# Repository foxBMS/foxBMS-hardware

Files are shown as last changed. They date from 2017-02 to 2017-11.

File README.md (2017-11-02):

# foxBMS

foxBMS is a free, open and flexible development environment to design battery
management systems. It is the first modular open source BMS development
platform.

## foxBMS Project Setup
The foxBMS project consists of several repositories.

The foxConda-installer repository contains the installer for the foxConda
environment. This environment provides all the tools necessary to generate the
documentation, compile the code for the MCUs and flash the generated binaries on
the MCUs (e.g., Python, git, GCC).

The starting point to get foxBMS is the foxBMS-setup
repository (https://github.com/foxBMS/foxBMS-setup), which contains
the general setup files for the foxBMS project. It includes a setup script
(bootstrap.py) which clones all the other needed repositories. The needed
documentation will be generated automatically after these repositories have been
cloned. The generated documentation is found in the directory ./build.
After the bootstrap step, the top project directory (foxBMS-setup) structure
looks like this:

 - foxBMS-setup <dir>
  - .git <dir> *
  - build <dir>
  - foxBMS-documentation <dir>
  - foxBMS-hardware <dir>
  - foxBMS-primary <dir>
  - foxBMS-secondary <dir>
  - foxBMS-tools <dir>
  - FreeRTOS <dir>
  - hal <dir>
  - .gitignore <file> *
  - bootstrap.py <file>
  - build.py <file>
  - CHANGELOG.md <file>
  - clean.py <file>
  - LICENSE.md <file>
  - README.md <file>
  - wscript <file>

* Directories and files with starting full stop are hidden in Windows in default
configuration.

There is a help available by running "python bootstrap.py -h".

## foxBMS Repositories

The foxConda-installer and foxBMS-setup repositories have already been described.

foxBMS is made out of two Microcontroller Units (MCU), named primary and
secondary. The C code for the primary MCU is found in the repository
foxBMS-primary (https://github.com/foxBMS/foxBMS-primary). The C code for the
secondary MCU is found in the repository foxBMS-secondary
(https://github.com/foxBMS/foxBMS-secondary). The Doxygen documentation is
generated from these sources into ./build/primary/doxygen/html and
./build/secondary/doxygen/html respectively. The main file is in both cases
index.html.

The layout and schematic files for the foxBMS hardware are found in the
foxBMS-hardware repository (https://github.com/foxBMS/foxBMS-hardware).

The Hardware Abstraction Layer (hal) for foxBMS is found in the hal-repository
(https://github.com/foxBMS/hal.) The real time operating system (FreeRTOS) for
foxBMS is found in the FreeRTOS-repository (https://github.com/foxBMS/FreeRTOS.)

The tools needed for foxBMS are in the foxBMS-tools-repository
(https://github.com/foxBMS/foxBMS-tools.)

The general documentation files for the foxBMS project are found in the
foxBMS-documentation repository
(https://github.com/foxBMS/foxBMS-documentation). The sphinx documentation is
found in foxBMS-documentation/doc/sphinx while the Doxygen documentation
configuration is found in foxBMS-documentation/doc/doxygen. The Doxygen
documentation itself is found in the software sources of the primary and
secondary microcontroller. The general documentation, rendered from the sphinx
sources is found in ./build/sphinx/foxBMS-documentation/doc/sphinx/html. The
main file is index.html

A generated version of the Sphinx documentation can be found at
http://foxbms.readthedocs.io/. It explains the structure of the
foxBMS hardware, how to install the foxConda environment and how to use foxConda
to compile and flash the sources.

## Building the Sources
For building the software, open a shell and type "python build.py -h". All
available build options will be displayed. The top build directory is ./build.

## Cleaning the ./build-Directory
For cleaning instructions open a shell and type "python clean.py -h". All
available cleaning options will be displayed.

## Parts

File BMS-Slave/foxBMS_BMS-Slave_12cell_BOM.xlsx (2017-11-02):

Pos. | Qty | Device | Package | Parts | Description | Farnell | Digi-Key
 | Resistors
1 | 12 | 0,00R_0603_R_VISHAY_REV_01 | R_SMD_0603_R_VISHAY_REV01 | R210, R212, R214, R216, R218, R220, R310, R312, R314, R316, R318, R320 | 0,00R SMD - CHIP - Dickschichtwiderstand | 1469739
2 | 2 | 1,21K_0603_R_VISHAY_1%_TK100_REV_01 | R_SMD_0603_R_VISHAY_REV01 | R208, R308 | 1,21K SMD - CHIP - Dickschichtwiderstand | 1652852
3 | 36 | 10,0K_0603_R_VISHAY_1%_TK100_REV_01 | R_SMD_0603_R_VISHAY_REV01 | R813, R901, R902, R903, R904, R905, R906, R907, R908, R1001, R1002, R1003, R1004, R1005, R1006, R1007, R1008, R1101, R1102, R1103, R1104, R1105, R1106, R1107, R1108, R1201, R1202, R1203, R1204, R1205, R1206, R1207, R1208, R1301, R1401, R1606 | 10,0K SMD - CHIP - Dickschichtwiderstand | 1469748
4 | 4 | 100R_0805_R_VISHAY_1%_TK100_REV_01 | R_SMD_0805_R_VISHAY_REV01 | R202, R203, R302, R303 | 100R SMD - CHIP - Dickschichtwiderstand | 1469862
5 | 30 | 100R_0603_R_VISHAY_1%_TK100_REV_01 | R_SMD_0603_R_VISHAY_REV01 | R501, R502, R503, R504, R505, R506, R507, R508, R509, R510, R511, R512, R513, R601, R602, R603, R604, R605, R606, R607, R608, R609, R610, R611, R612, R613, R909, R910, R1009, R1010 | 100R SMD - CHIP - Dickschichtwiderstand | 1469752
6 | 4 | 120R_0603_R_VISHAY_1%_TK100_REV_01 | R_SMD_0603_R_VISHAY_REV01 | R204, R207, R304, R307 | 120R SMD - CHIP - Dickschichtwiderstand | 1652832
7 | 12 | 150R_0603_R_VISHAY_1%_TK100_REV_01 | R_SMD_0603_R_VISHAY_REV01 | R801, R802, R803, R804, R805, R806, R807, R808, R809, R810, R811, R812 | 150R SMD - CHIP - Dickschichtwiderstand | 1469760
8 | 2 | 1,00M_0603_R_VISHAY_1%_TK100_REV_01 | R_SMD_0603_R_VISHAY_REV01 | R219, R319 | 1,00M SMD - CHIP - Dickschichtwiderstand | 1469746
9 | 2 | 330R_0603_R_VISHAY_1%_TK100_REV_01 | R_SMD_0603_R_VISHAY_REV01 | R205, R305 | 330R SMD - CHIP - Dickschichtwiderstand | 2141320
10 | 12 | 3,30K_0603_R_VISHAY_1%_TK100_REV_01 | R_SMD_0603_R_VISHAY_REV01 | R713, R714, R715, R716, R717, R718, R731, R732, R733, R734, R735, R736 | 3,30K SMD - CHIP - Dickschichtwiderstand | 1469793
11 | 4 | 1,20K_0603_R_VISHAY_1%_TK100_REV_01 | R_SMD_0603_R_VISHAY_REV01 | R222, R223, R322, R323 | 1,20K SMD - CHIP - Dickschichtwiderstand | 1469741
12 | 24 | 68,0R_2010_R_YAGEO_5%_TK100_REV_01 | R_SMD_2010_R_YAGEO_REV01 | R701, R702, R703, R704, R705, R706, R707, R708, R709, R710, R711, R712, R719, R720, R721, R722, R723, R724, R725, R726, R727, R728, R729, R730 | 68,0R SMD - CHIP - Dickschichtwiderstand | 2323988
13 | 2 | 820R_0603_R_VISHAY_1%_TK100_REV_01 | R_SMD_0603_R_VISHAY_REV01 | R206, R306 | 820R SMD - CHIP - Dickschichtwiderstand | 1469841
14 | 1 | 390K_0603_R_VISHAY_1%_TK100_REV_01 | R_SMD_0603_R_VISHAY_REV01 | R1601 | 390K SMD - CHIP - Dickschichtwiderstand | 2303278
15 | 1 | 86,6K_0603_R_VISHAY_1%_TK100_REV_01 | R_SMD_0603_R_VISHAY_REV01 | R1602 | 86,6K SMD - CHIP - Dickschichtwiderstand | 2059490
16 | 1 | 39,0R_0805_R_VISHAY_1%_TK100_REV_01 | R_SMD_0805_R_VISHAY_REV01 | R1603 | 39,0R SMD - CHIP - Dickschichtwiderstand | 1750736
17 | 1 | 127K_0603_R_VISHAY_1%_TK100_REV_01 | R_SMD_0603_R_VISHAY_REV01 | R1605 | 127K SMD - CHIP - Dickschichtwiderstand | 2059500
18 | 2 | 0,00R_0805_R_VISHAY_REV_01 | R_SMD_0805_R_VISHAY_REV01 | R201, R301 | 0,00R SMD - CHIP - Dickschichtwiderstand | 2057661
 | Capacitors
19 | 4 | 100NF_0805_100V_X7R_MULTICOMP | C_SMD_0805_(2012)_R_MULTICOMP_REV01 | C201 C202 C301 C302 | 100nF Keramik-Kondensator | 2320821
20 | 18 | 100NF_0603_16V_X7R_KEMET | C_SMD_0603_(1608)_R_KEMET_REV01 | C801, C901, C1001, C1101, C1201, C1301, C1302, C1401, C1402, C1501, C1502, C1503, C1504, C1505, C1506, C1507, C1508, C1604 | 100nF Keramik-Kondensator | 2581045
21 | 4 | 100PF_0603_50V_C0G_KEMET | C_SMD_0603_(1608)_R_KEMET_REV01 | C204, C207, C304, C307 | 100pF Keramik-Kondensator | 1414603
22 | 28 | 10,0NF_0603__100V_X7R_KEMET | C_SMD_0603_(1608)_R_KEMET_REV01 | C501, C502, C503, C504, C505, C506, C513, C514, C515, C516, C517, C518, C601, C602, C603, C604, C605, C606, C613, C614, C615, C616, C617, C618, C904, C905, C1004, C1005 | 10,0nF Keramik-Kondensator | 1865545
23 | 17 | 1,00µF_0603_16V_X7R_KEMET | C_SMD_0603_(1608)_R_KEMET_REV01 | C203, C205, C206, C303, C305, C306, C902, C903, C906, C907, C908, C1002, C1003, C1006, C1007, C1008, C1605 | 1,00µF Keramik-Kondensator | 1650837
24 | 1 | 1,00µF_0805_50V_X7R_KEMET | C_SMD_0805_(2012)_R_KEMET_REV01 | C1601 | 1,00µF Keramik-Kondensator | 2118131
25 | 2 | 10µF_1210_50V_X7R | 1210 | C1602, C1603 | 10µF Keramik-Kondensator | 2449143
26 | 1 | 470PF_0805_50V_X7R_KEMET | C_SMD_0805_(2012)_R_KEMET_REV01 | C1606 | 470pF Keramik-Kondensator | 1759283
27 | 1 | 4,7NF_1812_1kV | 1812 | C1607 | 4,7nF Keramik-Kondensator | 1702159
28 | 3 | 4,70µF_1206_100V_X7R_KEMET | C_SMD_1206_(3216)_R_KEMET_REV01 | C1608, C1609, C1610 | 4,70µF Keramik-Kondensator |  | 478-8719-1-ND
 | ICs
29 | 2 | M24M02-DR | SOIC127P600X175-8N | IC1301, IC1401 | EEPROM |  | 497-16238-1-ND
30 | 3 | ACPL-247-500E | OC_SMD_SOIC-16_R_AVAGO_REV01 | IC801, IC802, IC803 | ACPL-247 - AVAGO | 1634758
31 | 2 | PCA8574TS/3 | SOP65P640X150-20N | IC1101, IC1201 | IC, I/O EXPANDER, 8BIT, I2C, 20SSOP | 1506642
32 | 6 | ADG728BRUZ | IC_SMD_TSSOP-16 | IC901, IC902, IC905, IC1001, IC1002, IC1005 | ADG728BRUZ | 9604383
33 | 4 | LTC6255CS6 | IC_SMD_TSOT-23-6_(S6)_R_LINEAR_REV01 | IC903, IC904, IC1003, IC1004 | LTC6255 Serie - Linear |  | LTC6255CS6#TRMPBFCT-ND
34 | 2 | MCP9800A0T-M/OT | SOT95P280X145-5N | IC1302 IC1402 | Temperature Sensor | 1439485
35 | 2 | 0_LES_BATTERIE-MANAGEMENT.SMD_LTC6811HG-1 | 0_LES_BATTERIE-MANAGEMENT.SMD_IC_SMD_SSOP-48_(G48)_R_LINEAR_REV01 | IC201 IC301 | LTC6811-1 - Linear Technology |  | LTC6811HG-1#PBF-ND
36 | 1 | LT8302 | S8E | IC1601 | LT8302 | 2366012
 | Diodes
37 | 24 | MMSZ4692_T1G | D_SMD_SOD-123_R_ON_REV01 | Z501, Z502, Z503, Z504, Z505, Z506, Z507, Z508, Z509, Z510, Z511, Z512, Z601, Z602, Z603, Z604, Z605, Z606, Z607, Z608, Z609, Z610, Z611, Z612 | MMSZ4xxxT1G Serie - ON Semiconductor | 2463562
38 | 1 | BAT54C | D_SMD_SOT23_(TO-236AB)_R_NXP_REV01 | D801 |  | 1081192
39 | 2 | LEDCHIP-LED0603 | CHIP-LED0603 | LD201 LD301 | LED | 2099223
40 | 2 | SMAJ60CA_VISHAY | D_SMD_SMA_(DO-214AC)_(BIDIR)_R_VISHAY_REV01 | D202, D302 | SMAJ bi-directional Transient Voltage Suppressors | 1837055
41 | 1 | DI_PDS3200 | POWER_DI_5 | D1604 | Schottky Diode | 1713904
42 | 1 | MMSZ5263B | SOD123 | D1605 | Zener Diode |  | MMSZ5263BT1GOSCT-ND
43 | 3 | DI_DFLS1100 | POWER_DI_123 | D201, D301, D1601 | Schottky Diode | 1713889
 | Transistors
44 | 12 | NX2301P,215 | D_SMD_SOT23_(TO-236AB)_R_NXP_REV01 | T701, T702, T703, T704, T705, T706, T707, T708, T709, T710, T711, T712 | NX2301P - NXP | 1894738
45 | 2 | PBHV8115Z | D_SMD_SOT223_(SC-73)_R_NXP_REV01 | T201 T301 | PBHV8115Z - NXP | 1829309
 | Misc
46 | 2 | Pulse HM2102NL | HM2102NL | TR201, TR301 | HM2102NL
47 | 1 | WE_750313457 | WUERTH_CUSTOM | TR1601 | WE_750313457 Flyback Transformer |  | 1297-1136-1-ND
48 | 6 | CUSTOM_PAD_PAD_2.0X1.5MM | CUSTOM_PAD_PAD2.0X1.5MM | TP206, TP209, TP210, TP306, TP309, TP310 | Harwin SMD Test Points |  | 952-2664-1-ND
49 | 13 | 0,250A_LITTELFUSE_466_1206 | R_SMD_CHIP_1206_R_LITTLEFUSE_REV_01 | F402, F403, F404, F405, F406, F407, F408, F409, F410, F411, F412, F413, F414 | LITTELFUSE 0466.250NR SICHERUNG, 0.25A | 9921826
50 | 2 | 0,500A_LITTELFUSE_448 | 448_SERIES_LITTELFUSE | F401 F415 | LITTELFUSE 0448.500MR SICHERUNG, 500MA | 1596919
51 | 1 | 1,25A_LITTELFUSE_466_1206 | 1,25A_LITTELFUSE_466_1206 | R_SMD_CHIP_1206_R_LITTLEFUSE_REV_01 | F1601 | 1596526
52 | 1 | WE-74404042100 | WE-LQS | L1601 | Inductor | 2431496
 | Connectors
53 | 6 | 43045-0200_MOLEX_2PIN | X_TH_MOLEX_43045-0200_R_REV01 | X1509, X1510, X1511, X1512, X1513, X1514 | 43045-Serie - MOLEX | 1012251
54 | 2 | 43045-1600_MOLEX_16PIN | X_TH_MOLEX_43045-1600_R_REV01 | X1506 X1507 | 43045-Serie - MOLEX | 9961380
55 | 1 | 43045-2400_MOLEX_24PIN | X_TH_MOLEX_43045-2400_R_REV01 | X1503 | 43045-Serie - MOLEX | 1012245
56 | 2 | MA05-2 | MA05-2 | X1504, X1505 | PIN HEADER | 2578720
57 | 2 | MA09-2 | MA09-2 | X1501, X1502 | PIN HEADER | 2025256
58 | 1 | MA10-2 | MA10-2 | X1508 | PIN HEADER | 2025257
59 | 1 | MA02-2 | MA02-2 | X1515 | PIN HEADER | 2025248

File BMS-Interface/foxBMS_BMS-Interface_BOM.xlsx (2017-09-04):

Populate | Qty | Value | Device | Package | Parts | Description | Farnell | Digikey | Mouser
no | 2 |  | HEADER_POS4_43045-0406 | 43045-0406 | X1, X2 | Molex - Micro-Fit 3.0 Series connector, 3.00mm (0.118) pitch header, 4 positions." | 2063766
yes | 2 |  | SSW-104-01-G-D | 2x 04 | X5, X6 | PIN HEADER | 1668340
yes | 2 |  | SSW-102-01-G-D | 2x 02 | X3, X4 | PIN HEADER | 1668329
yes | 4 | 100n | C_0603 | 603 | C301, C302, C401, C402 | Capacitor | 1828890
yes | 8 | 0R | R_0603 | 603 | R302, R304, R305, R310, R402, R404, R405, R410 | Resistor | 2059527
yes | 2 | 1.21k | R_0603 | 603 | R312, R412 | Resistor | 2059331
yes | 2 | 120 | R_0603 | 603 | R501, R502 | Resistor | 2303067
yes | 2 | 27pF | C_0603 | 603 | C502, C504 | Capacitor | 1414627
yes | 4 | 2k | R_0603 | 603 | R307, R308, R407, R408 | Resistor | 2059343
yes | 2 | 806 | R_0603 | 603 | R311, R411 | Resistor | 2059324
yes | 2 | HM2102NL | HM2102NL | HM2102NL | T501, T502
yes | 2 | LTC6820 | LTC6820 | MSOP16 | IC301, IC401 |  |  | LTC6820HMS#PBF-ND
no | 8 | OPT: 0R | R_0603 | 603 | R301, R303, R306, R309, R401, R403, R406, R409 | Resistor | 2059527

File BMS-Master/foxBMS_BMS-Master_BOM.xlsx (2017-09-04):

 | Pos | Populate | Qty | Value | Device | Package | Parts | Description | Farnell | Digikey | Mouser
Resistor
 | 1 | yes | 9 | 0 | R-EU_R0603 | R0603 | R403 R406 R501 R506 R705 R1403 R1404 R1407 R1408 | RESISTOR, European symbol | 2059527
 | 2 | yes | 2 | 1.5k | R-EU_R0603 | R0603 | R701 R702 | RESISTOR, European symbol | 2303156
 | 3 | yes | 12 | 10 | R-EU_R0603 | R0603 | R706 R901 R905 R909 R912 R1001 R1002 R1007 R1008 R1013 R1014 R806 | RESISTOR, European symbol | 2302958
 | 4 | yes | 32 | 10k | R-EU_R0603 | R0603 | R401 R402 R405 R407 R502 R504 R505 R507 R707 R708 R709 R710 R903 R904 R908 R911 R1003 R1004 R1009 R1010 R1015 R1016 R1107 R1108 R1109 R1110 R1111 R1112 R1501 R1502 R803 R805 | RESISTOR, European symbol | 2303192
 | 5 | yes | 1 | 120 | R-EU_R0603 | R0603 | R902 | RESISTOR, European symbol | 2303067
 | 6 | yes | 6 | 130 | R-EU_R0603 | R0603 | R201 R301 R408 R409 R508 R509 | RESISTOR, European symbol | 2059288
 | 7 | yes | 8 | 430 | R-EU_R0603 | R0603 | R907 R910 R1005 R1006 R1011 R1012 R1017 R1018 R804 | RESISTOR, European symbol | 2145386
 | 8 | yes | 1 | 330 | R-EU_R0603 | R0603 | R906 | RESISTOR, European symbol | 2145370
 | 9 | yes | 4 | 27 | R-EU_R0603 | R0603 | R1401 R1402 R1405 R1406 | RESISTOR, European symbol | 2145363
 | 10 | yes | 6 | 47 | R-EU_R0603 | R0603 | R1101 R1102 R1103 R1104 R1105 R1106 | RESISTOR, European symbol | 2145397
 | 11 | yes | 2 | 62 | R-EU_R0603 | R0603 | R801 R802 | RESISTOR, European symbol | 2303039
 | 12 | yes | 4 | 680 | R-EU_R0603 | R0603 | R404 R503 R703 R704 | RESISTOR, European symbol | 2303131
Capacitor
 | 13 | yes | 74 | 100n | C-EUC0603 | C0603 | C202 C206 C208 C301 C306 C308 C401 C404 C405 C406 C407 C408 C409 C410 C411 C412 C413 C415 C416 C417 C418 C419 C420 C421 C422 C424 C425 C430 C502 C503 C504 C506 C507 C508 C509 C510 C513 C601 C602 C703 C706 C707 C1103 C1104 C1105 C1106 C1107 C1402 C1403 C1404 C1405 C1407 C1408 C1409 C1410 C1601 C1602 C1603 C1604 C1801 C1802 C1803 C1804 C1805 C1806 C1807 C2101 C2102 C803 C804 C805 C806 C807 C1501 | CAPACITOR, European symbol | 1828890
 | 14 | yes | 4 | 100n 50V | C-EUC0604 | C0603 | C702 C802 C902 C1102 | CAPACITOR, European symbol | 2346967
 | 15 | yes | 8 | 18p | C-EUC0605 | C0603 | C402 C414 C428 C429 C501 C505 C704 C705 | CAPACITOR, European symbol | 2070403
 | 16 | yes | 6 | 1µ | C-EUC0606 | C0603 | C205 C207 C305 C307 C403 C423 | CAPACITOR, European symbol | 1907343
 | 17 | yes | 3 | 1µ 35V | C-EUC0607 | C0603 | C701 C801 C1101 | CAPACITOR, European symbol | 2346909
 | 18 | yes | 4 | 2.2µ | C-EUC0608 | C0603 | C426 C427 C511 C512 | CAPACITOR, European symbol | 2346961
 | 19 | yes | 7 | 2.2µ 50V | C-EUC0609 | C0805 | C201 C203 C204 C302 C303 C304 C901 | CAPACITOR, European symbol | 2346945
 | 20 | yes | 2 | 4.7µ | C-EUC0610 | C0603 | C1401 C1406 | CAPACITOR, European symbol | 2362098
L
 | 21 | yes | 1 |  | L0805 | 0805 | L401 |  | 2443249
 | 22 | yes | 1 |  | B82789N | B82789N | L801 |  |  |  | 871-B82789C513N2
LED
 | 23 | yes | 2 | Green | LEDCHIP-LED0603 | CHIP-LED0603 | LED402 LED502 | LED | 2099223
 | 24 | yes | 2 | Red | LEDCHIP-LED0603 | CHIP-LED0603 | LED401 LED501 | LED | 2099221
 | 25 | yes | 2 | Orange | LEDCHIP-LED0603 | CHIP-LED0603 | LED201 LED301 | LED | 2099222
XTAL
 | 26 | yes | 2 | 7B-8.000MAAJ-T | 7B-8.000MAAJ-T | MJ | Q401 Q501 | MJ Quarz, 5 x 3.2 x 1.0mm SMD | 2308726
 | 27 | yes | 1 |  | MS3V | MS3V-T1R | Q402 |  | 1539368
Transistor
 | 28 | yes | 2 | BSS84P | BSS84P | SOT23 | T401 T501 | #2245 | 1056526
 | 29 | yes | 1 | BUK964R8-60E | BUK964R8-60E | TO-263AB | T901 | #2797 N-Channel PowerTrench MOSFET 60V, 75A 10.5mOhm | 2254205
 | 30 | yes | 10 | IRLML0100TRPBF | IRLML0100TRPBF | SOT-23 | T701 T801 T902 T903 T1001 T1002 T1003 T1004 T1005 T1006 |  | 1783928
IC
 | 31 | yes | 1 | ADR3425 | ADR3425 | SOT23-6 | IC401 | Micropower, high accuracy, voltage references | 2377039
 | 32 | yes | 2 | ADUM3300 | ADUM3300 | SO-16W | IC1102 IC1103 | Triple-Channel Digital Isolators | 2409432
 | 33 | yes | 1 | ADUM3301 | ADUM3301 | SO-16W | IC702 | Triple-Channel Digital Isolators | 2462515
 | 34 | yes | 3 | ADUM3401 | ADUM3401 | SO16W | IC601 IC1403 IC1406 | Analog Devices Magnetkoppler 4-Kanal | 1274129
 | 35 | yes | 2 | FT231XS-R | FT231XS-R | IC_SMD_SSOP-20 | IC1402 IC1405 | FT231X?-* - FTDI | 2081328
 | 36 | yes | 1 | AT25128B-SSHL-T | AT25128B-SSHL-T | SO8 | IC1501 | SPI bus serial EEPROM | 2345601
 | 37 | yes | 1 | TJA1052IT/5Y | TJA1052IT/5Y | SO16W | IC802 |  | 2400552
Diode
 | 38 | yes | 1 | PESD1CAN | PESD1CAN | SOT-23_NEU | D801 | NXP PESD1CAN CAN bus ESD protection diode | 1510703
 | 39 | yes | 1 | STPS3L60U | STPS3L60U | SMB | D201 | Schottky Diode | 9907769
 | 40 | yes | 2 | MM3Z12VT1G | MM3Z12VT1G | SOD323 | D901 D902 | MM3Z_xVx_T1 Series Zener Diode | 1431191
 | 41 | yes | 6 | CDSOD323-T05 | CDSOD323-T05 | SOD323 | D1101 D1102 D1103 D1104 D1105 D1106 | TVS CDSOD323-T05 | 2341914
 | 42 | yes | 2 | MM3Z4V7ST1G | MM3Z4V7ST1G | SOD323 | D701 D702 | MM3Z_xVx_T1 Series Zener Diode | 2463512
 | 43 | no | 6 | GF1B | GF1B | SMA-DO214AC | D1001 D1002 D1003 D1004 D1005 D1006 | DIODE | 1467477
MCU
 | 44 | yes | 1 | STM32F429IIT6 | STM32F429IIT6 | LQFP176 | IC402 | ARM 32-bit Cortex™-M3 CPU |  | 497-14054-ND
 | 45 | yes | 1 | STM32F429VIT6 | STM32F429VGT6 | LQFP100 | IC501 | ARM 32-bit Cortex™-M3 CPU | 2393659
Regulator
 | 46 | yes | 1 | KA7805ERTF | KA7805ERTF | TO252 | IC801 | Positive VOLTAGE REGULATOR | 2102585
 | 47 | yes | 2 | UA78L05CPK | UA78L05CPK | SOT89 | IC701 IC1101 | POSITOIV-VOLTAGE REGULATORS | 2112604
 | 48 | yes | 2 | LM1085-3.3 | LM1085-3.3 | TO-263-3L | IC201 IC301 | National Semiconductor LM1085IS-5 3A Low Dropout Positive Regulators | 1469039
 | 49 | yes | 1 | LM317MSTT3 | LM317MSTT3 | SOT223 | IC901 | 500 mA Adjustable Output Positive Voltage Regulator | 1703412
Opto
 | 50 | yes | 6 | AQV252G2SX | AQV252G2SX | SOP06 | IC1001 IC1002 IC1003 IC1004 IC1005 IC1006 |  |  | 255-3594-1-ND
 | 51 | yes | 5 | CPC1008N | CPC1008N | SOP4 | IC803 IC902 IC903 IC904 IC905 | CLARE - Single-Pol, Normally Open 4-Pin SOP OptoMOS Relay, 150mA load current | 1653755
Misc
 | 52 | yes | 1 | SMTU 1225-1-LF | SMTU 1225-1-LF | CR1225_SMD | BATT | #2833 | 1216353
 | 53 | yes | 2 | MC32598 | MC32598 | Mini-USB AB | X1401 X1402 | MINI USB-B Conector | 1696539
 | 54 | yes | 2 | IP4220CZ6 | IP4220CZ6 | TSOP-6 | IC1401 IC1404 |  | 1506629
 | 55 | yes | 1 | IS42S16400J-7TLI | IS42S16400J-7TLI | TSOP-54 | IC1801 |  | 2253831
 | 56 | yes | 2 | KMR211G | KMR211G | KMR211G | S401 S501 | #228 |  | 401-1426-1-ND
 | 57 | yes | 6 | 630MA_UMT | 630MA_UMT | F_SMD_11,00MMX3,00MMX3,00MM_(UMT)_R_SCHURTER_REV01 | F1001 F1002 F1003 F1004 F1005 F1006 | UMT-Serie - Schurter Electronic Components |  | 486-2077-ND | 693-3403.0164.11
 | 58 | yes | 1 | 2A | Littelfuse 452 | NANO2 | F201 | 452 Serie Littelfuse | 2383284
 | 59 | yes | 1 | TISP4040H1BJR-S | TISP4040H1BJR-S | SMBJ | T201 | TVS Thyristor |  | TISP4040H1BJR-SCT-ND
Connector SMD
 | 60 | yes | 2 | FTS-110-01-L-DV | FTS-110-01-L-DV | FTS-110-01-L-DV | X403 X502 | SAMTEC connector, #537 | 1667733
Connector THD
 | 61 | yes | 1 | HEADER_POS16_43045-1599 | HEADER_POS16_43045-1600 | 43045-1600 | X1601 | Molex - Micro-Fit 3.0 Series connector, 3.00mm (0.118) pitch header, 16 positions." | 9961380
 | 62 | yes | 1 | HEADER_POS2_43045-0199 | HEADER_POS2_43045-0200 | 43045-0200 | X901 | Molex - Micro-Fit 3.0 Series connector, 3.00mm (0.118) pitch header, 2 positions." | 1012251
 | 63 | yes | 8 | HEADER_POS4_43045-0400 | HEADER_POS4_43045-0401 | 43045-0400 | X701 X801 X1201 X1202 X1203 X1204 X1205 X1206 | Molex - Micro-Fit 3.0 Series connector, 3.00mm (0.118) pitch header, 4 positions." | 9733019
 | 64 | yes | 1 | HEADER_POS6_43045-0599 | HEADER_POS6_43045-0600 | 43045-0600 | X201 | Molex - Micro-Fit 3.0 Series connector, 3.00mm (0.118) pitch header, 6 positions." | 1012252
 | 65 | yes | 1 | MA03-0 | MA03-1 | MA03-1 | X401 | 3Pins | 2505045
 | 66 | yes | 1 |  |  |  | SV901 | 8 Header | 1668094
 | 67 | yes | 3 | MA04-1 | MA04-2 | MA04-2 | SV1601 SV1603 SV2101 | 8 Pins | 2025250
 | 68 | yes | 1 | MA06-1 | MA06-2 | MA06-2 | SV501 | 12 Pins | 2025252
 | 69 | yes | 2 | MA08-1 | MA08-2 | MA08-2 | SV1602 SV1604 | 16 Pins | 2025254
 | 70 | no | 1 | MA02-0 | MA02-0 | MA02-0 | X902 | 1 Pins | 2505044
 | 71 | yes | 2 | MA02-1 | MA02-1 | MA02-1 | X402 X501 | 2 Pins | 2505044
 | 72 | yes | 2 | PINHD-2X11 | PINHD-2X12 | 2X12 | JP2201 JP2202 | 24 Header | 1804783 | SAM1088-12-ND
DC/DC THD
 | 73 | yes | 1 | MURATA_NCS6_SINGLE | MURATA_NCS6_SINGLE | NCS6S1205C | IC202 |  |  | 580-NCS6S1205C
 | 74 | yes | 1 | RECOM-RS2405SZ | RECOM-RS2405SZ | RS-2405SZ/H3 | IC302 |  |  | 919-RS-2405SZ/H3

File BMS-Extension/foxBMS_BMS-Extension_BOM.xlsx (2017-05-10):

Populate | Qty | Value | Device | Package | Parts | Description | Farnell | Digikey | Mouser
 | Resistor
yes | 5 | 0 | R_MET_0603 | 0603 | R1701 R1703 R1705 R1707 R1709 | Resistor | 2059527
yes | 11 | 10 | R_MET_0603 | 0603 | R902 R1001 R1004 R1007 R2001 R2002 R2007 R2008 R2013 R2014 R806 | Resistor | 2302958
yes | 25 | 10k | R_MET_0603 | 0603 | R901 R1002 R1005 R1008 R1104 R1105 R1106 R1502 R1503 R1504 R1505 R1506 R1507 R1903 R1904 R1907 R1908 R2003 R2004 R2009 R2010 R2015 R2016 R803 R805 | Resistor | 2303192
yes | 5 | 4.75k | R_MET_0603 | 0603 | R1702 R1704 R1706 R1708 R1710 | Resistor | 2094611
yes | 10 | 430 | R_MET_0603 | 0603 | R1003 R1006 R1009 R2005 R2006 R2011 R2012 R2017 R2018 R804 | Resistor | 2145386
yes | 1 | 47k | R_MET_0603 | 0603 | R1501 | Resistor | 2303213
yes | 7 | 47 | R_MET_0603 | 0603 | R1101 R1102 R1103 R1901 R1902 R1905 R1906 | Resistor | 2145397
yes | 2 | 62 | R_MET_0603 | 0603 | R801 R802 | Resistor | 2303039
 | Capacitor
yes | 4 | 100n 50V | C_NP0_0603 | 0603 | C1901 C802 C1101 C1302 | Capacitor | 2346967
yes | 26 | 100n | C_X7R_0603 | 0603 | C803 C804 C805 C806 C807 C1103 C1104 C1105 C1106 C1303 C1304 C1305 C1306 C1701 C1702 C1704 C1705 C1706 C1707 C1708 C1903 C1904 C1905 C1906 C1907 C1501 | Capacitor | 1828890
yes | 3 | 1µ | C_X7R_0603 | 0603 | C1703 C1902 C1502 | Capacitor | 1907343
yes | 3 | 1µ 35V | C_X7R_0603 | 0603 | C801 C1102 C1301 | Capacitor | 2346909
 | Testpad
no | 44 | PAD_2.0X1.5MM | PAD_2.0X1.5MM | PAD2.0X1.5MM | LSP801 LSP802 LSP803 LSP804 LSP805 LSP806 LSP807 LSP901 LSP1001 LSP1002 LSP1003 LSP1101 LSP1102 LSP1103 LSP1301 LSP1302 LSP1303 LSP1304 LSP1501 LSP1502 LSP1503 LSP1504 LSP1505 LSP1701 LSP1702 LSP1703 LSP1704 LSP1705 LSP1901 LSP1902 LSP1903 LSP1904 LSP1905 LSP1906 LSP1907 LSP1908 LSP2001 LSP2002 LSP2003 LSP2004 LSP2005 LSP2006 LSP2101 LSP2102 | Testpoint |  | 952-2664-1-ND
 | L
yes | 1 |  | B82789N | B82789*N | L801 |  |  |  | 871-B82789C513N2
yes | 1 | 22u | L1210 | L1210 | L1501 |  | 2443249
 | Diode
yes | 5 | MM3Z3V3ST1G | MM3Z_XVX_T1 | SOD323 | D1701 D1702 D1703 D1704 D1705 | MM3Z_xVx_T1 Series Zener Diode |  | MM3Z3V3ST1GOSCT-ND
yes | 7 | CDSOD323-T05 | CDSOD323-T05 | SOD323 | D1101 D1102 D1103 D1901 D1902 D1903 D1904 | TVS CDSOD323-T05 | 2341914
yes | 1 | PESD1CAN | PESD1CAN | SOT-23_NEU | D801 | NXP PESD1CAN CAN bus ESD protection diode | 1510703
no | 9 |  | DIODE-DO214BA | DO214BA | D1001 D1002 D1003 D2001 D2002 D2003 D2004 D2005 D2006 | DIODE | 1467477
 | Transistor
yes | 1 | BSS84P | BSS84P | SOT23 | T1501 | #2245 | 1056526
yes | 1 | BUK964R8-60E | BUK964R8-60E | TO-263AB | T901 | #2797 N-Channel PowerTrench MOSFET 60V, 75A 10.5mOhm | 2254205
yes | 10 | IRLML0100TRPBF | IRLML0100TRPBF | SOT-23 | T801 T1001 T1002 T1003 T2001 T2002 T2003 T2004 T2005 T2006 |  | 1783928
 | IC
yes | 1 | ADR3425ARJZ | ADR3425ARJZ | SOT23-6 | IC1701 | Micropower, high accuracy, voltage references | 2377039
yes | 1 | ADUM3300 | ADUM3300 | SO-16W | IC1102 | Triple-Channel Digital Isolators | 2409432
yes | 1 | ADUM3401 | ADUM3401 | SO16W | IC1303 | Analog Devices Magnetkoppler 4-Kanal | 1274129
yes | 2 | ADUM3402 | ADUM3402 | SO16W | IC1902 IC1903 | Analog Devices Magnetkoppler 4-Kanal | 1274127
yes | 1 | LT1785CS8#PBF | LT1785CS8#PBF | SOIC8 | IC1302 | Low Power RS485 Interface Transceiver | 1663498
yes | 1 | TJA1052IT/5Y | TJA1052IT/5Y | SO16W | IC803 |  | 2400552
 | Opto
yes | 9 | AQV252G2SX | AQV252G2SX | SOP06 | IC1001 IC1002 IC1003 IC2001 IC2002 IC2003 IC2004 IC2005 IC2006 |  |  | 255-3594-1-ND
yes | 1 | CPC1008N | CPC1008N | SOP4 | IC802 | CLARE - Single-Pol, Normally Open 4-Pin SOP OptoMOS Relay, 150mA load current | 1653755
 | Regulator
yes | 1 | KA7805ERT | KA7805ERT | TO252 | IC801 | Positive VOLTAGE REGULATOR | 2102585
yes | 3 | UA78L05CPK | UA78L05CPK | SOT89 | IC1101 IC1301 IC1901 | POSITOIV-VOLTAGE REGULATORS | 2112604
 | Misc
yes | 1 |  | 47352-1001 | 47352-1001 | SD-Micro SLOT |  | 2424133
yes | 3 | 630MA_UMT | 630MA_UMT | F_SMD_11,00MMX3,00MMX3,00MM_(UMT)_R_SCHURTER_REV01 | F1001 F1002 F1003 | UMT-Serie - Schurter Electronic Components |  | 486-2077-ND | 693-3403.0164.11
 | Connector THD
yes | 1 |  | HEADER_POS10_43045-1000 | 43045-1000 | X1901 | Molex - Micro-Fit 3.0 Series connector, 3.00mm (0.118) pitch header, 10 positions." | 1012255
yes | 2 |  | HEADER_POS12_43045-1200 | 43045-1200 | X1701 X2001 | Molex - Micro-Fit 3.0 Series connector, 3.00mm (0.118) pitch header, 12 positions." | 9732977
yes | 4 |  | HEADER_POS4_43045-0400 | 43045-0400 | X801 X1201 X1202 X1203 | Molex - Micro-Fit 3.0 Series connector, 3.00mm (0.118) pitch header, 4 positions." | 9733019
yes | 1 |  | HEADER_POS6_43045-0600 | 43045-0600 | X1301 | Molex - Micro-Fit 3.0 Series connector, 3.00mm (0.118) pitch header, 6 positions." | 1012252
yes | 1 |  | MA04-2 | MA04-2 | SV901 | PIN HEADER |  | SAM1096-04-ND
no | 1 |  |  |  | SV2101 |  | 2025250
yes | 2 |  | PINHD-2X12 | 2X12 | JP2201 JP2202 | PIN HEADER |  | SAM1096-12-ND

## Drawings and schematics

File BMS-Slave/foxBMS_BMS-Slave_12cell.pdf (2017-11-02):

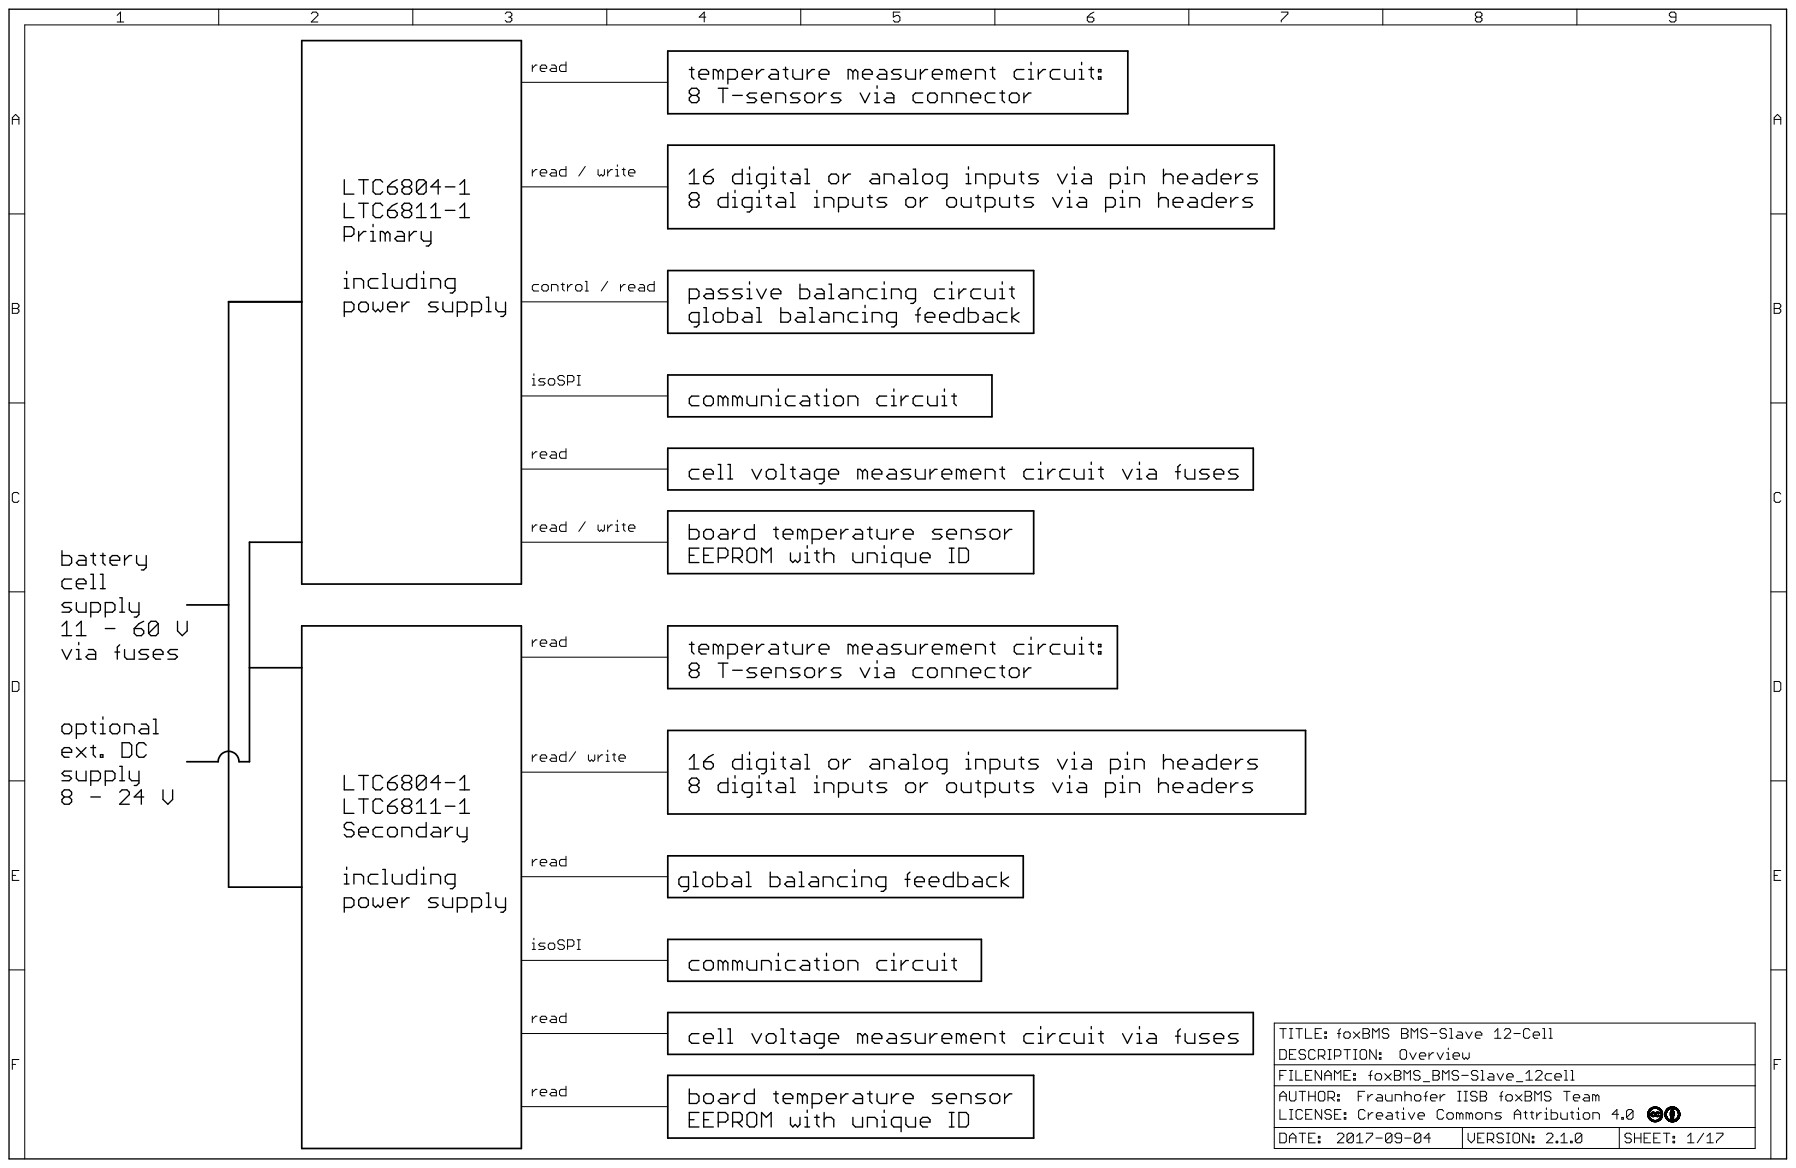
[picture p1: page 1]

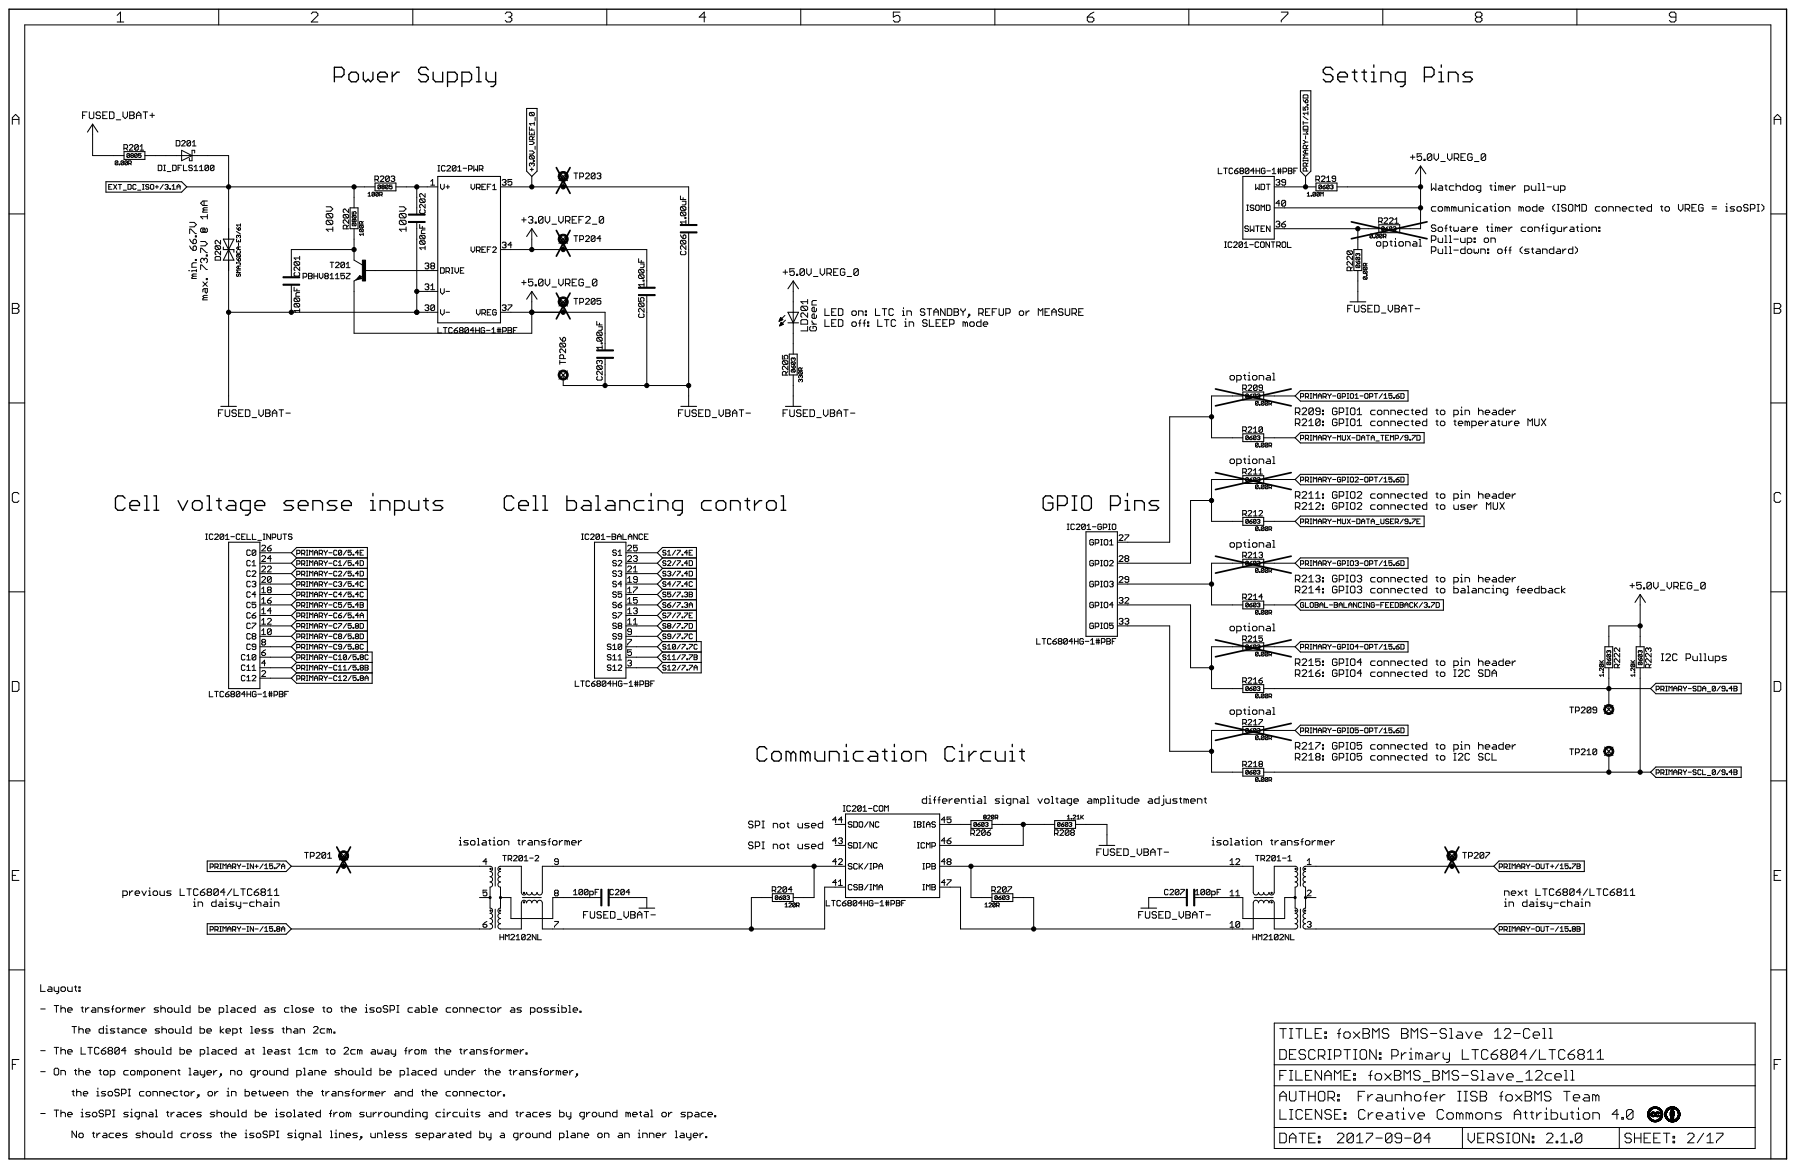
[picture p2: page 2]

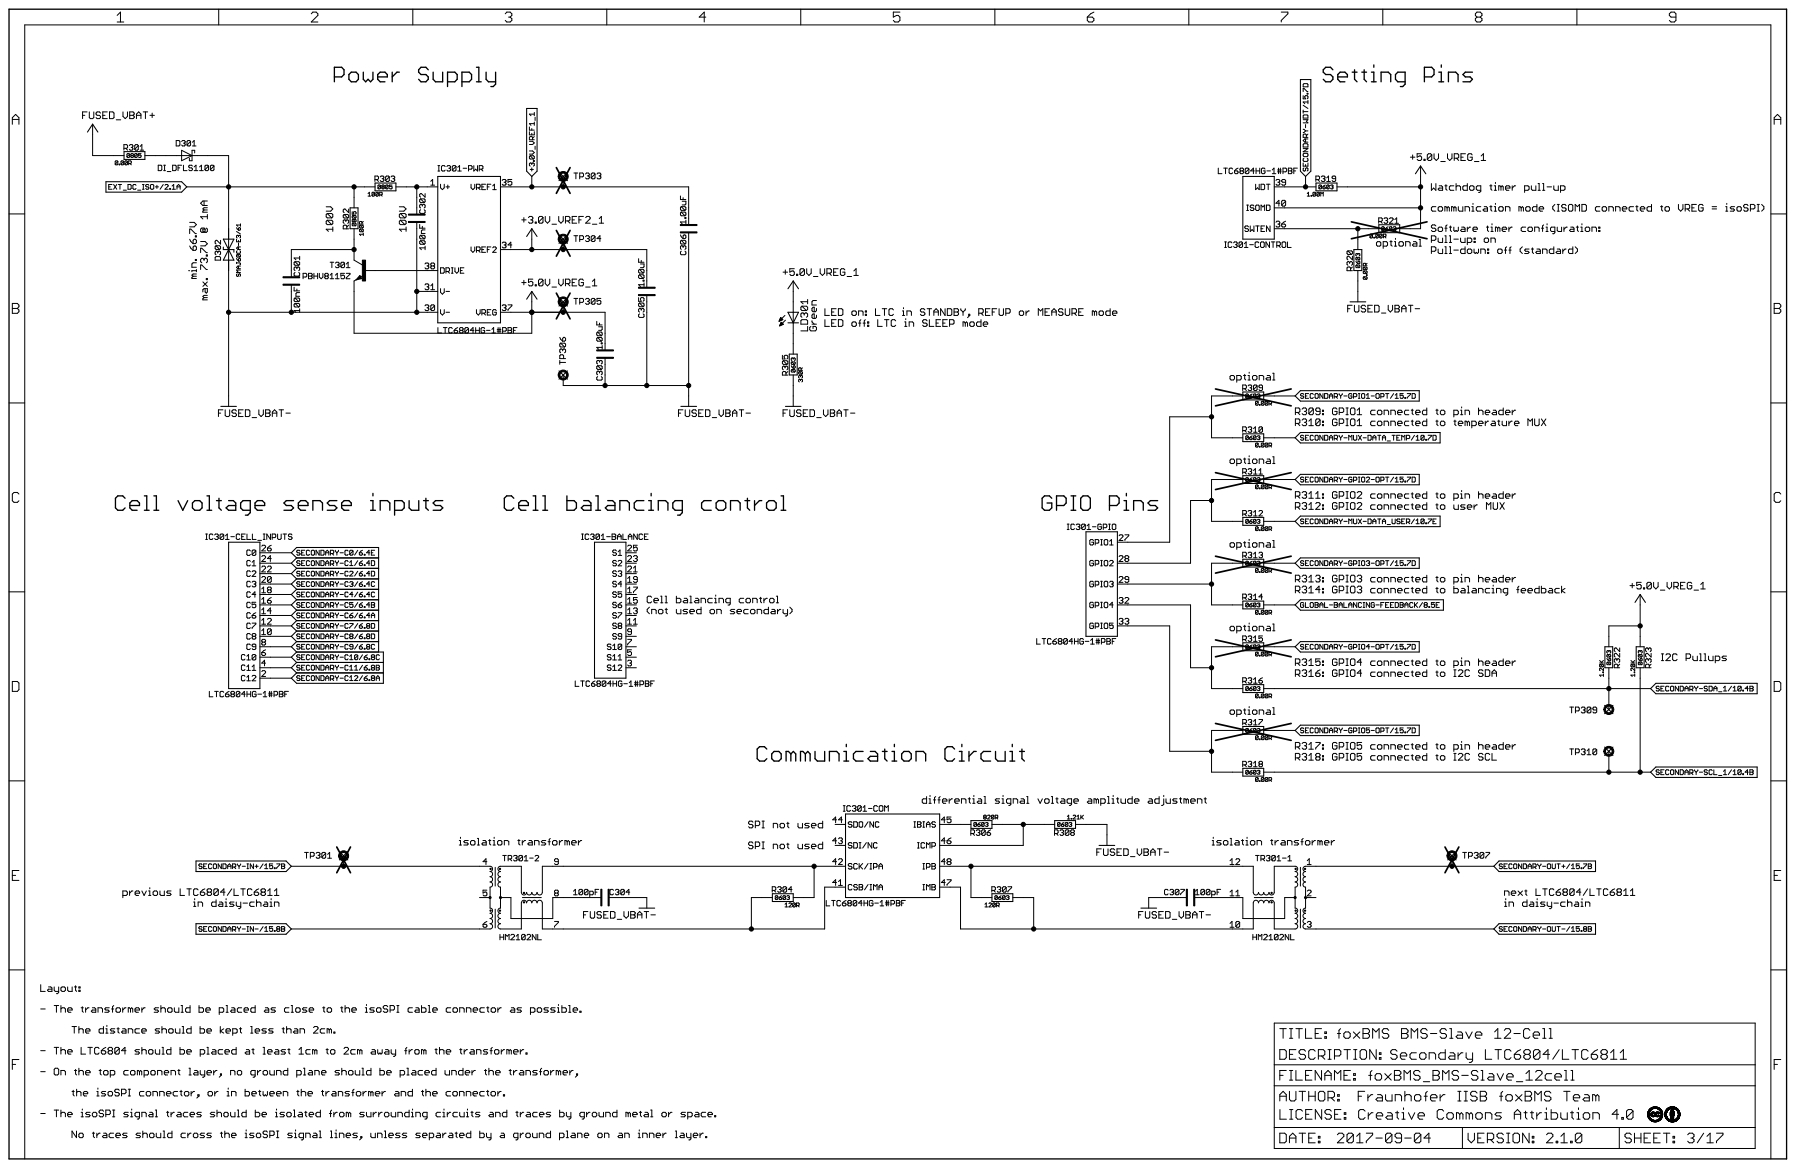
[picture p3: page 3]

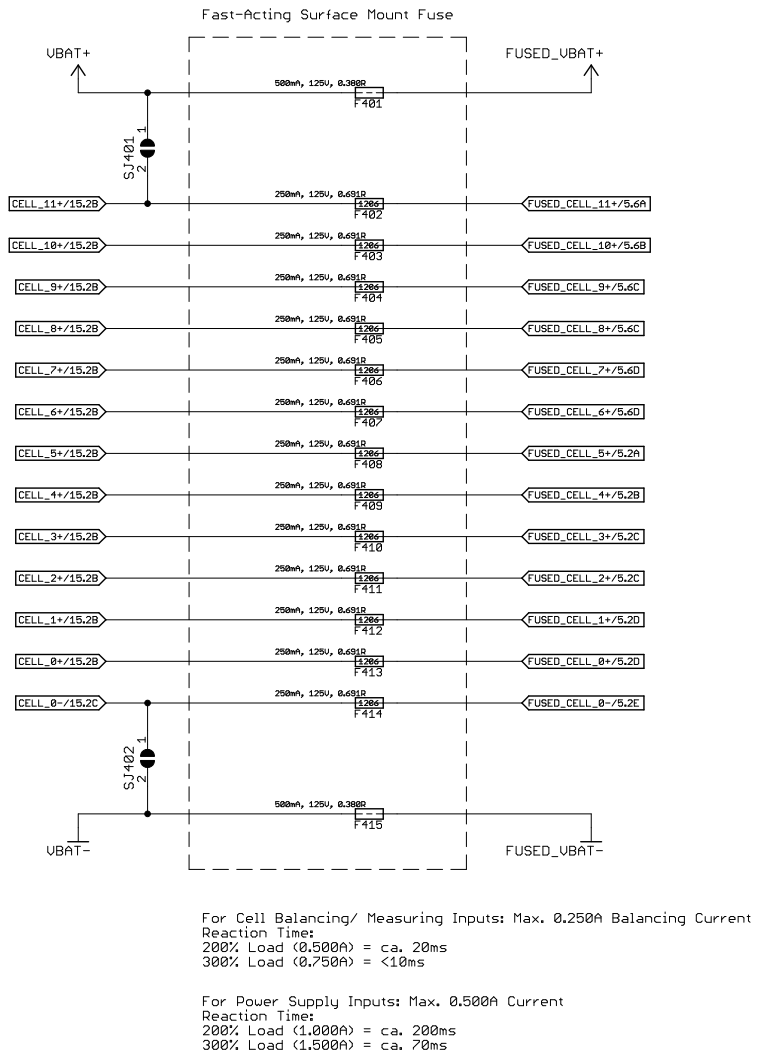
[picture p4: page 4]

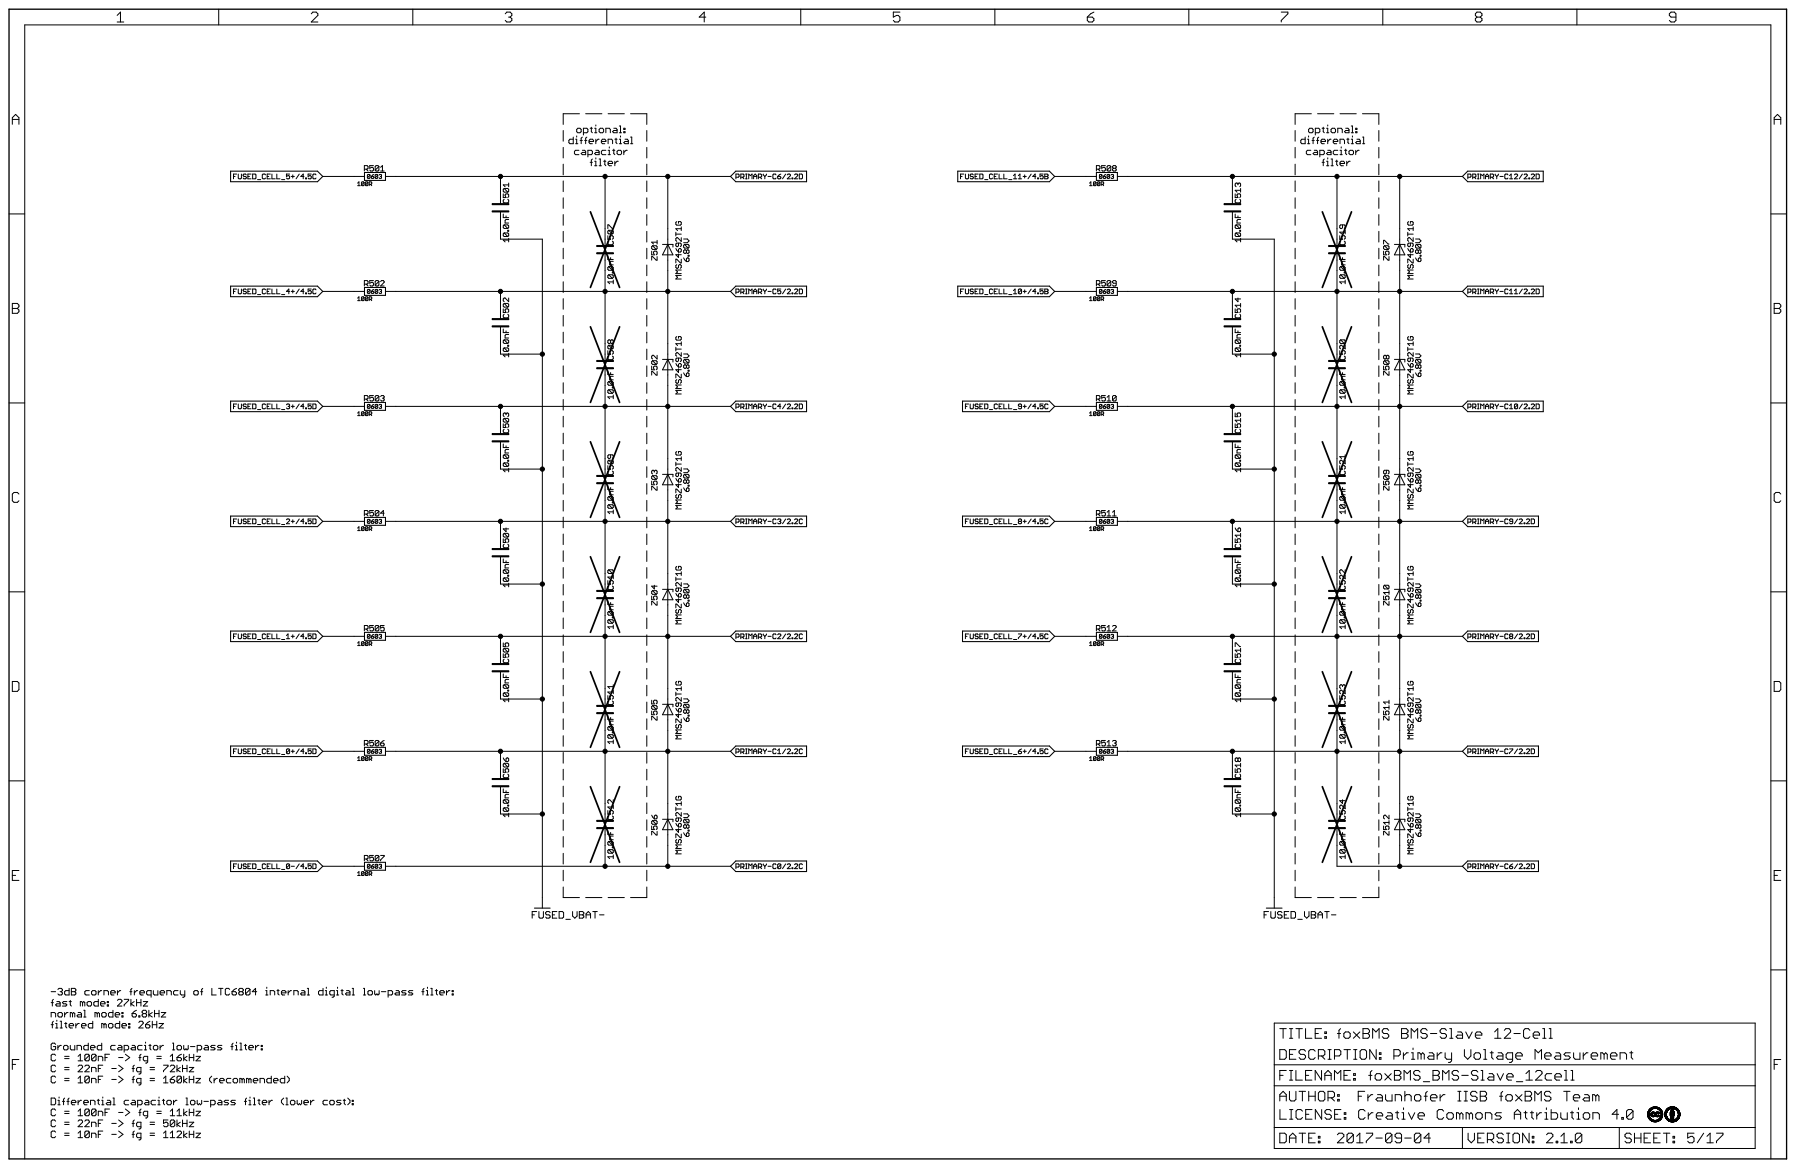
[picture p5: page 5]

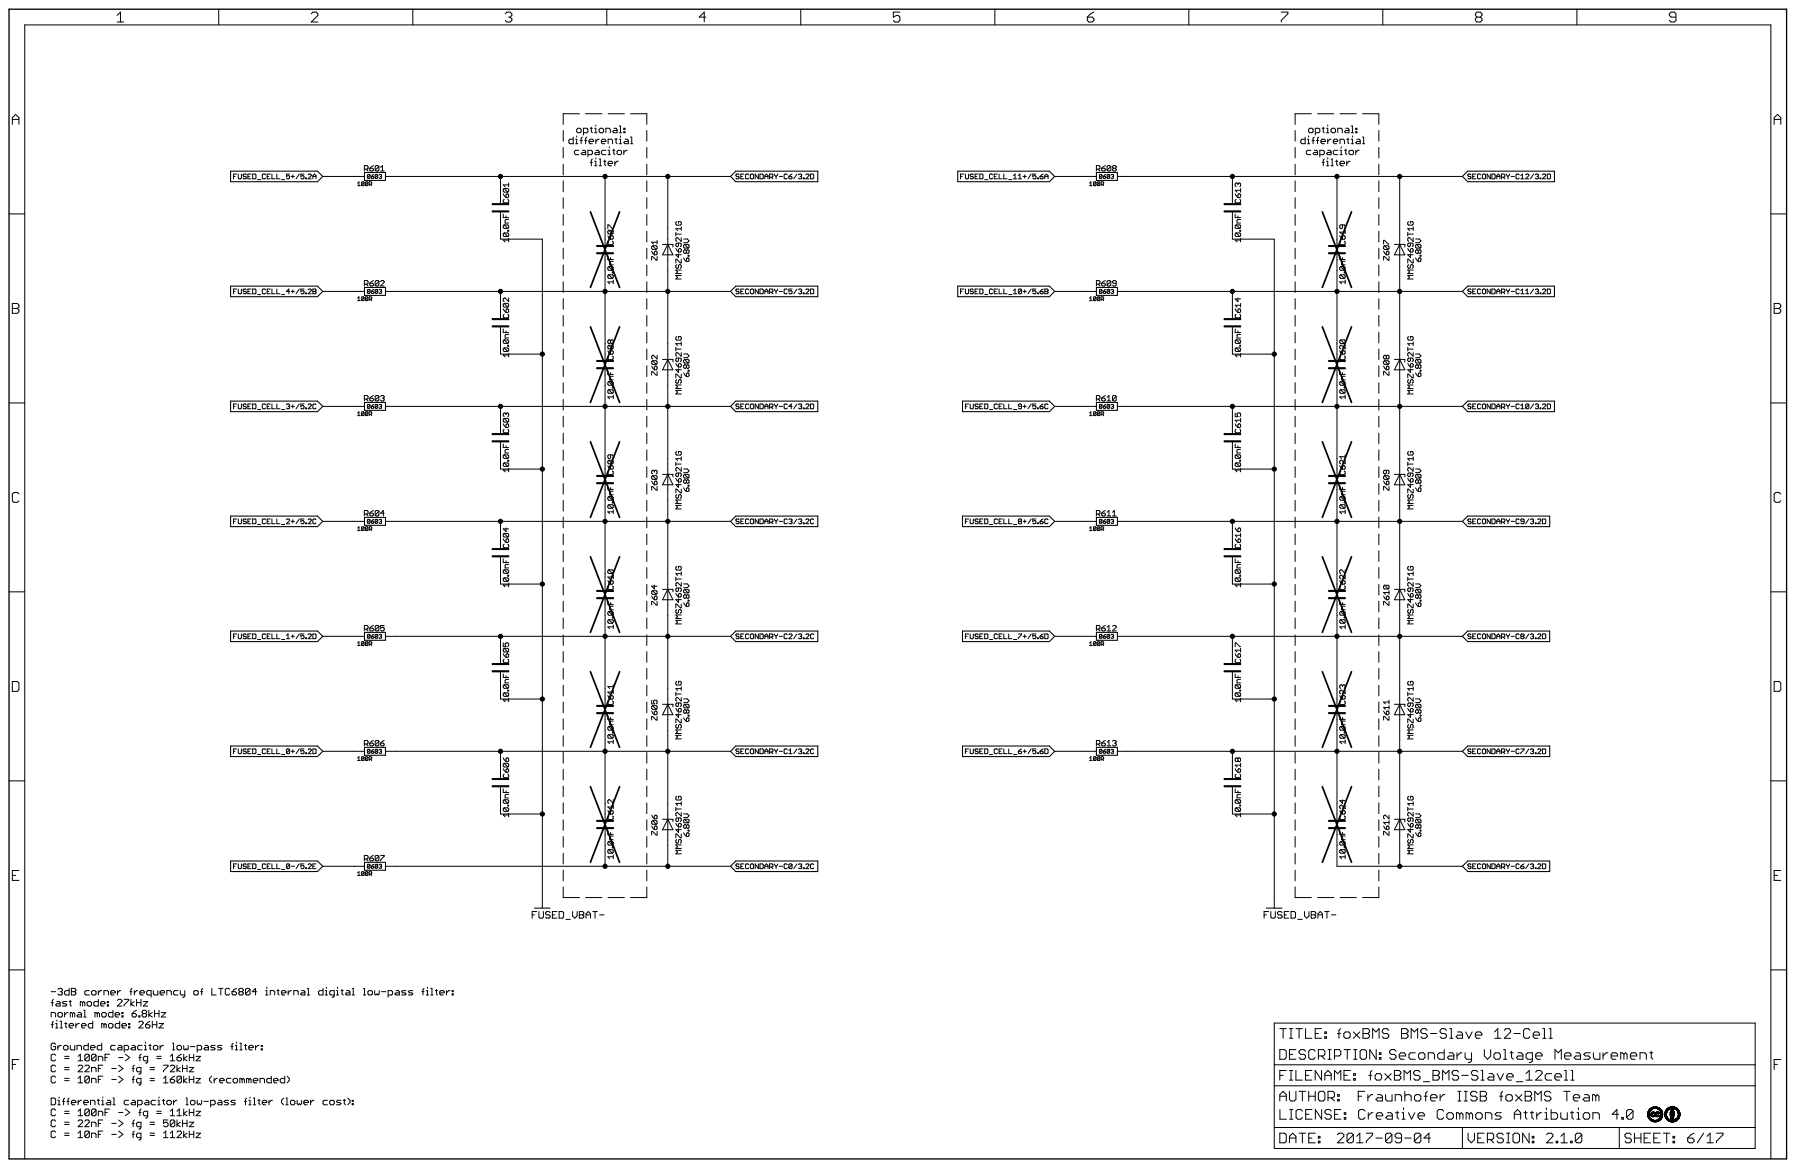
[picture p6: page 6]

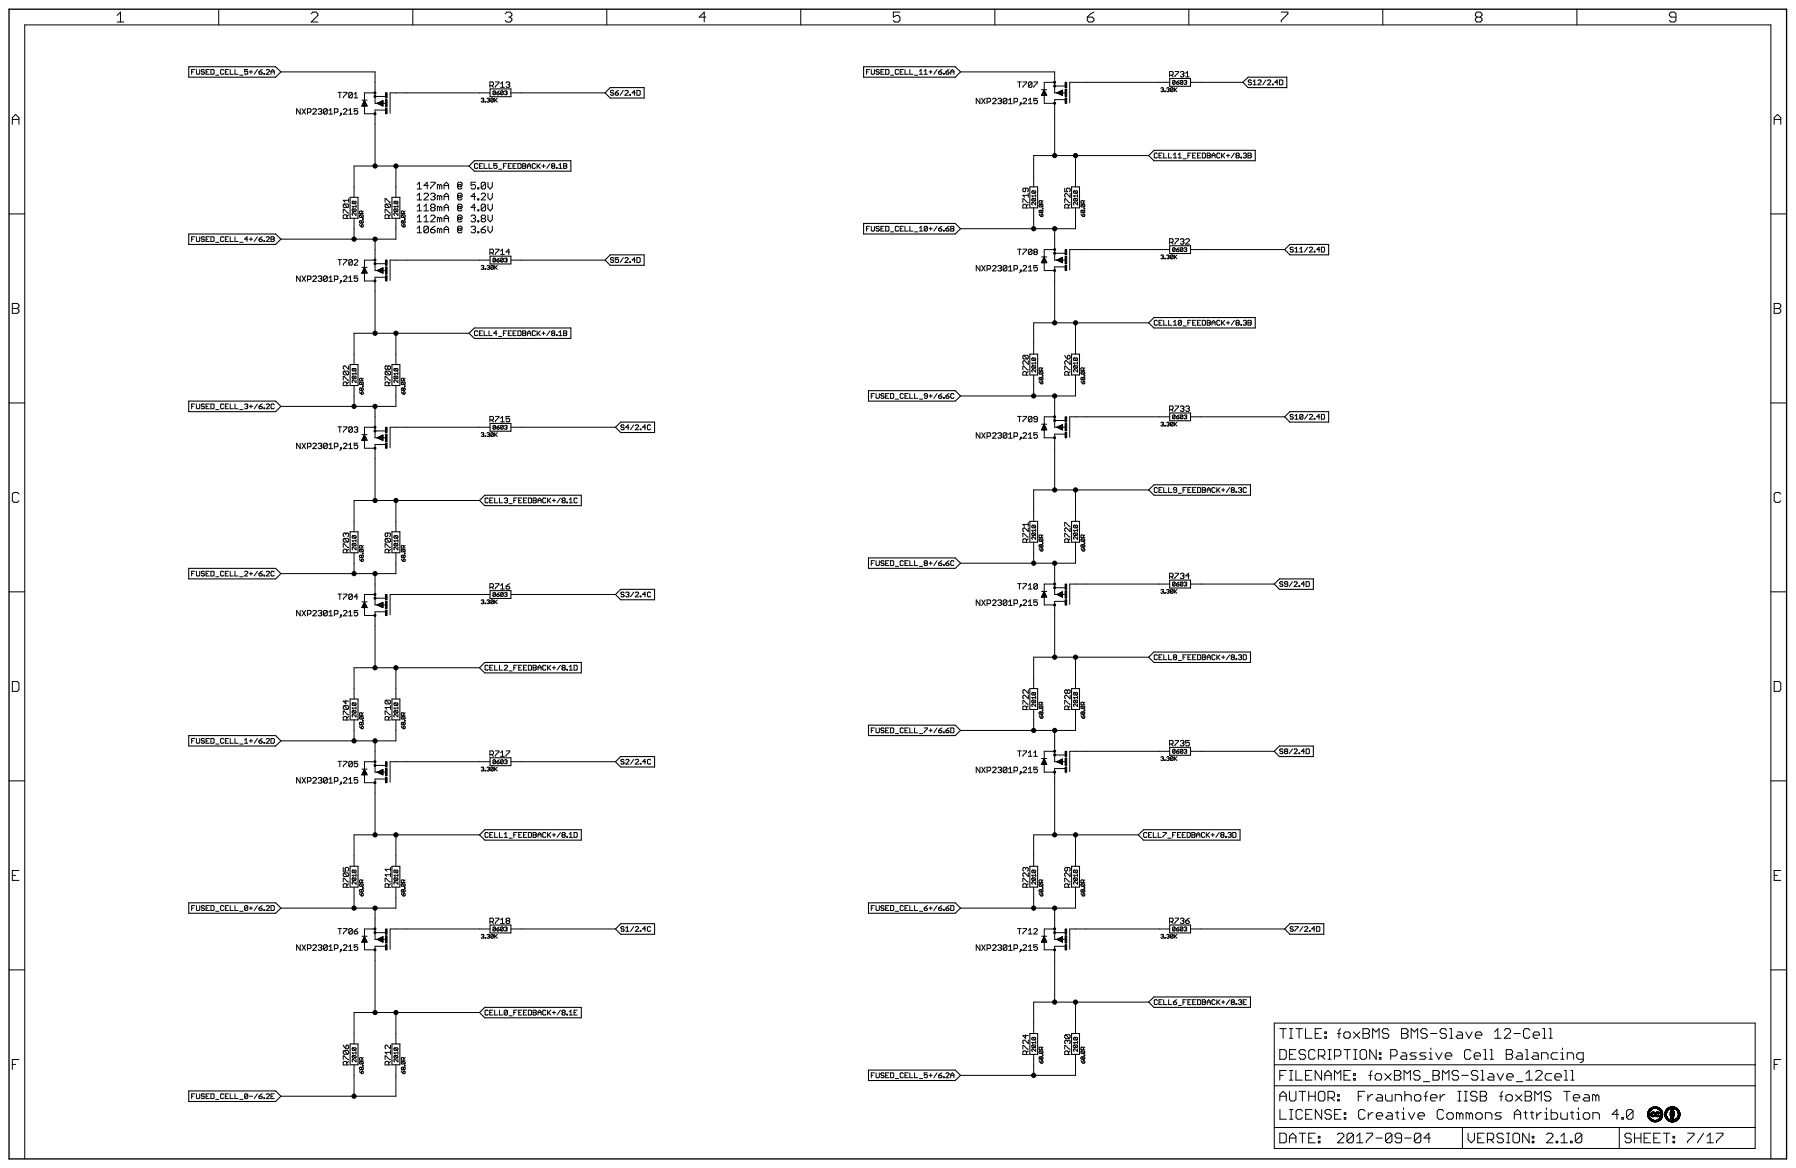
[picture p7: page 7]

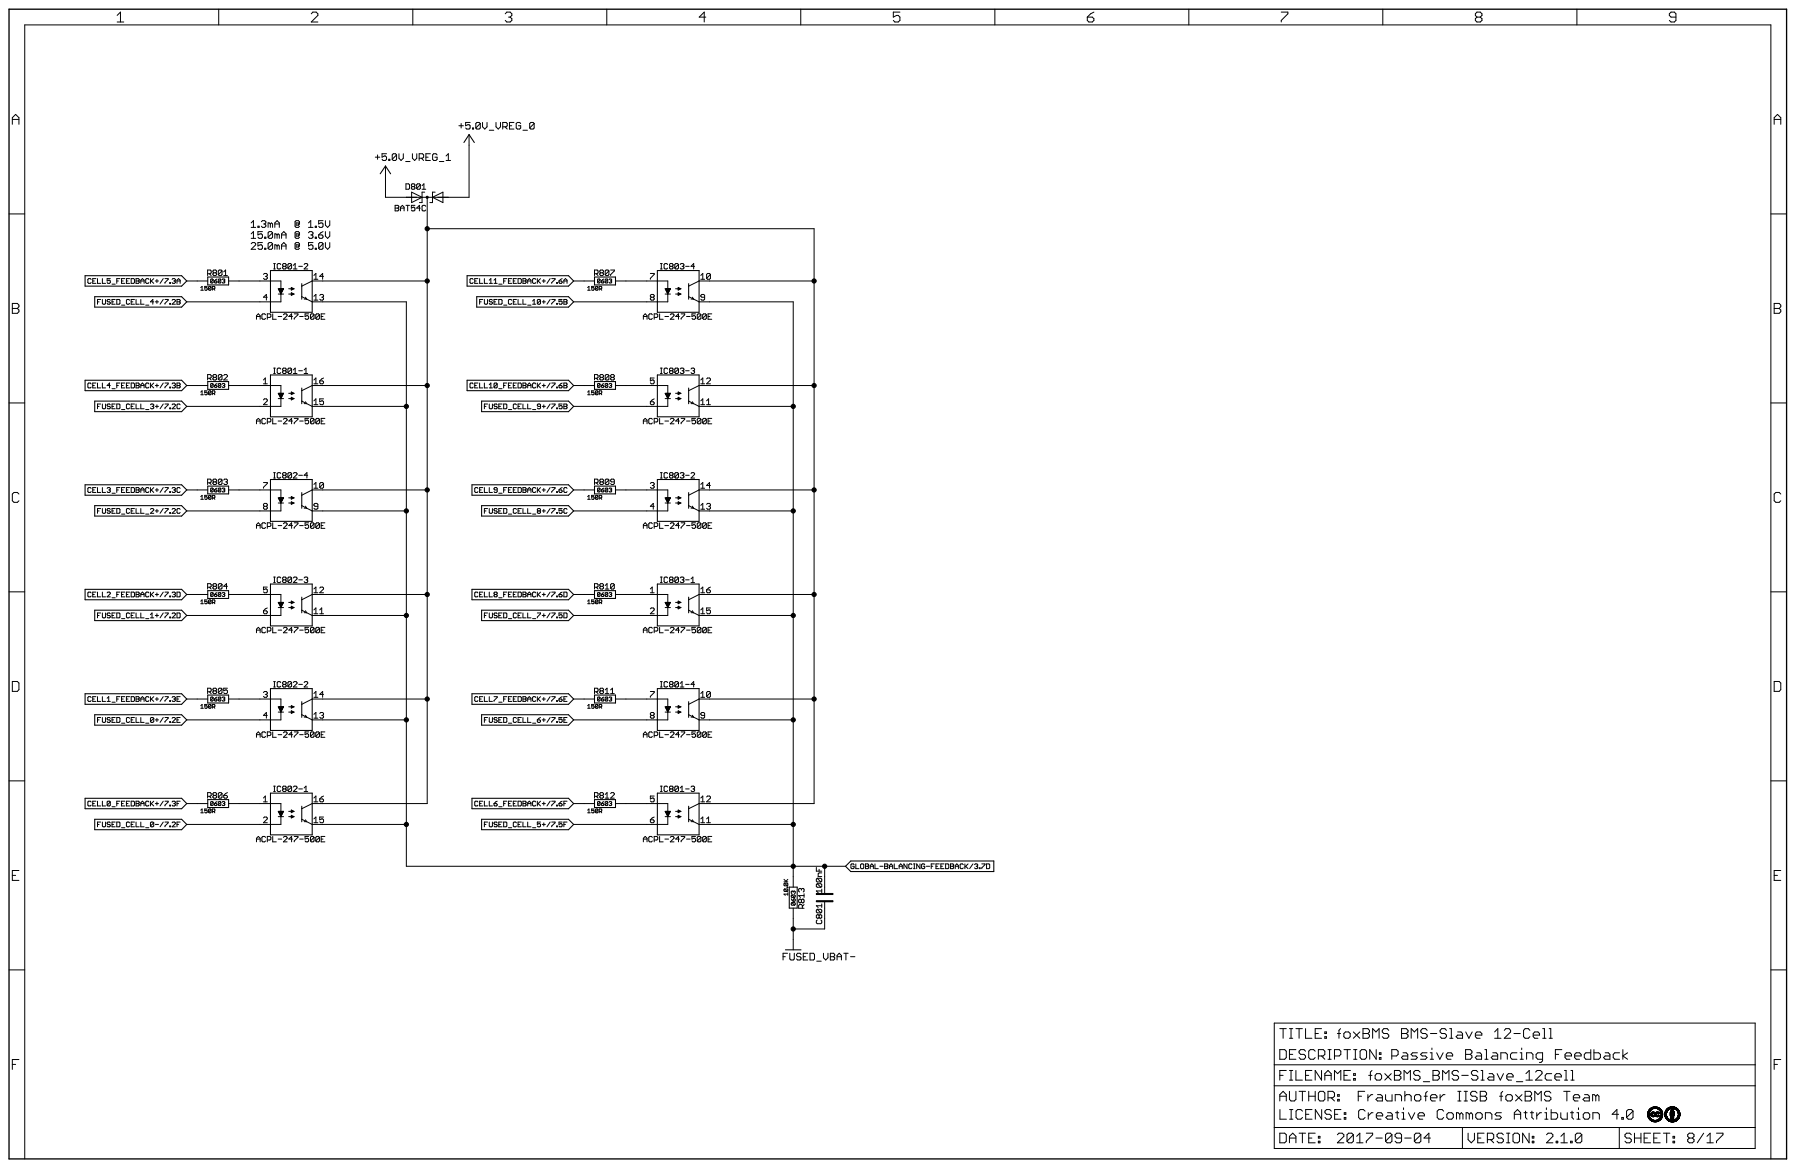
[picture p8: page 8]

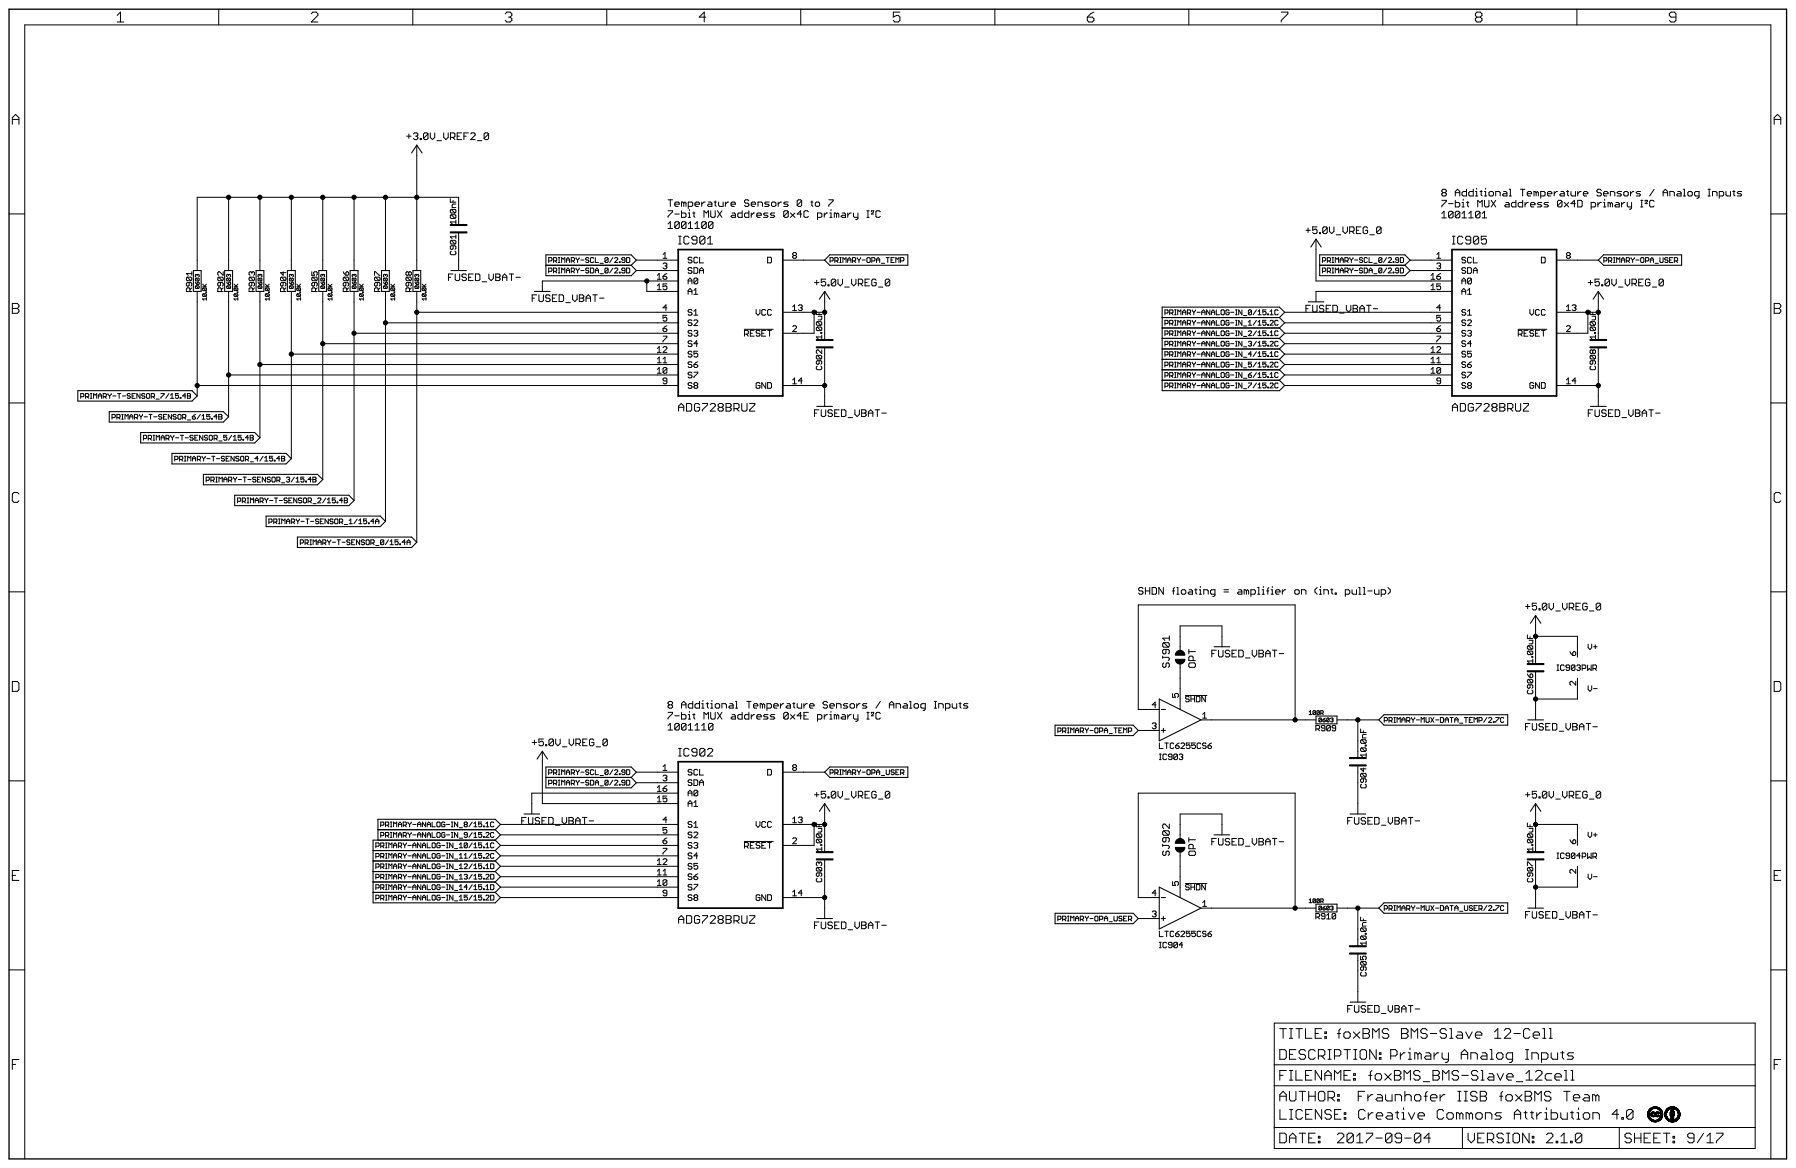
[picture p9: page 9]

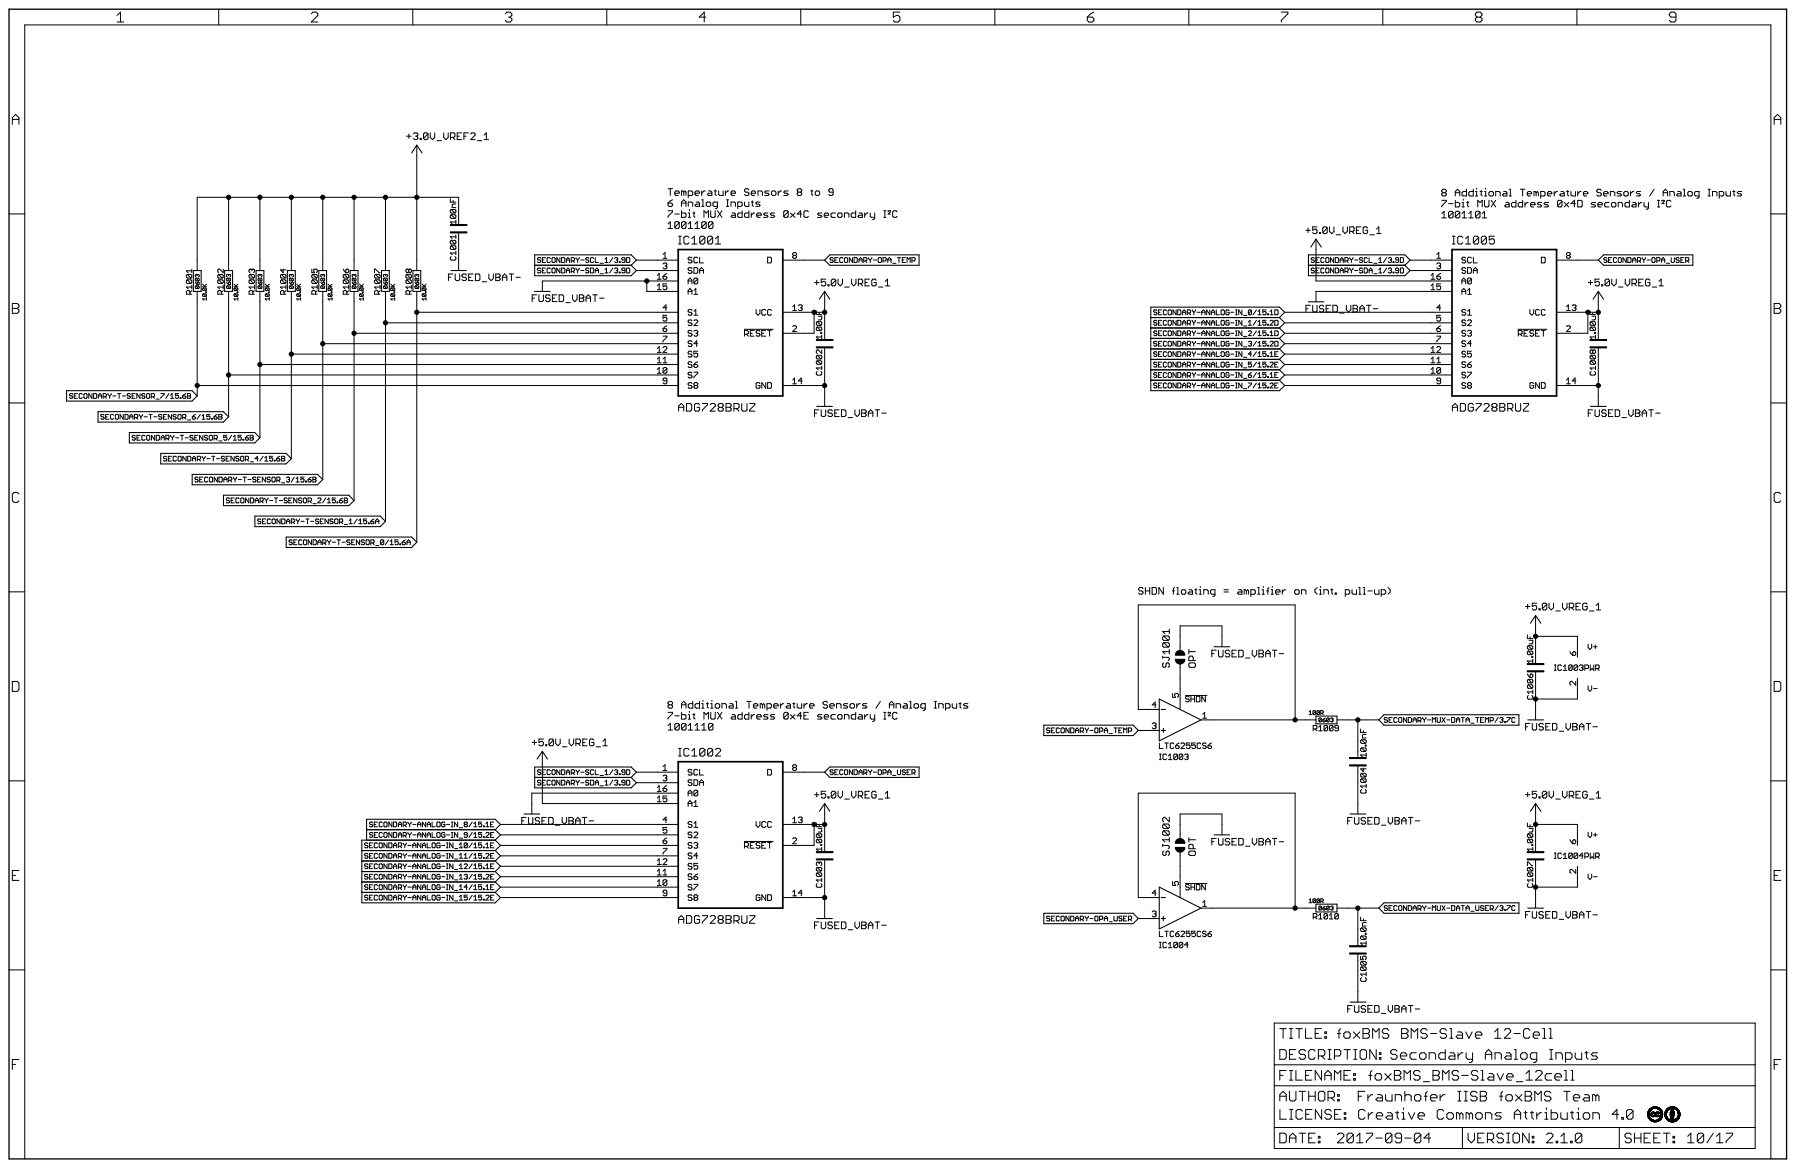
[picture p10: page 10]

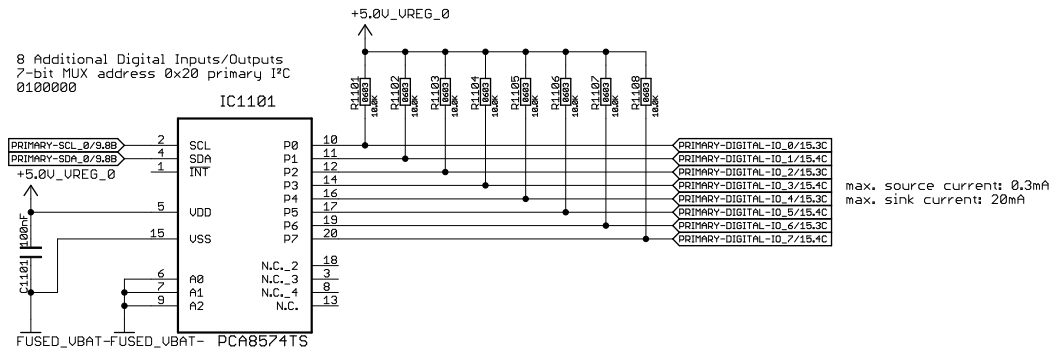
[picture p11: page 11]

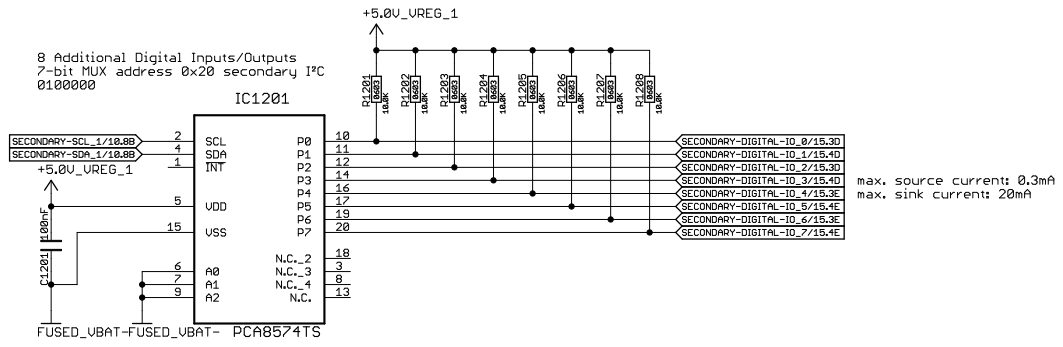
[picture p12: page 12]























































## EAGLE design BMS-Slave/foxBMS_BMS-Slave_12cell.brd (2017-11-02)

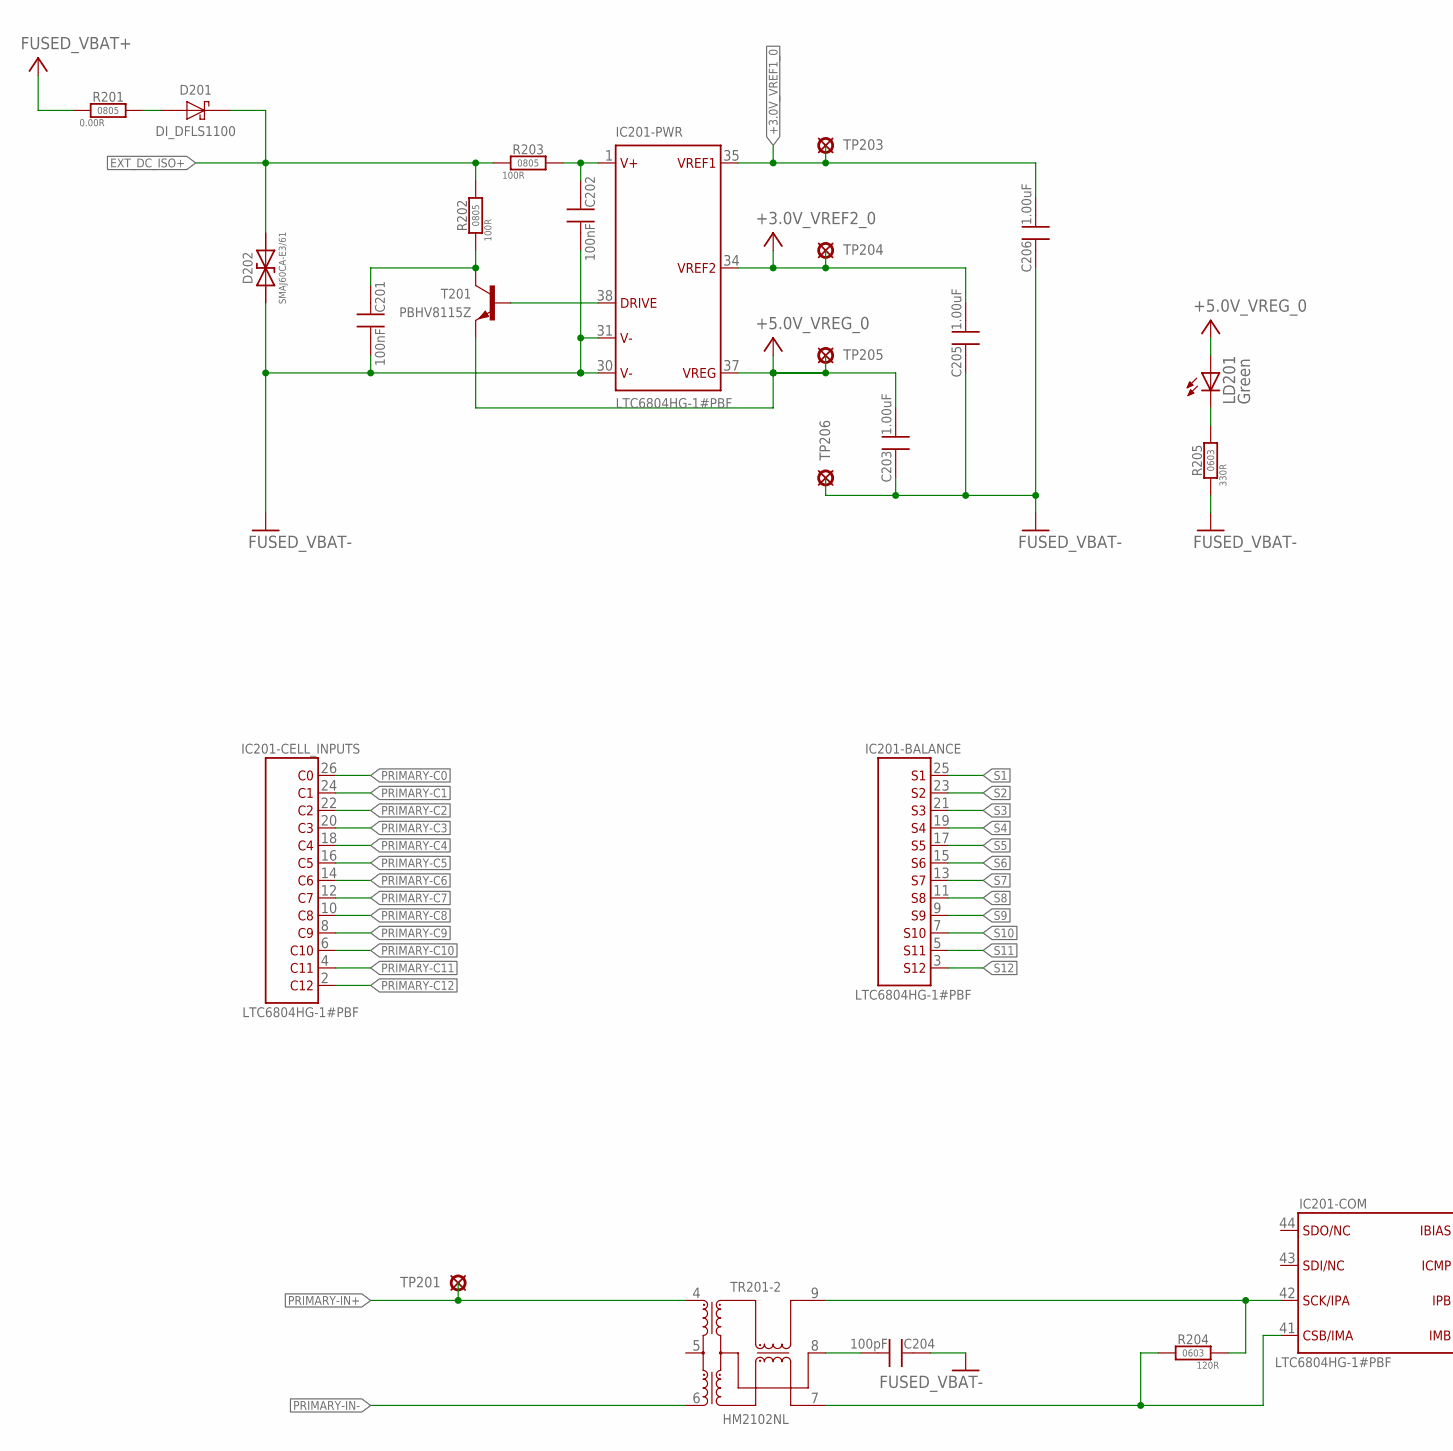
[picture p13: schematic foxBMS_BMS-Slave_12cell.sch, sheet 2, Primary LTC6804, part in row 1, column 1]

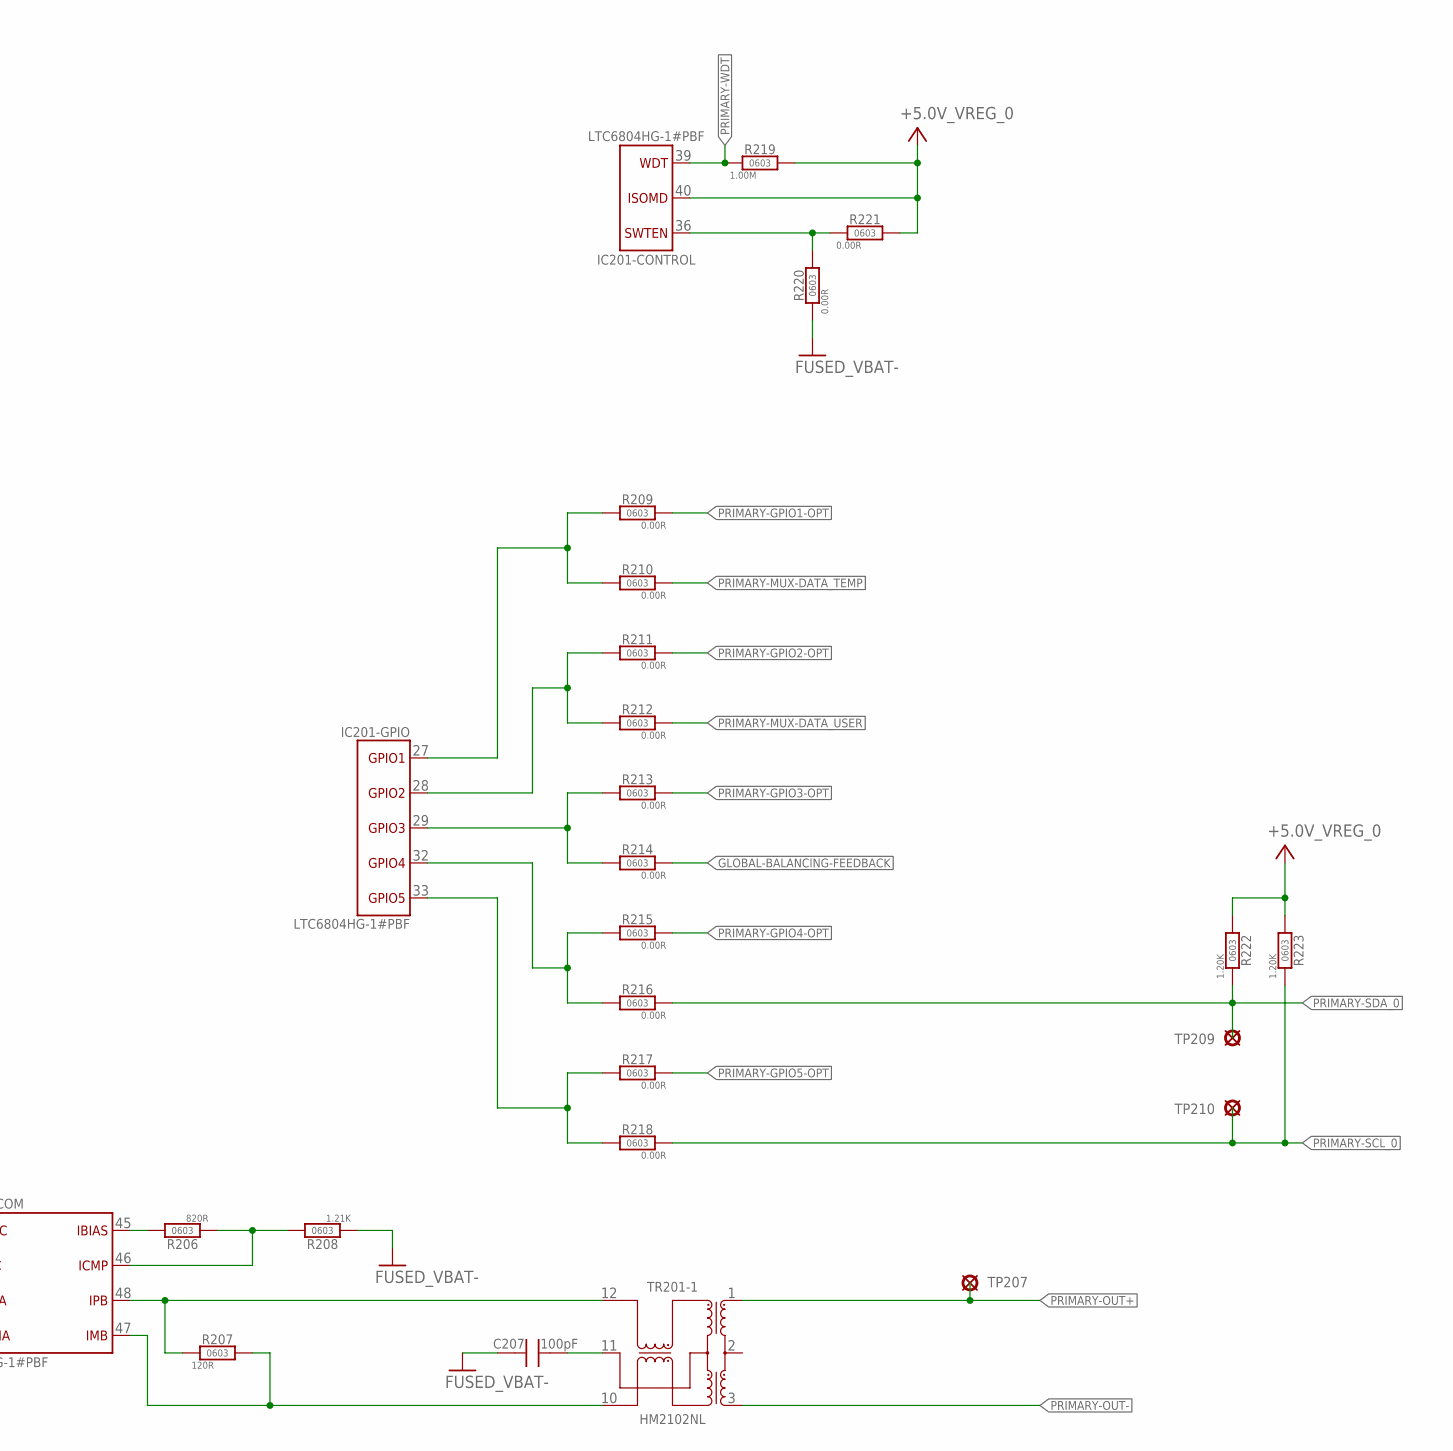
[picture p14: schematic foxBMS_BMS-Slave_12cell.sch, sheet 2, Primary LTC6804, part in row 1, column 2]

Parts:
C201, C202: 100nF, 10%, 100V; C_SMD_0805_(2012)_R_MULTICOMP_REV01
C203, C205, C206: 1uF, 20%, 16V; C_SMD_0603_(1608)_R_KEMET_REV01
C204, C207: 100pF, 15%, 25V; C_SMD_0603_(1608)_R_KEMET_REV01
D201: DI_DFLS1100; POWER_DI_123
D202: SMAJ60CA_VISHAY; D_SMD_SMA_(DO-214AC)_(BIDIR)_R_VISHAY_REV01
IC201: 0_LES_BATTERIE-MANAGEMENT.SMD_LTC6804HG-1; 0_LES_BATTERIE-MANAGEMENT.SMD_IC_SMD_SSOP-48_(G48)_R_LINEAR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
LD201: Green; CHIP-LED0603
R201: 0,00R_0805_R_VISHAY_REV_01; R_SMD_0805_R_VISHAY_REV01
R202, R203: 100R, 1%, 1/10W; R_SMD_0805_R_VISHAY_REV01
R204, R207: 120R, 1%, 1/10W; R_SMD_0603_R_VISHAY_REV01
R205: 330R, 1%, 1/10W; R_SMD_0603_R_VISHAY_REV01
R206: 820R, 1%, 1/10W; R_SMD_0603_R_VISHAY_REV01
R208: 1.21k, 1%, 1/10W; R_SMD_0603_R_VISHAY_REV01
R209, R211, R213, R215, R217, R221: OPT; R_SMD_0603_R_VISHAY_REV01
R210, R212, R214, R216, R218, R220: 0R; R_SMD_0603_R_VISHAY_REV01
R219: 1M, 10%, 1/10W; R_SMD_0603_R_VISHAY_REV01
R222, R223: 1.2k, 10%, 1/10W; R_SMD_0603_R_VISHAY_REV01
T201: PBHV8115Z; D_SMD_SOT223_(SC-73)_R_NXP_REV01
TP201, TP203, TP204, TP205, TP206, TP207, TP209, TP210: CUSTOM_PAD_PAD_2.0X1.5MM; CUSTOM_PAD_PAD2.0X1.5MM
TR201: HM2102NL

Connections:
+3.0V_VREF1_0: C206.2, IC201.35 (VREF1), TP203.P$1
+3.0V_VREF2_0: C205.2, IC201.34 (VREF2), TP204.P$1; also elsewhere on the board
+5.0V_VREG_0: C203.2, IC201.37 (VREG), IC201.40 (ISOMD), LD201.A, R219.2, R221.2, R222.2, R223.2, T201.3 (E), TP205.P$1; also elsewhere on the board
EXT_DC_ISO+: D201.K (C), D202.C (K2), R202.2, R203.1; also elsewhere on the board
FUSED_VBAT+: R201.1; also elsewhere on the board
FUSED_VBAT-: C201.P$2, C202.P$2, C203.1, C204.1, C205.1, C206.1, C207.1, D202.A (K1), IC201.30 (V-1), IC201.31 (V-2), R205.1, R208.1, R220.1, TP206.P$1; also elsewhere on the board
GLOBAL-BALANCING-FEEDBACK: R214.1; also elsewhere on the board
unnamed: C207.2, TR201.11 (CMT)
unnamed: C201.P$1, R202.1, T201.2 (C), T201.4 (C)
unnamed: C204.2, TR201.8 (CMT)
unnamed: IC201.38 (DRIVE), T201.1 (B)
unnamed: IC201.45 (IBIAS), R206.2
unnamed: C202.P$1, IC201.1 (V+), R203.2
unnamed: LD201.C, R205.2
unnamed: D201.A, R201.2
PRIMARY-C0: IC201.26 (C0); also elsewhere on the board
PRIMARY-C1: IC201.24 (C1); also elsewhere on the board
PRIMARY-C2: IC201.22 (C2); also elsewhere on the board
PRIMARY-C3: IC201.20 (C3); also elsewhere on the board
PRIMARY-C4: IC201.18 (C4); also elsewhere on the board
PRIMARY-C5: IC201.16 (C5); also elsewhere on the board
PRIMARY-C6: IC201.14 (C6); also elsewhere on the board
PRIMARY-C7: IC201.12 (C7); also elsewhere on the board
PRIMARY-C8: IC201.10 (C8); also elsewhere on the board
PRIMARY-C9: IC201.8 (C9); also elsewhere on the board
PRIMARY-C10: IC201.6 (C10); also elsewhere on the board
PRIMARY-C11: IC201.4 (C11); also elsewhere on the board
PRIMARY-C12: IC201.2 (C12); also elsewhere on the board
PRIMARY-GPIO0: IC201.27 (GPIO1), R209.2, R210.2
PRIMARY-GPIO1: IC201.28 (GPIO2), R211.2, R212.2
PRIMARY-GPIO1-OPT: R209.1; also elsewhere on the board
PRIMARY-GPIO2-OPT: R211.1; also elsewhere on the board
PRIMARY-GPIO3: IC201.32 (GPIO4), R215.2, R216.2
PRIMARY-GPIO3-OPT: R213.1; also elsewhere on the board
PRIMARY-GPIO4: IC201.33 (GPIO5), R217.2, R218.2
PRIMARY-GPIO4-OPT: R215.1; also elsewhere on the board
PRIMARY-GPIO5: IC201.29 (GPIO3), R213.2, R214.2
PRIMARY-GPIO5-OPT: R217.1; also elsewhere on the board
PRIMARY-ICMP: IC201.46 (ICMP), R206.1, R208.2
PRIMARY-IN+: TP201.P$1, TR201.4 (D+); also elsewhere on the board
PRIMARY-IN-: TR201.6 (D-); also elsewhere on the board
PRIMARY-IN_N1: IC201.41 (CSB/IMA), R204.2, TR201.7 (X-)
PRIMARY-IN_P1: IC201.42 (SCK/IPA), R204.1, TR201.9 (X+)
PRIMARY-MUX-DATA_TEMP: R210.1; also elsewhere on the board
PRIMARY-MUX-DATA_USER: R212.1; also elsewhere on the board
PRIMARY-OUT+: TP207.P$1, TR201.1 (D+); also elsewhere on the board
PRIMARY-OUT-: TR201.3 (D-); also elsewhere on the board
PRIMARY-OUT_N1: IC201.47 (IMB), R207.2, TR201.10 (X-)
PRIMARY-OUT_P1: IC201.48 (IPB), R207.1, TR201.12 (X+)
PRIMARY-SCL_0: R218.1, R223.1, TP210.P$1; also elsewhere on the board
PRIMARY-SDA_0: R216.1, R222.1, TP209.P$1; also elsewhere on the board
PRIMARY-SWTEN: IC201.36 (SWTEN), R220.2, R221.1
PRIMARY-WDT: IC201.39 (WDT), R219.1; also elsewhere on the board
S1: IC201.25 (S1); also elsewhere on the board
S2: IC201.23 (S2); also elsewhere on the board
S3: IC201.21 (S3); also elsewhere on the board
S4: IC201.19 (S4); also elsewhere on the board
S5: IC201.17 (S5); also elsewhere on the board
S6: IC201.15 (S6); also elsewhere on the board
S7: IC201.13 (S7); also elsewhere on the board
S8: IC201.11 (S8); also elsewhere on the board
S9: IC201.9 (S9); also elsewhere on the board
S10: IC201.7 (S10); also elsewhere on the board
S11: IC201.5 (S11); also elsewhere on the board
S12: IC201.3 (S12); also elsewhere on the board

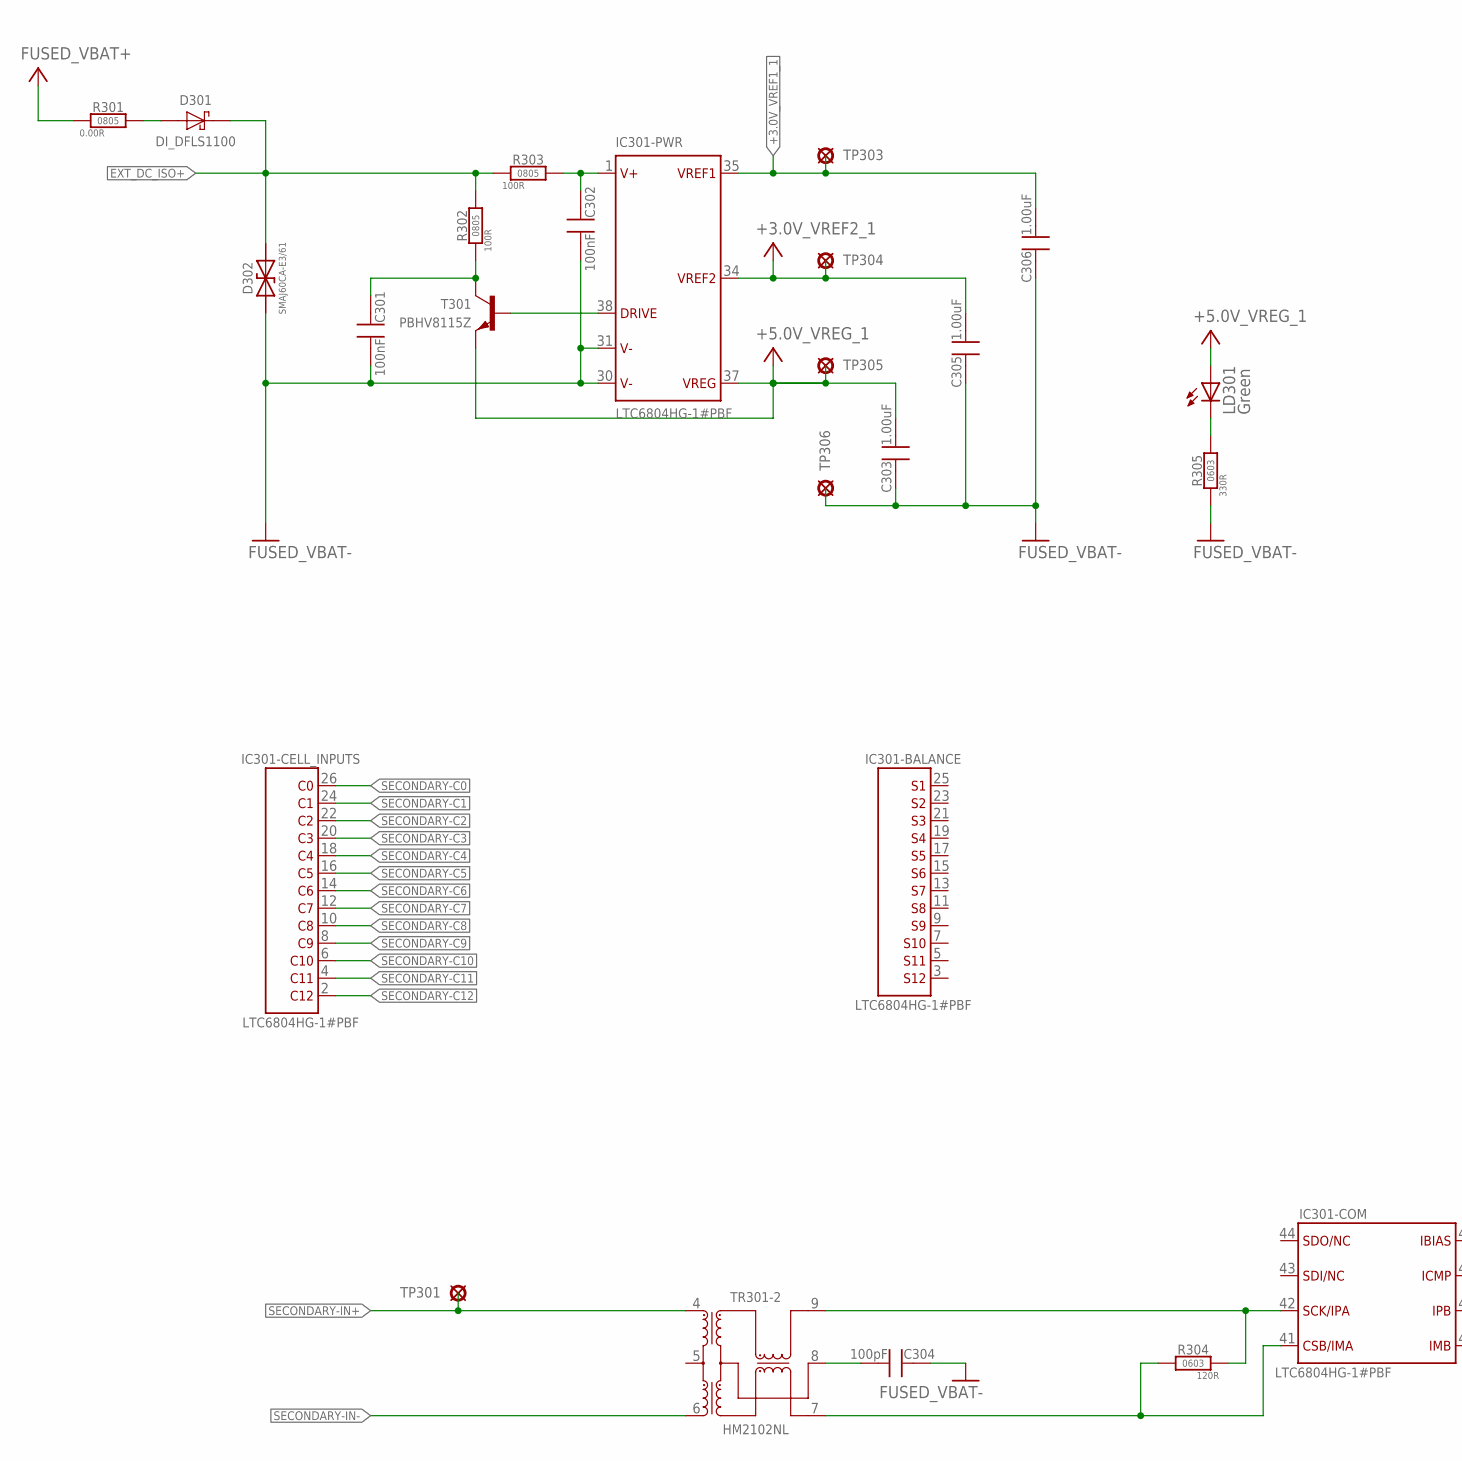
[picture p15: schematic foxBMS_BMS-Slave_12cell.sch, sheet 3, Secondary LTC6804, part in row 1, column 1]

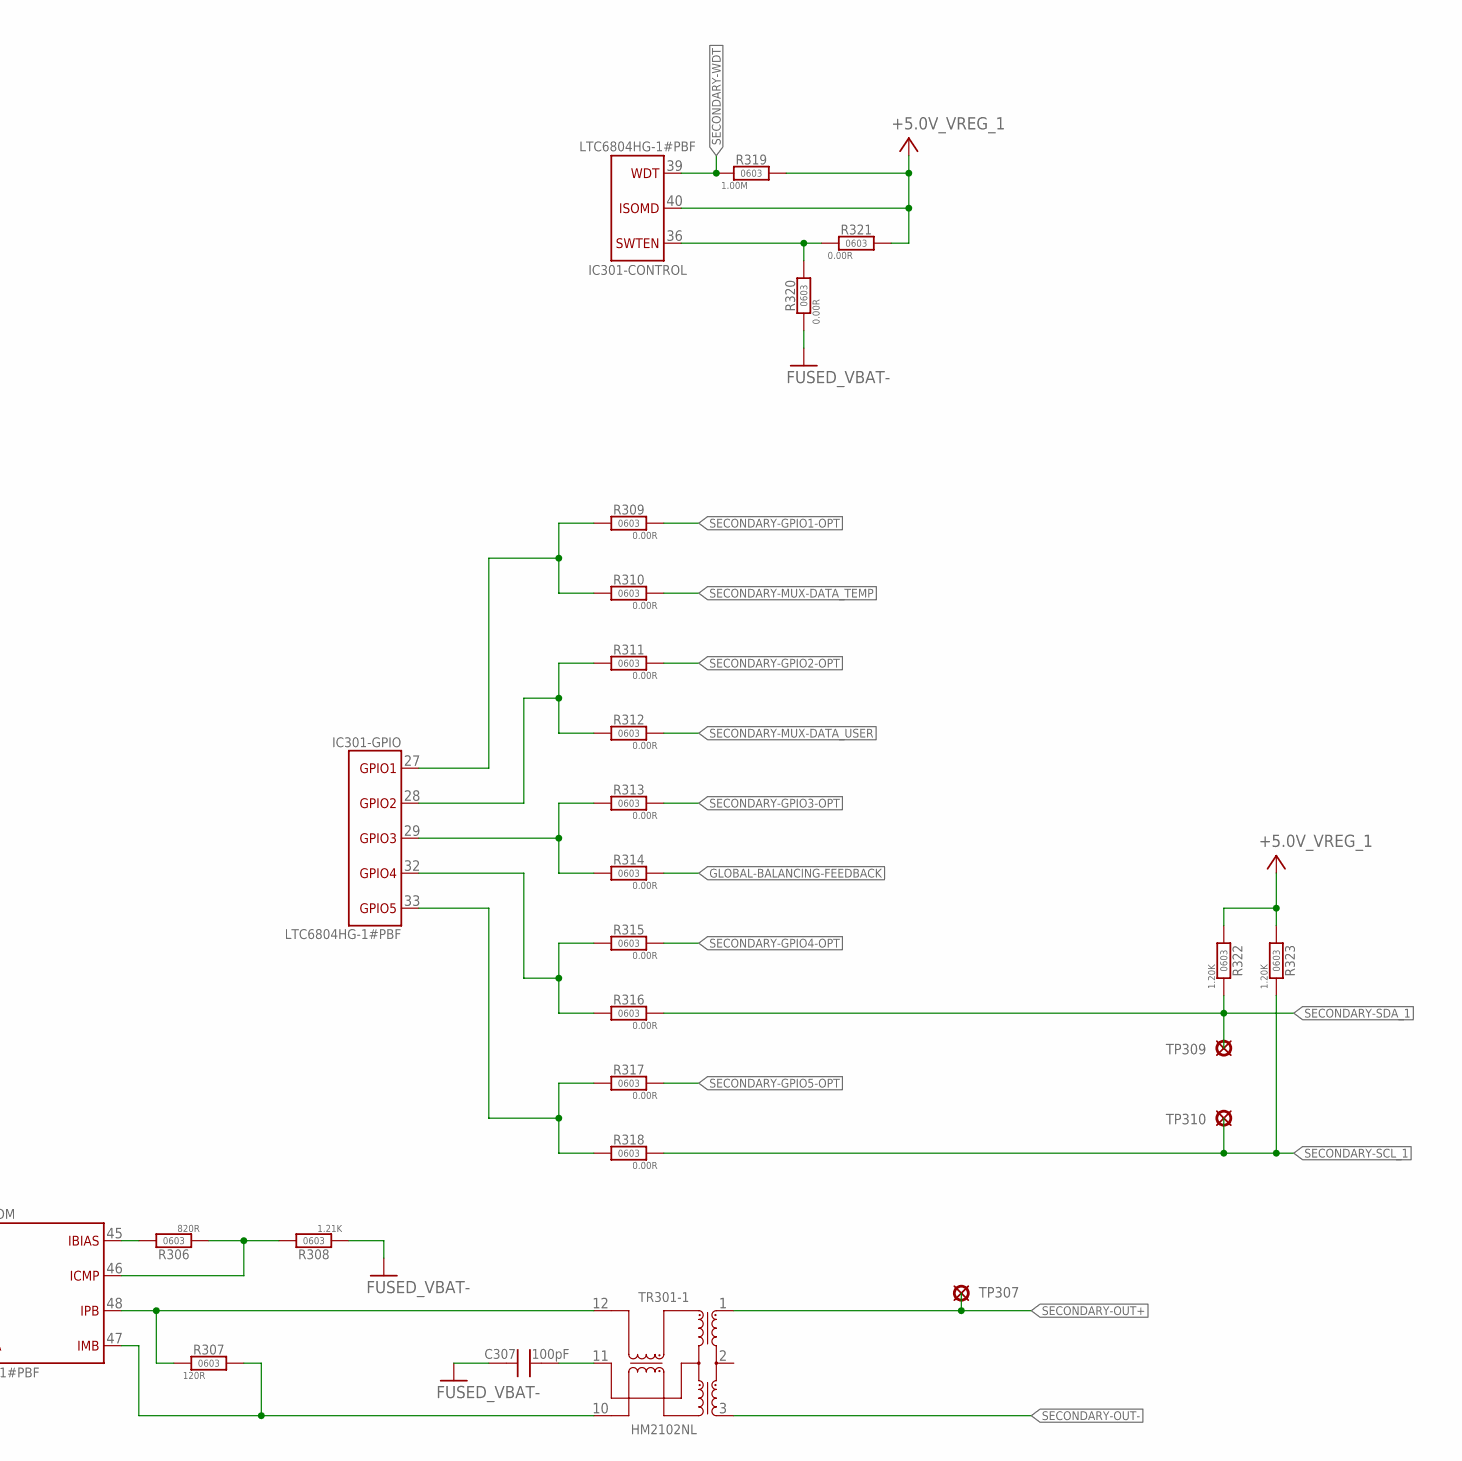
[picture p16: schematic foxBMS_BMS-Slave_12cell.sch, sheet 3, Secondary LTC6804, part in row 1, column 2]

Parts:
C301, C302: 100nF, 10%, 100V; C_SMD_0805_(2012)_R_MULTICOMP_REV01
C303, C305, C306: 1uF, 20%, 16V; C_SMD_0603_(1608)_R_KEMET_REV01
C304, C307: 100pF, 15%, 25V; C_SMD_0603_(1608)_R_KEMET_REV01
D301: DI_DFLS1100; POWER_DI_123
D302: SMAJ60CA_VISHAY; D_SMD_SMA_(DO-214AC)_(BIDIR)_R_VISHAY_REV01
IC301: 0_LES_BATTERIE-MANAGEMENT.SMD_LTC6804HG-1; 0_LES_BATTERIE-MANAGEMENT.SMD_IC_SMD_SSOP-48_(G48)_R_LINEAR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
LD301: Green; CHIP-LED0603
R301: 0,00R_0805_R_VISHAY_REV_01; R_SMD_0805_R_VISHAY_REV01
R302, R303: 100R, 1%, 1/10W; R_SMD_0805_R_VISHAY_REV01
R304, R307: 120R, 1%, 1/10W; R_SMD_0603_R_VISHAY_REV01
R305: 330R, 1%, 1/10W; R_SMD_0603_R_VISHAY_REV01
R306: 820R, 1%, 1/10W; R_SMD_0603_R_VISHAY_REV01
R308: 1.21k, 1%, 1/10W; R_SMD_0603_R_VISHAY_REV01
R309, R311, R313, R315, R317, R321: OPT; R_SMD_0603_R_VISHAY_REV01
R310, R312, R314, R316, R318, R320: 0R; R_SMD_0603_R_VISHAY_REV01
R319: 1M, 10%, 1/10W; R_SMD_0603_R_VISHAY_REV01
R322, R323: 1.2k, 10%, 1/10W; R_SMD_0603_R_VISHAY_REV01
T301: PBHV8115Z; D_SMD_SOT223_(SC-73)_R_NXP_REV01
TP301, TP303, TP304, TP305, TP306, TP307, TP309, TP310: CUSTOM_PAD_PAD_2.0X1.5MM; CUSTOM_PAD_PAD2.0X1.5MM
TR301: HM2102NL

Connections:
+3.0V_VREF1_1: C306.2, IC301.35 (VREF1), TP303.P$1
+3.0V_VREF2_1: C305.2, IC301.34 (VREF2), TP304.P$1; also elsewhere on the board
+5.0V_VREG_1: C303.2, IC301.37 (VREG), IC301.40 (ISOMD), LD301.A, R319.2, R321.2, R322.2, R323.2, T301.3 (E), TP305.P$1; also elsewhere on the board
EXT_DC_ISO+: D301.K (C), D302.C (K2), R302.2, R303.1; also elsewhere on the board
FUSED_VBAT+: R301.1; also elsewhere on the board
FUSED_VBAT-: C301.P$2, C302.P$2, C303.1, C304.1, C305.1, C306.1, C307.1, D302.A (K1), IC301.30 (V-1), IC301.31 (V-2), R305.1, R308.1, R320.1, TP306.P$1; also elsewhere on the board
GLOBAL-BALANCING-FEEDBACK: R314.1; also elsewhere on the board
unnamed: C307.2, TR301.11 (CMT)
unnamed: C304.2, TR301.8 (CMT)
unnamed: C302.P$1, IC301.1 (V+), R303.2
unnamed: C301.P$1, R302.1, T301.2 (C), T301.4 (C)
unnamed: IC301.38 (DRIVE), T301.1 (B)
unnamed: IC301.45 (IBIAS), R306.2
unnamed: LD301.C, R305.2
unnamed: IC301.32 (GPIO4), R315.2, R316.2
unnamed: D301.A, R301.2
PRIMARY-ICMP1: IC301.46 (ICMP), R306.1, R308.2
PRIMARY-SWTEN1: IC301.36 (SWTEN), R320.2, R321.1
SECONDARY-C0: IC301.26 (C0); also elsewhere on the board
SECONDARY-C1: IC301.24 (C1); also elsewhere on the board
SECONDARY-C2: IC301.22 (C2); also elsewhere on the board
SECONDARY-C3: IC301.20 (C3); also elsewhere on the board
SECONDARY-C4: IC301.18 (C4); also elsewhere on the board
SECONDARY-C5: IC301.16 (C5); also elsewhere on the board
SECONDARY-C6: IC301.14 (C6); also elsewhere on the board
SECONDARY-C7: IC301.12 (C7); also elsewhere on the board
SECONDARY-C8: IC301.10 (C8); also elsewhere on the board
SECONDARY-C9: IC301.8 (C9); also elsewhere on the board
SECONDARY-C10: IC301.6 (C10); also elsewhere on the board
SECONDARY-C11: IC301.4 (C11); also elsewhere on the board
SECONDARY-C12: IC301.2 (C12); also elsewhere on the board
SECONDARY-GPIO0: IC301.27 (GPIO1), R309.2, R310.2
SECONDARY-GPIO1: IC301.28 (GPIO2), R311.2, R312.2
SECONDARY-GPIO1-OPT: R309.1; also elsewhere on the board
SECONDARY-GPIO2-OPT: R311.1; also elsewhere on the board
SECONDARY-GPIO3-OPT: R313.1; also elsewhere on the board
SECONDARY-GPIO4: IC301.33 (GPIO5), R317.2, R318.2
SECONDARY-GPIO4-OPT: R315.1; also elsewhere on the board
SECONDARY-GPIO5: IC301.29 (GPIO3), R313.2, R314.2
SECONDARY-GPIO5-OPT: R317.1; also elsewhere on the board
SECONDARY-IN+: TP301.P$1, TR301.4 (D+); also elsewhere on the board
SECONDARY-IN-: TR301.6 (D-); also elsewhere on the board
SECONDARY-IN_N1: IC301.41 (CSB/IMA), R304.2, TR301.7 (X-)
SECONDARY-IN_P1: IC301.42 (SCK/IPA), R304.1, TR301.9 (X+)
SECONDARY-MUX-DATA_TEMP: R310.1; also elsewhere on the board
SECONDARY-MUX-DATA_USER: R312.1; also elsewhere on the board
SECONDARY-OUT+: TP307.P$1, TR301.1 (D+); also elsewhere on the board
SECONDARY-OUT-: TR301.3 (D-); also elsewhere on the board
SECONDARY-OUT_N1: IC301.47 (IMB), R307.2, TR301.10 (X-)
SECONDARY-OUT_P1: IC301.48 (IPB), R307.1, TR301.12 (X+)
SECONDARY-SCL_1: R318.1, R323.1, TP310.P$1; also elsewhere on the board
SECONDARY-SDA_1: R316.1, R322.1, TP309.P$1; also elsewhere on the board
SECONDARY-WDT: IC301.39 (WDT), R319.1; also elsewhere on the board

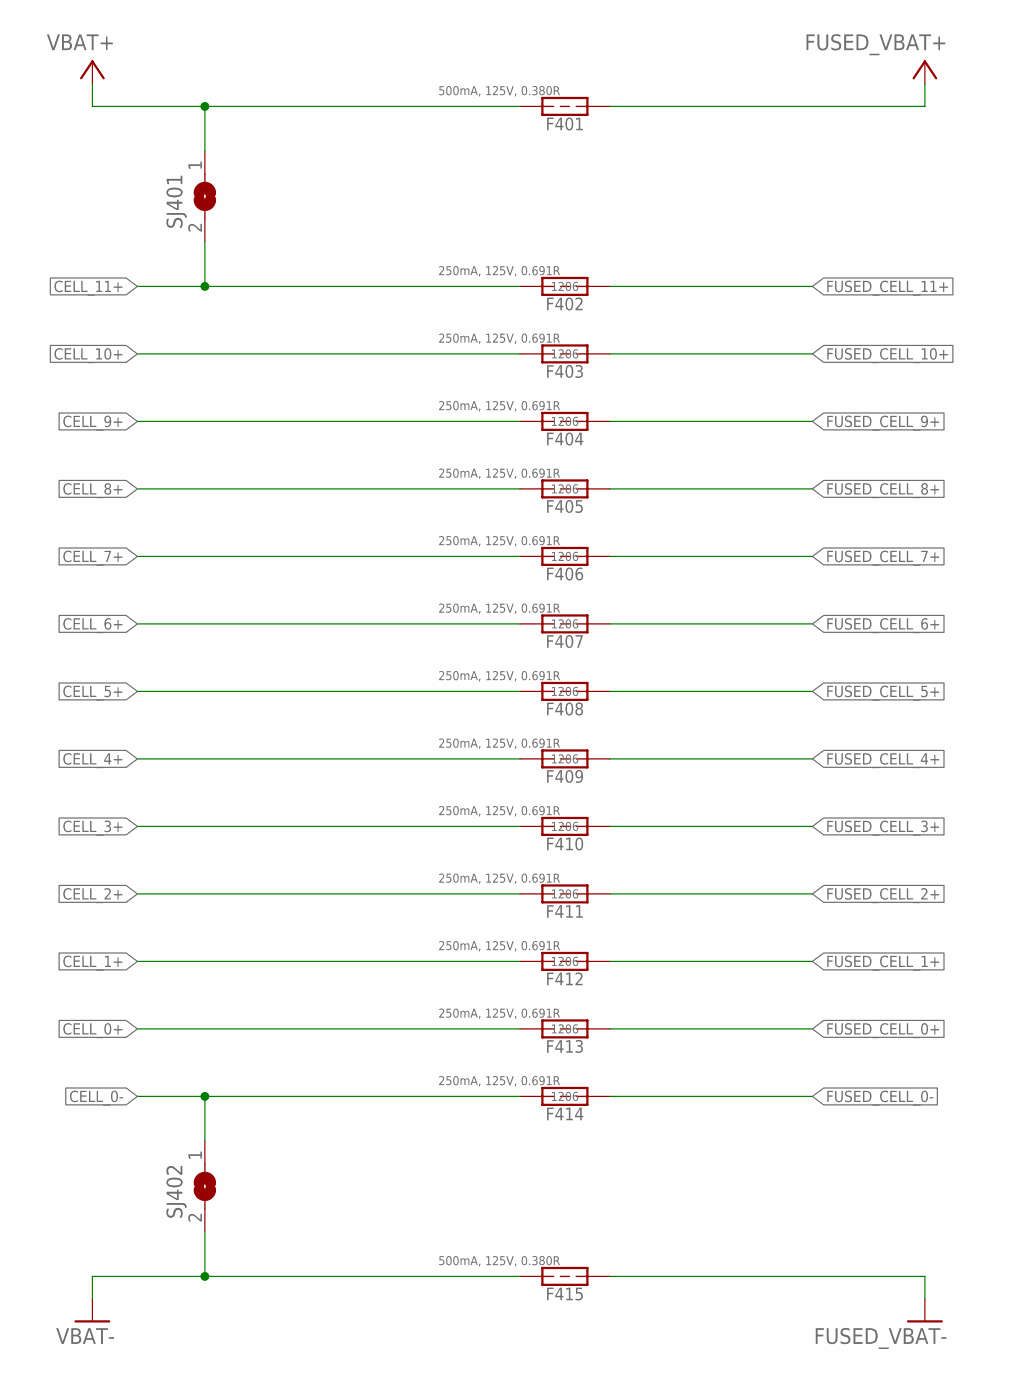
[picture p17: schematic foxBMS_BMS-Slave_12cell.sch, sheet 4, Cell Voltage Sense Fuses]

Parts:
F401, F415: 0.5A, 63V, 0.25R; 448_SERIES_LITTELFUSE
F402, F403, F404, F405, F406, F407, F408, F409, F410, F411, F412, F413, F414: FUSE: 0.250A, 32V, 0.57R; R_SMD_CHIP_1206_R_LITTLEFUSE_REV_01
SJ401, SJ402: SJ

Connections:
CELL_0+: F413.P$1; also elsewhere on the board
CELL_0-: F414.P$1, SJ402.1; also elsewhere on the board
CELL_1+: F412.P$1; also elsewhere on the board
CELL_2+: F411.P$1; also elsewhere on the board
CELL_3+: F410.P$1; also elsewhere on the board
CELL_4+: F409.P$1; also elsewhere on the board
CELL_5+: F408.P$1; also elsewhere on the board
CELL_6+: F407.P$1; also elsewhere on the board
CELL_7+: F406.P$1; also elsewhere on the board
CELL_8+: F405.P$1; also elsewhere on the board
CELL_9+: F404.P$1; also elsewhere on the board
CELL_10+: F403.P$1; also elsewhere on the board
CELL_11+: F402.P$1, SJ401.2; also elsewhere on the board
FUSED_CELL_0+: F413.P$2; also elsewhere on the board
FUSED_CELL_0-: F414.P$2; also elsewhere on the board
FUSED_CELL_1+: F412.P$2; also elsewhere on the board
FUSED_CELL_2+: F411.P$2; also elsewhere on the board
FUSED_CELL_3+: F410.P$2; also elsewhere on the board
FUSED_CELL_4+: F409.P$2; also elsewhere on the board
FUSED_CELL_5+: F408.P$2; also elsewhere on the board
FUSED_CELL_6+: F407.P$2; also elsewhere on the board
FUSED_CELL_7+: F406.P$2; also elsewhere on the board
FUSED_CELL_8+: F405.P$2; also elsewhere on the board
FUSED_CELL_9+: F404.P$2; also elsewhere on the board
FUSED_CELL_10+: F403.P$2; also elsewhere on the board
FUSED_CELL_11+: F402.P$2; also elsewhere on the board
FUSED_VBAT+: F401.P$2; also elsewhere on the board
FUSED_VBAT-: F415.P$2; also elsewhere on the board
VBAT+: F401.P$1, SJ401.1; also elsewhere on the board
VBAT-: F415.P$1, SJ402.2; also elsewhere on the board

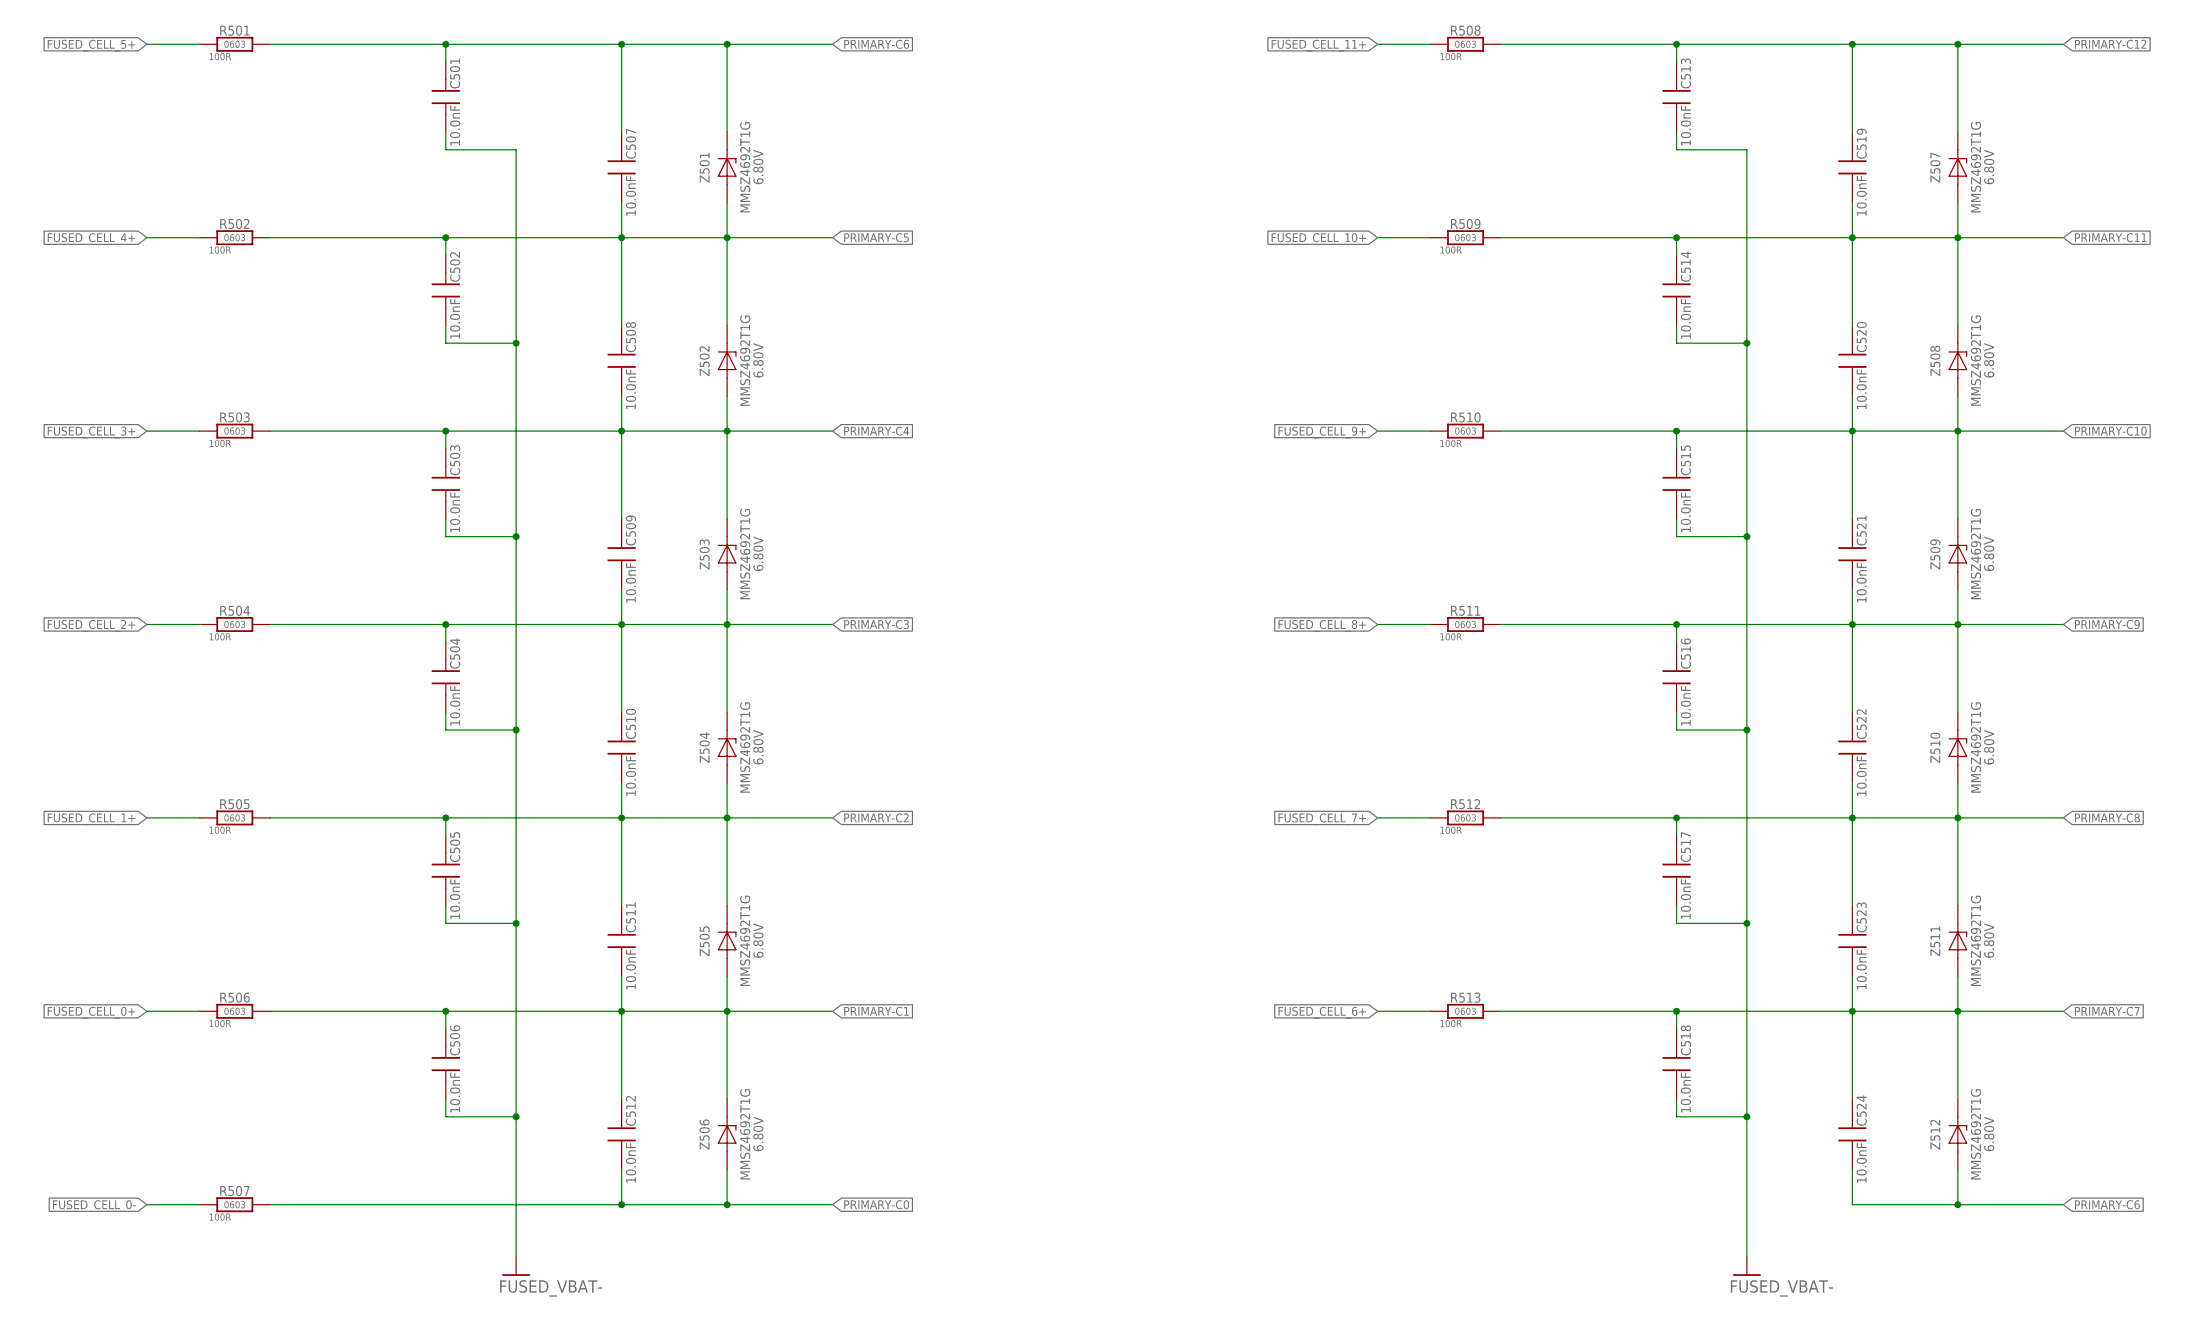
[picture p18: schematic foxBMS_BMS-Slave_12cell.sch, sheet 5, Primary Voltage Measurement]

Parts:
C501, C502, C503, C504, C505, C506, C507, C508, C509, C510, C511, C512, C513, C514, C515, C516, C517, C518, C519, C520, C521, C522, C523, C524: 10nF, 100V, 10%; C_SMD_0603_(1608)_R_KEMET_REV01
R501, R502, R503, R504, R505, R506, R507, R508, R509, R510, R511, R512, R513: 100R_0603_R_VISHAY_1%_TK100_REV_01; R_SMD_0603_R_VISHAY_REV01
Z501, Z502, Z503, Z504, Z505, Z506, Z507, Z508, Z509, Z510, Z511, Z512: 6.8V, 500mW; D_SMD_SOD-123_R_ON_REV01

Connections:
FUSED_CELL_0+: R506.1; also elsewhere on the board
FUSED_CELL_0-: R507.1; also elsewhere on the board
FUSED_CELL_1+: R505.1; also elsewhere on the board
FUSED_CELL_2+: R504.1; also elsewhere on the board
FUSED_CELL_3+: R503.1; also elsewhere on the board
FUSED_CELL_4+: R502.1; also elsewhere on the board
FUSED_CELL_5+: R501.1; also elsewhere on the board
FUSED_CELL_6+: R513.1; also elsewhere on the board
FUSED_CELL_7+: R512.1; also elsewhere on the board
FUSED_CELL_8+: R511.1; also elsewhere on the board
FUSED_CELL_9+: R510.1; also elsewhere on the board
FUSED_CELL_10+: R509.1; also elsewhere on the board
FUSED_CELL_11+: R508.1; also elsewhere on the board
FUSED_VBAT-: C501.2, C502.2, C503.2, C504.2, C505.2, C506.2, C513.2, C514.2, C515.2, C516.2, C517.2, C518.2; also elsewhere on the board
PRIMARY-C0: C512.2, R507.2, Z506.A; also elsewhere on the board
PRIMARY-C1: C506.1, C511.2, C512.1, R506.2, Z505.A, Z506.K (C); also elsewhere on the board
PRIMARY-C2: C505.1, C510.2, C511.1, R505.2, Z504.A, Z505.K (C); also elsewhere on the board
PRIMARY-C3: C504.1, C509.2, C510.1, R504.2, Z503.A, Z504.K (C); also elsewhere on the board
PRIMARY-C4: C503.1, C508.2, C509.1, R503.2, Z502.A, Z503.K (C); also elsewhere on the board
PRIMARY-C5: C502.1, C507.2, C508.1, R502.2, Z501.A, Z502.K (C); also elsewhere on the board
PRIMARY-C6: C501.1, C507.1, C524.2, R501.2, Z501.K (C), Z512.A; also elsewhere on the board
PRIMARY-C7: C518.1, C523.2, C524.1, R513.2, Z511.A, Z512.K (C); also elsewhere on the board
PRIMARY-C8: C517.1, C522.2, C523.1, R512.2, Z510.A, Z511.K (C); also elsewhere on the board
PRIMARY-C9: C516.1, C521.2, C522.1, R511.2, Z509.A, Z510.K (C); also elsewhere on the board
PRIMARY-C10: C515.1, C520.2, C521.1, R510.2, Z508.A, Z509.K (C); also elsewhere on the board
PRIMARY-C11: C514.1, C519.2, C520.1, R509.2, Z507.A, Z508.K (C); also elsewhere on the board
PRIMARY-C12: C513.1, C519.1, R508.2, Z507.K (C); also elsewhere on the board

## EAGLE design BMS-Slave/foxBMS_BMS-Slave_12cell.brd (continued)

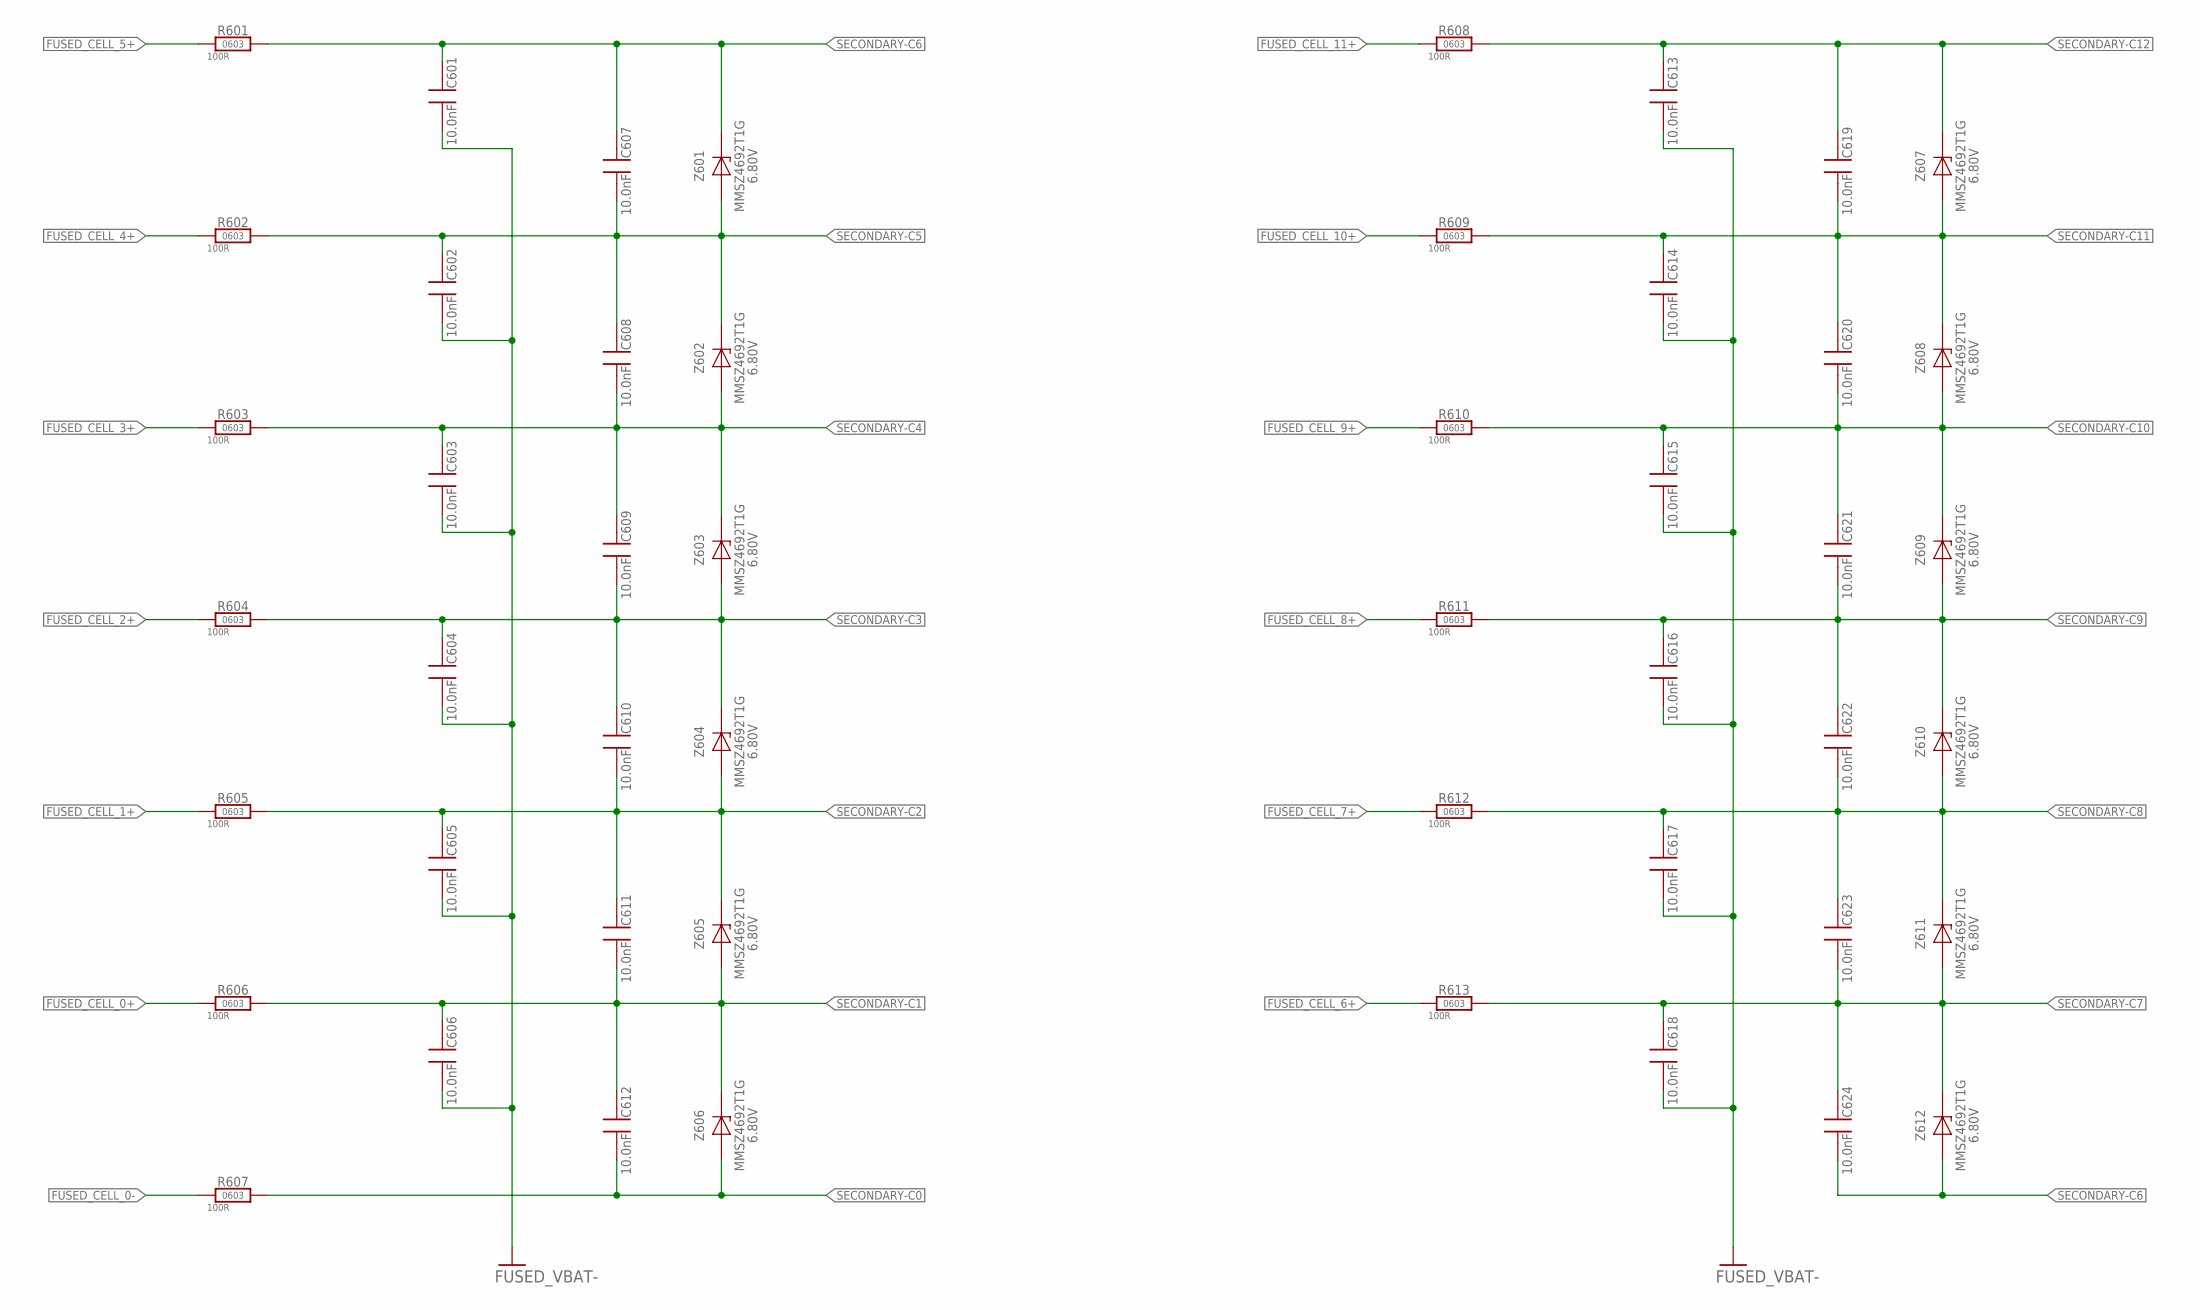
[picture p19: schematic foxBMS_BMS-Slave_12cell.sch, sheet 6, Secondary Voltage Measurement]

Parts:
C601, C602, C603, C604, C605, C606, C607, C608, C609, C610, C611, C612, C613, C614, C615, C616, C617, C618, C619, C620, C621, C622, C623, C624: 10nF, 100V, 10%; C_SMD_0603_(1608)_R_KEMET_REV01
R601, R602, R603, R604, R605, R606, R607, R608, R609, R610, R611, R612, R613: 100R_0603_R_VISHAY_1%_TK100_REV_01; R_SMD_0603_R_VISHAY_REV01
Z601, Z602, Z603, Z604, Z605, Z606, Z607, Z608, Z609, Z610, Z611, Z612: 6.8V, 500mW; D_SMD_SOD-123_R_ON_REV01

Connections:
FUSED_CELL_0+: R606.1; also elsewhere on the board
FUSED_CELL_0-: R607.1; also elsewhere on the board
FUSED_CELL_1+: R605.1; also elsewhere on the board
FUSED_CELL_2+: R604.1; also elsewhere on the board
FUSED_CELL_3+: R603.1; also elsewhere on the board
FUSED_CELL_4+: R602.1; also elsewhere on the board
FUSED_CELL_5+: R601.1; also elsewhere on the board
FUSED_CELL_6+: R613.1; also elsewhere on the board
FUSED_CELL_7+: R612.1; also elsewhere on the board
FUSED_CELL_8+: R611.1; also elsewhere on the board
FUSED_CELL_9+: R610.1; also elsewhere on the board
FUSED_CELL_10+: R609.1; also elsewhere on the board
FUSED_CELL_11+: R608.1; also elsewhere on the board
FUSED_VBAT-: C601.2, C602.2, C603.2, C604.2, C605.2, C606.2, C613.2, C614.2, C615.2, C616.2, C617.2, C618.2; also elsewhere on the board
SECONDARY-C0: C612.2, R607.2, Z606.A; also elsewhere on the board
SECONDARY-C1: C606.1, C611.2, C612.1, R606.2, Z605.A, Z606.K (C); also elsewhere on the board
SECONDARY-C2: C605.1, C610.2, C611.1, R605.2, Z604.A, Z605.K (C); also elsewhere on the board
SECONDARY-C3: C604.1, C609.2, C610.1, R604.2, Z603.A, Z604.K (C); also elsewhere on the board
SECONDARY-C4: C603.1, C608.2, C609.1, R603.2, Z602.A, Z603.K (C); also elsewhere on the board
SECONDARY-C5: C602.1, C607.2, C608.1, R602.2, Z601.A, Z602.K (C); also elsewhere on the board
SECONDARY-C6: C601.1, C607.1, C624.2, R601.2, Z601.K (C), Z612.A; also elsewhere on the board
SECONDARY-C7: C618.1, C623.2, C624.1, R613.2, Z611.A, Z612.K (C); also elsewhere on the board
SECONDARY-C8: C617.1, C622.2, C623.1, R612.2, Z610.A, Z611.K (C); also elsewhere on the board
SECONDARY-C9: C616.1, C621.2, C622.1, R611.2, Z609.A, Z610.K (C); also elsewhere on the board
SECONDARY-C10: C615.1, C620.2, C621.1, R610.2, Z608.A, Z609.K (C); also elsewhere on the board
SECONDARY-C11: C614.1, C619.2, C620.1, R609.2, Z607.A, Z608.K (C); also elsewhere on the board
SECONDARY-C12: C613.1, C619.1, R608.2, Z607.K (C); also elsewhere on the board

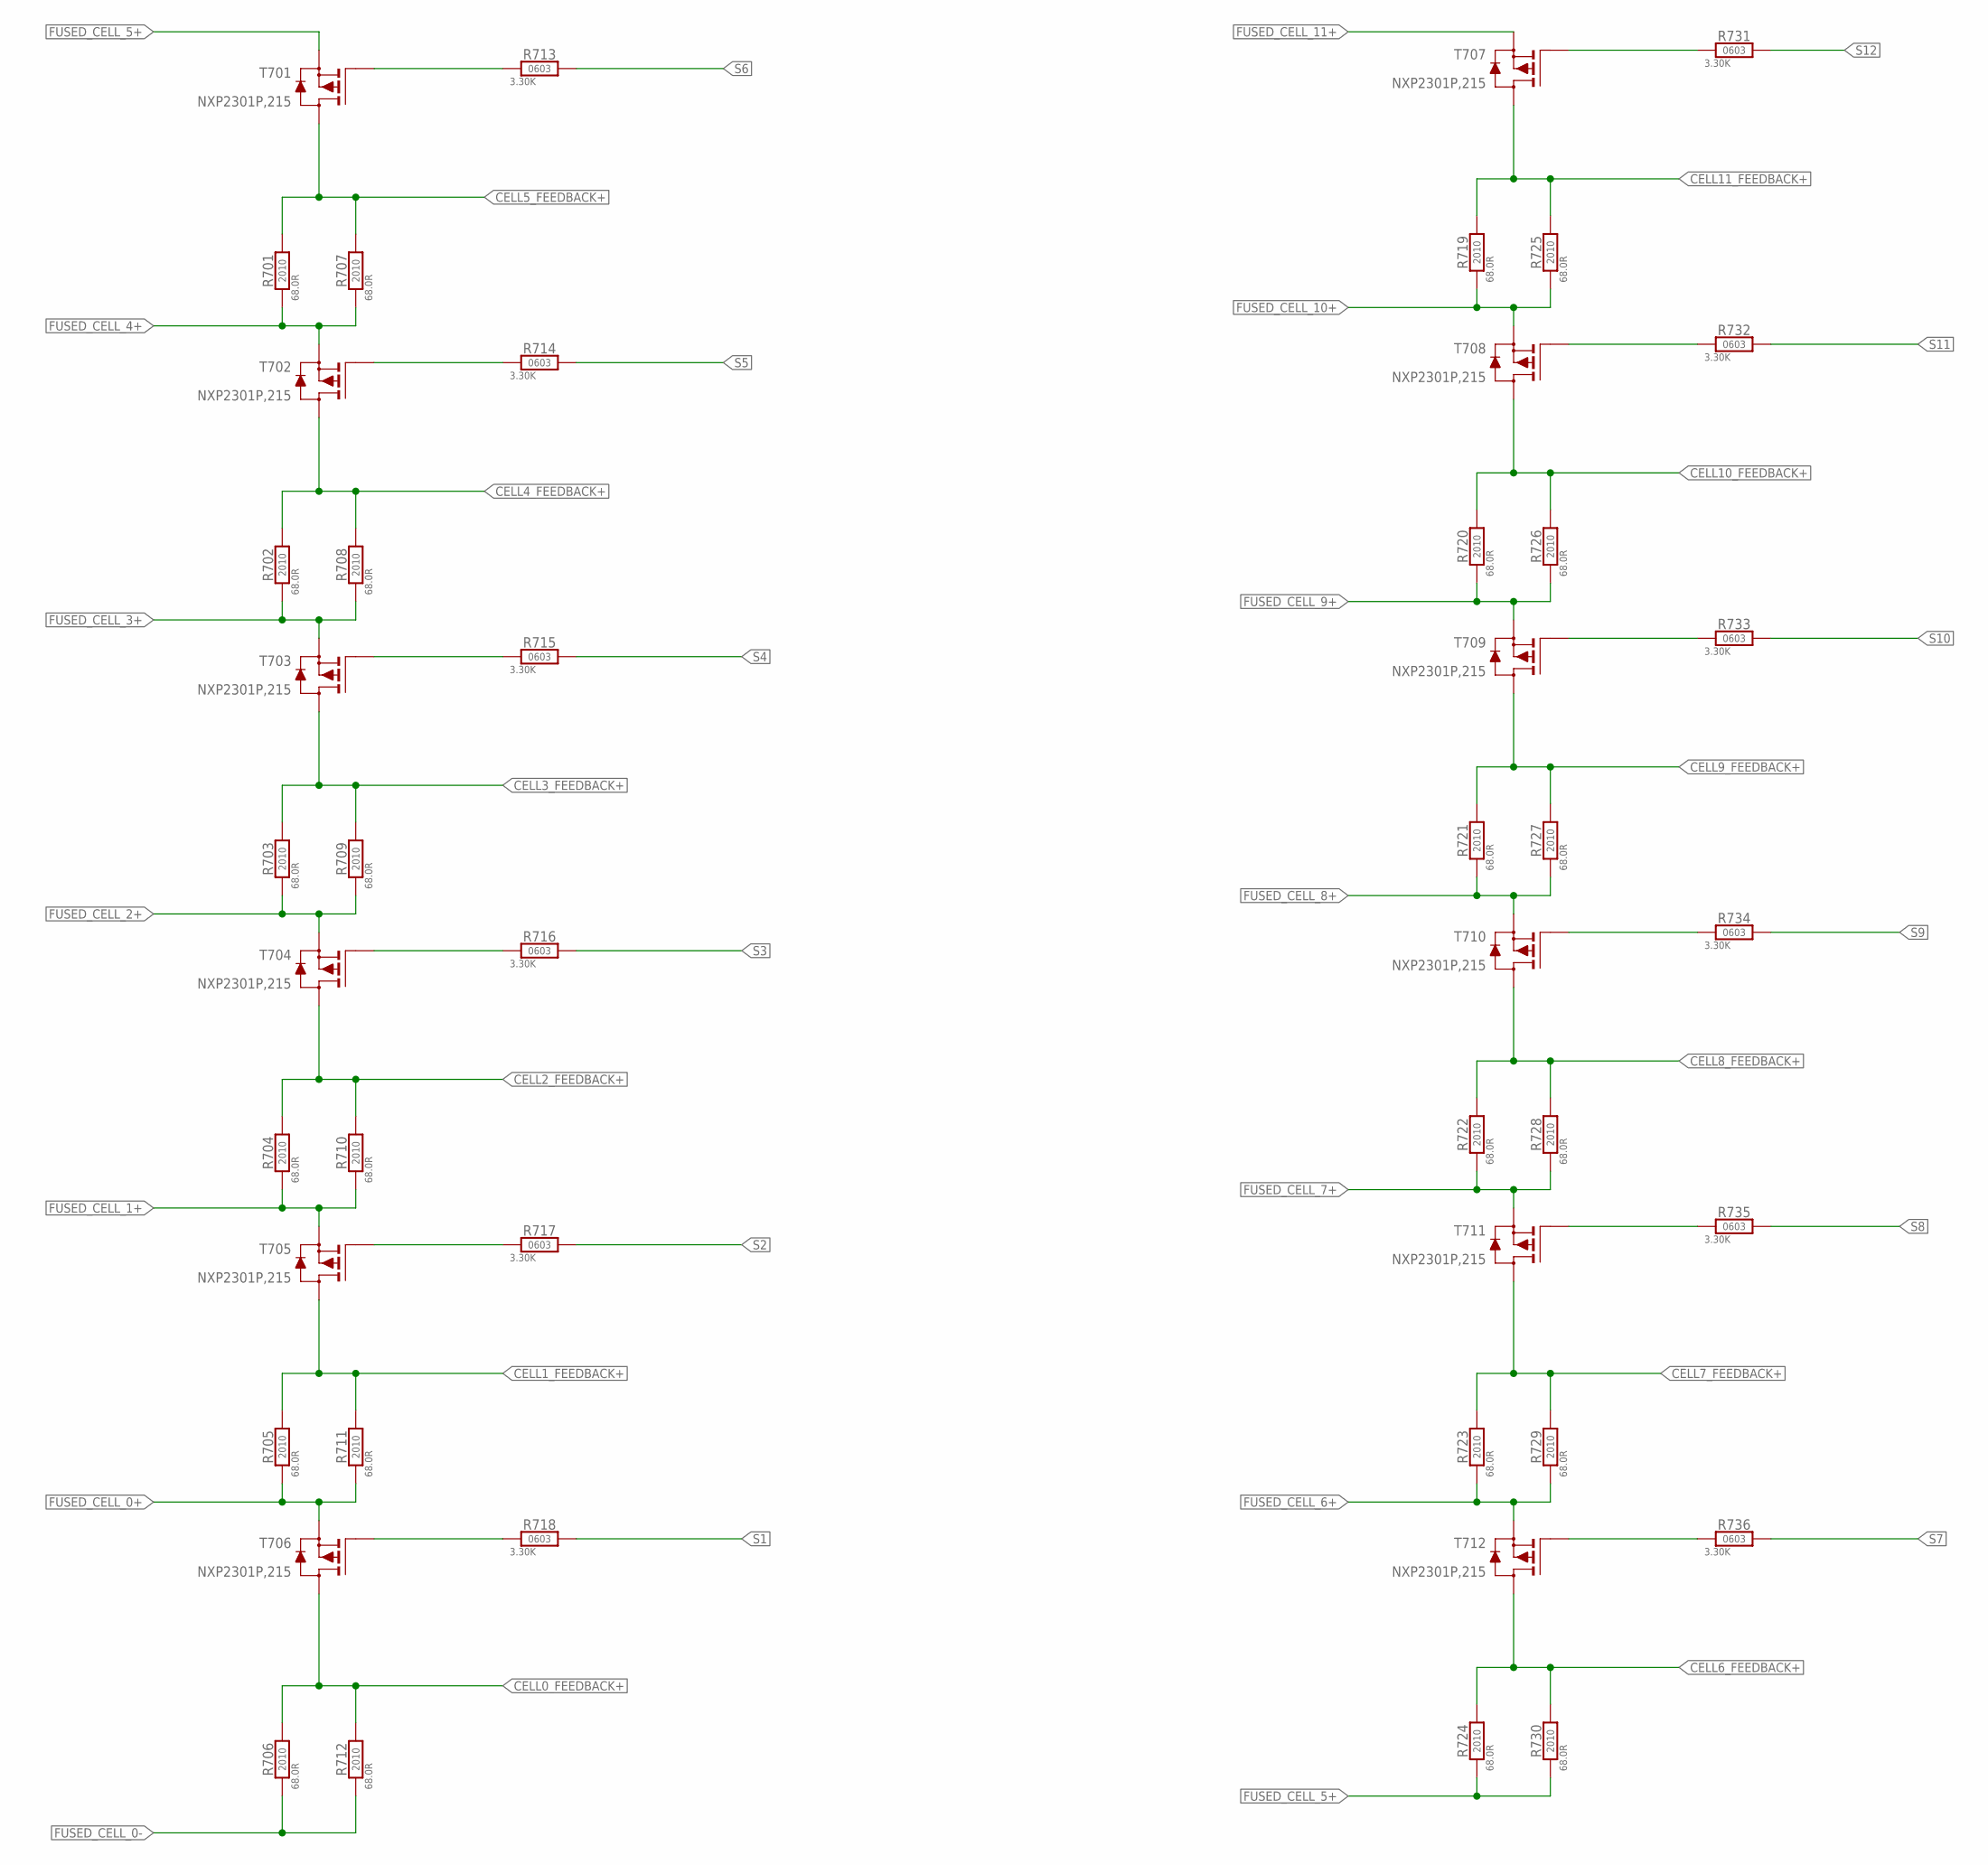
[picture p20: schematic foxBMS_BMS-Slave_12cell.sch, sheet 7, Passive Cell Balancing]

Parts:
R701, R702, R703, R704, R705, R706, R707, R708, R709, R710, R711, R712, R719, R720, R721, R722, R723, R724, R725, R726, R727, R728, R729, R730: 72R, 1%; R_SMD_2010_R_YAGEO_REV01
R713, R714, R715, R716, R717, R718, R731, R732, R733, R734, R735, R736: 3.3k, 10%, 1/10W; R_SMD_0603_R_VISHAY_REV01
T701, T702, T703, T704, T705, T706, T707, T708, T709, T710, T711, T712: NX2301P; D_SMD_SOT23_(TO-236AB)_R_NXP_REV01

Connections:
CELL0_FEEDBACK+: R706.P$2 (2), R712.P$2 (2), T706.3 (D); also elsewhere on the board
CELL1_FEEDBACK+: R705.P$2 (2), R711.P$2 (2), T705.3 (D); also elsewhere on the board
CELL2_FEEDBACK+: R704.P$2 (2), R710.P$2 (2), T704.3 (D); also elsewhere on the board
CELL3_FEEDBACK+: R703.P$2 (2), R709.P$2 (2), T703.3 (D); also elsewhere on the board
CELL4_FEEDBACK+: R702.P$2 (2), R708.P$2 (2), T702.3 (D); also elsewhere on the board
CELL5_FEEDBACK+: R701.P$2 (2), R707.P$2 (2), T701.3 (D); also elsewhere on the board
CELL6_FEEDBACK+: R724.P$2 (2), R730.P$2 (2), T712.3 (D); also elsewhere on the board
CELL7_FEEDBACK+: R723.P$2 (2), R729.P$2 (2), T711.3 (D); also elsewhere on the board
CELL8_FEEDBACK+: R722.P$2 (2), R728.P$2 (2), T710.3 (D); also elsewhere on the board
CELL9_FEEDBACK+: R721.P$2 (2), R727.P$2 (2), T709.3 (D); also elsewhere on the board
CELL10_FEEDBACK+: R720.P$2 (2), R726.P$2 (2), T708.3 (D); also elsewhere on the board
CELL11_FEEDBACK+: R719.P$2 (2), R725.P$2 (2), T707.3 (D); also elsewhere on the board
FUSED_CELL_0+: R705.P$1 (1), R711.P$1 (1), T706.2 (S); also elsewhere on the board
FUSED_CELL_0-: R706.P$1 (1), R712.P$1 (1); also elsewhere on the board
FUSED_CELL_1+: R704.P$1 (1), R710.P$1 (1), T705.2 (S); also elsewhere on the board
FUSED_CELL_2+: R703.P$1 (1), R709.P$1 (1), T704.2 (S); also elsewhere on the board
FUSED_CELL_3+: R702.P$1 (1), R708.P$1 (1), T703.2 (S); also elsewhere on the board
FUSED_CELL_4+: R701.P$1 (1), R707.P$1 (1), T702.2 (S); also elsewhere on the board
FUSED_CELL_5+: R724.P$1 (1), R730.P$1 (1), T701.2 (S); also elsewhere on the board
FUSED_CELL_6+: R723.P$1 (1), R729.P$1 (1), T712.2 (S); also elsewhere on the board
FUSED_CELL_7+: R722.P$1 (1), R728.P$1 (1), T711.2 (S); also elsewhere on the board
FUSED_CELL_8+: R721.P$1 (1), R727.P$1 (1), T710.2 (S); also elsewhere on the board
FUSED_CELL_9+: R720.P$1 (1), R726.P$1 (1), T709.2 (S); also elsewhere on the board
FUSED_CELL_10+: R719.P$1 (1), R725.P$1 (1), T708.2 (S); also elsewhere on the board
FUSED_CELL_11+: T707.2 (S); also elsewhere on the board
unnamed: R718.1, T706.1 (G)
unnamed: R717.1, T705.1 (G)
unnamed: R716.1, T704.1 (G)
unnamed: R715.1, T703.1 (G)
unnamed: R714.1, T702.1 (G)
unnamed: R713.1, T701.1 (G)
unnamed: R736.1, T712.1 (G)
unnamed: R735.1, T711.1 (G)
unnamed: R734.1, T710.1 (G)
unnamed: R733.1, T709.1 (G)
unnamed: R732.1, T708.1 (G)
unnamed: R731.1, T707.1 (G)
S1: R718.2; also elsewhere on the board
S2: R717.2; also elsewhere on the board
S3: R716.2; also elsewhere on the board
S4: R715.2; also elsewhere on the board
S5: R714.2; also elsewhere on the board
S6: R713.2; also elsewhere on the board
S7: R736.2; also elsewhere on the board
S8: R735.2; also elsewhere on the board
S9: R734.2; also elsewhere on the board
S10: R733.2; also elsewhere on the board
S11: R732.2; also elsewhere on the board
S12: R731.2; also elsewhere on the board

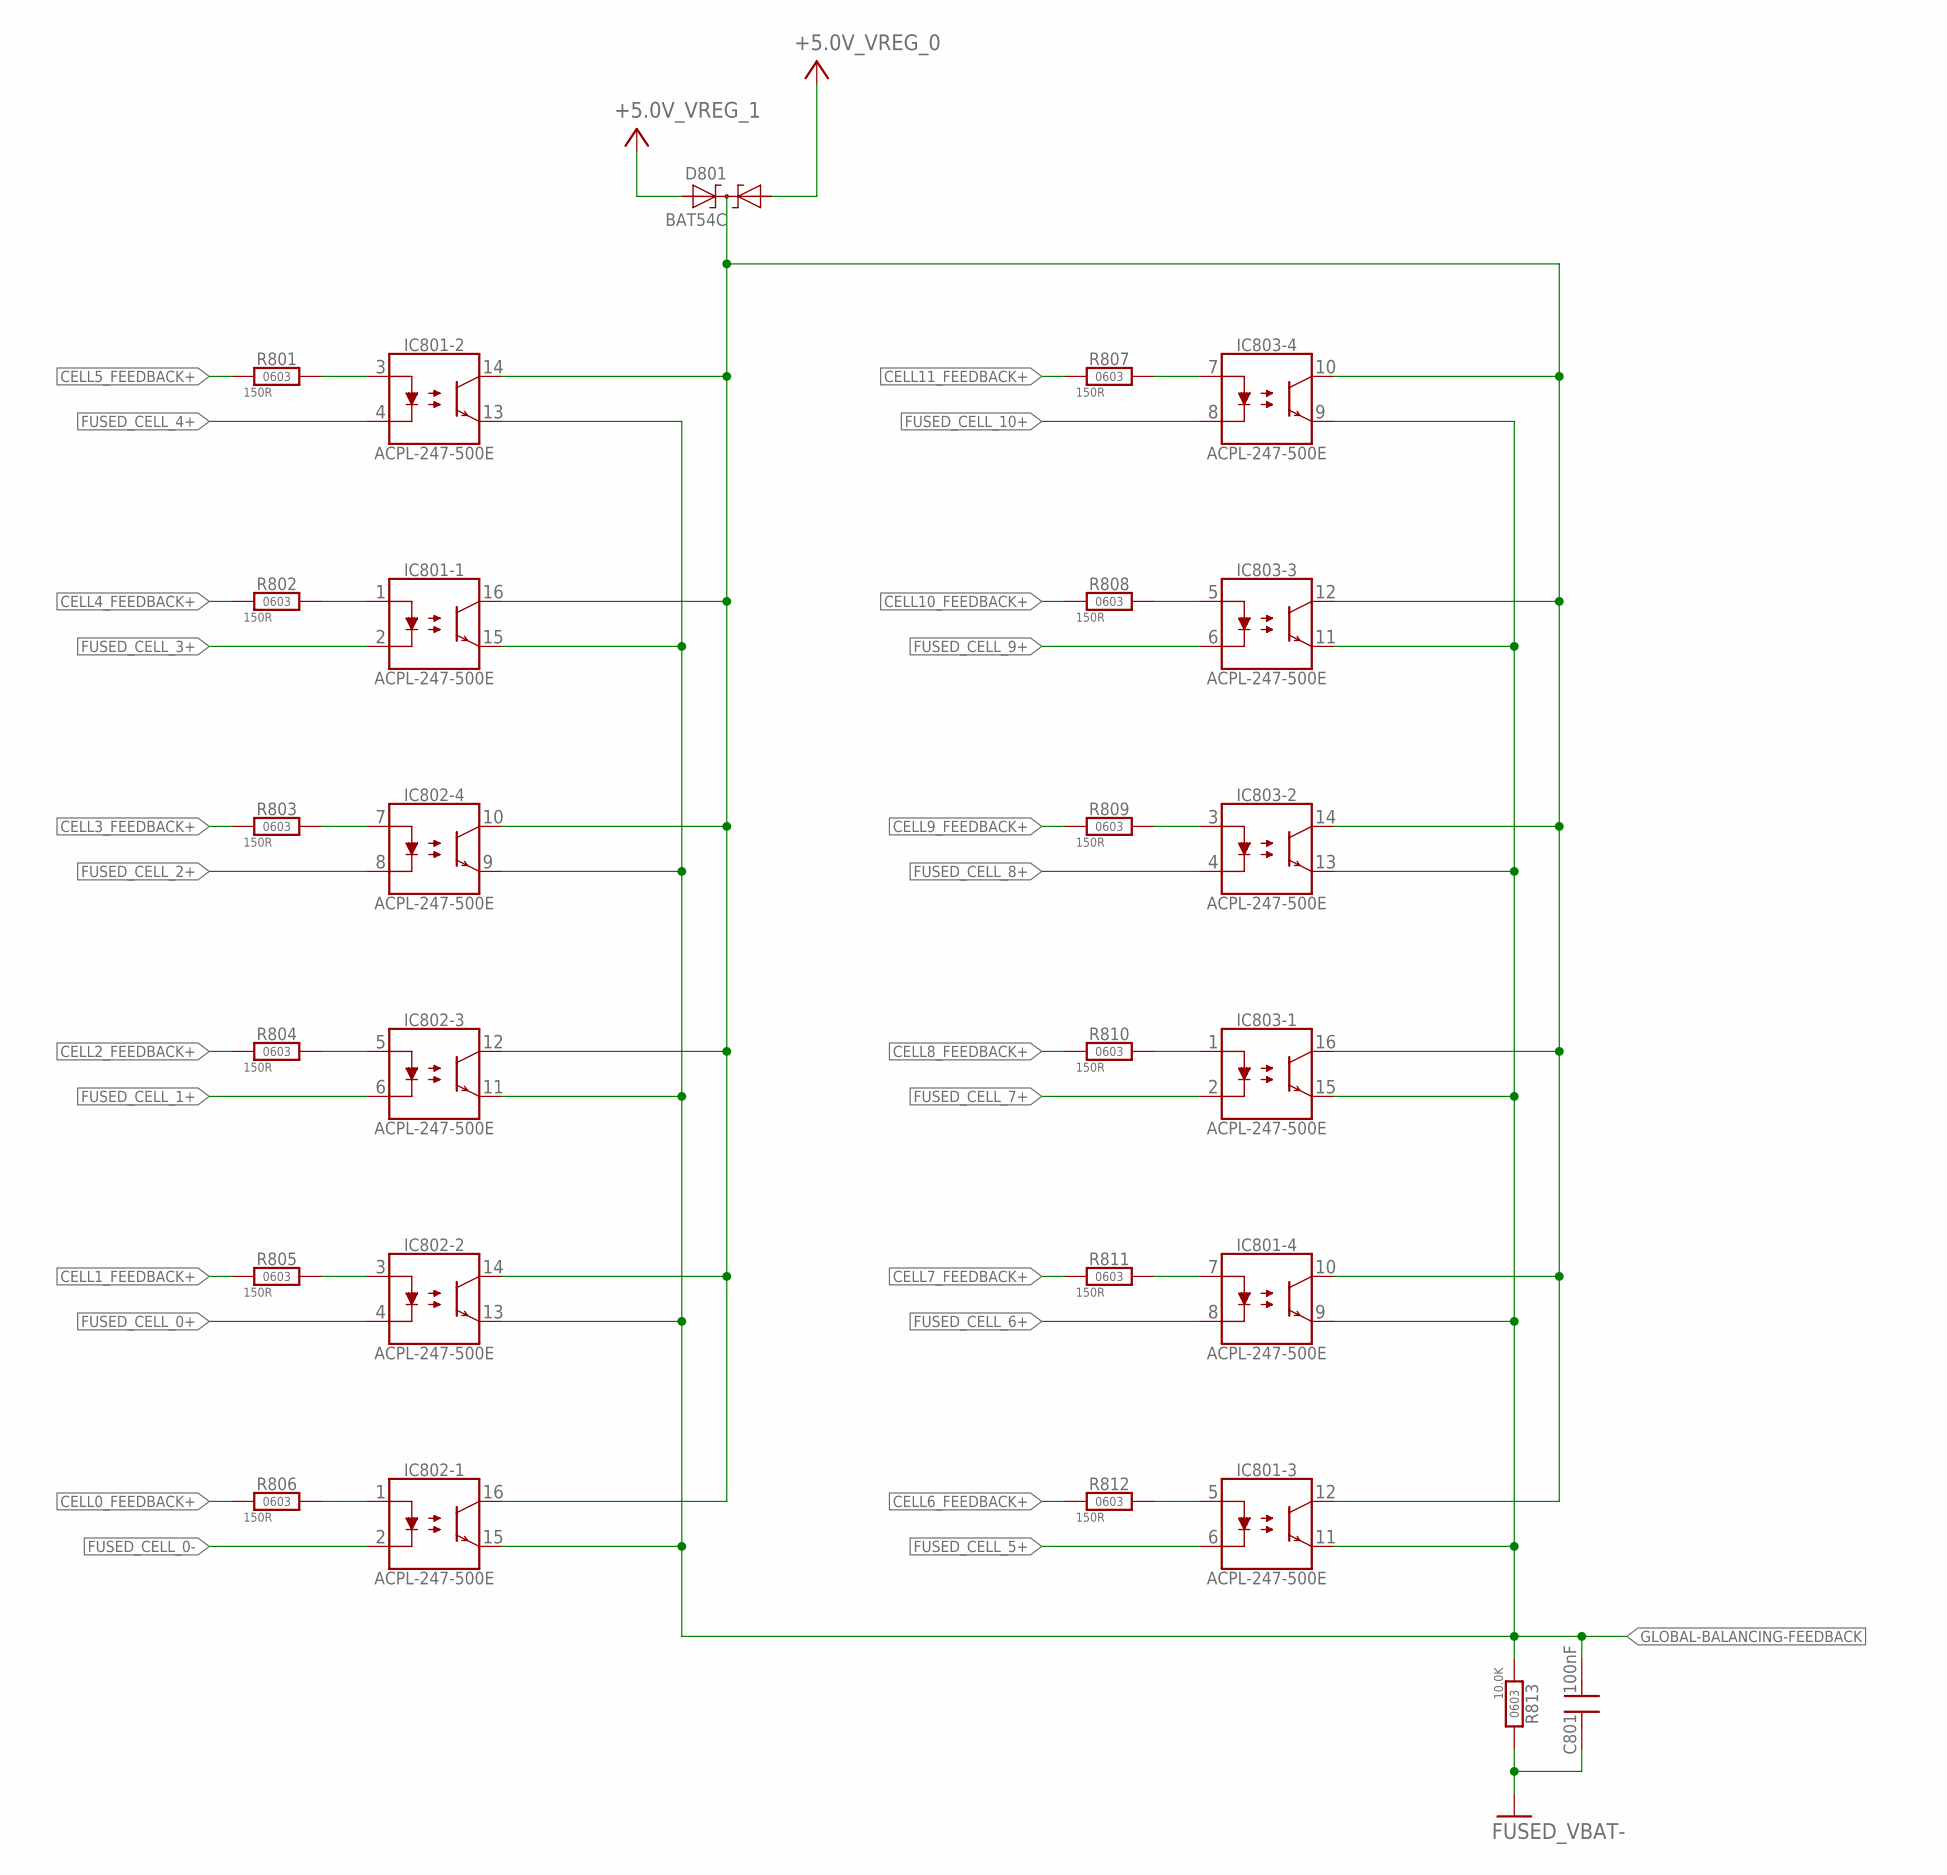
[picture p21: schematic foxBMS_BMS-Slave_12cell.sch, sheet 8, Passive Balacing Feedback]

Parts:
C801: 100nF, 20%, 16V; C_SMD_0603_(1608)_R_KEMET_REV01
D801: BAT54C; D_SMD_SOT23_(TO-236AB)_R_NXP_REV01
IC801, IC802, IC803: ACPL-247-500E; OC_SMD_SOIC-16_R_AVAGO_REV01
R801, R802, R803, R804, R805, R806, R807, R808, R809, R810, R811, R812: 150R_0603_R_VISHAY_1%_TK100_REV_01; R_SMD_0603_R_VISHAY_REV01
R813: 10,0K_0603_R_VISHAY_1%_TK100_REV_01; R_SMD_0603_R_VISHAY_REV01

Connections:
+5.0V_VREG_0: D801.2 (A2); also elsewhere on the board
+5.0V_VREG_1: D801.1 (A1); also elsewhere on the board
CELL0_FEEDBACK+: R806.1; also elsewhere on the board
CELL1_FEEDBACK+: R805.1; also elsewhere on the board
CELL2_FEEDBACK+: R804.1; also elsewhere on the board
CELL3_FEEDBACK+: R803.1; also elsewhere on the board
CELL4_FEEDBACK+: R802.1; also elsewhere on the board
CELL5_FEEDBACK+: R801.1; also elsewhere on the board
CELL6_FEEDBACK+: R812.1; also elsewhere on the board
CELL7_FEEDBACK+: R811.1; also elsewhere on the board
CELL8_FEEDBACK+: R810.1; also elsewhere on the board
CELL9_FEEDBACK+: R809.1; also elsewhere on the board
CELL10_FEEDBACK+: R808.1; also elsewhere on the board
CELL11_FEEDBACK+: R807.1; also elsewhere on the board
FUSED_CELL_0+: IC802.4 (K); also elsewhere on the board
FUSED_CELL_0-: IC802.2 (K); also elsewhere on the board
FUSED_CELL_1+: IC802.6 (K); also elsewhere on the board
FUSED_CELL_2+: IC802.8 (K); also elsewhere on the board
FUSED_CELL_3+: IC801.2 (K); also elsewhere on the board
FUSED_CELL_4+: IC801.4 (K); also elsewhere on the board
FUSED_CELL_5+: IC801.6 (K); also elsewhere on the board
FUSED_CELL_6+: IC801.8 (K); also elsewhere on the board
FUSED_CELL_7+: IC803.2 (K); also elsewhere on the board
FUSED_CELL_8+: IC803.4 (K); also elsewhere on the board
FUSED_CELL_9+: IC803.6 (K); also elsewhere on the board
FUSED_CELL_10+: IC803.8 (K); also elsewhere on the board
FUSED_VBAT-: C801.1, R813.2; also elsewhere on the board
GLOBAL-BALANCING-FEEDBACK: C801.2, IC801.9 (V_EMITTER), IC801.11 (V_EMITTER), IC801.13 (V_EMITTER), IC801.15 (V_EMITTER), IC802.9 (V_EMITTER), IC802.11 (V_EMITTER), IC802.13 (V_EMITTER), IC802.15 (V_EMITTER), IC803.9 (V_EMITTER), IC803.11 (V_EMITTER), IC803.13 (V_EMITTER), IC803.15 (V_EMITTER), R813.1; also elsewhere on the board
unnamed: D801.3 (C), IC801.10 (V_COLLECTOR), IC801.12 (V_COLLECTOR), IC801.14 (V_COLLECTOR), IC801.16 (V_COLLECTOR), IC802.10 (V_COLLECTOR), IC802.12 (V_COLLECTOR), IC802.14 (V_COLLECTOR), IC802.16 (V_COLLECTOR), IC803.10 (V_COLLECTOR), IC803.12 (V_COLLECTOR), IC803.14 (V_COLLECTOR), IC803.16 (V_COLLECTOR)
unnamed: IC801.1 (A), R802.2
unnamed: IC802.7 (A), R803.2
unnamed: IC802.5 (A), R804.2
unnamed: IC803.5 (A), R808.2
unnamed: IC803.3 (A), R809.2
unnamed: IC802.3 (A), R805.2
unnamed: IC803.7 (A), R807.2
unnamed: IC803.1 (A), R810.2
unnamed: IC801.7 (A), R811.2
unnamed: IC802.1 (A), R806.2
unnamed: IC801.5 (A), R812.2
unnamed: IC801.3 (A), R801.2

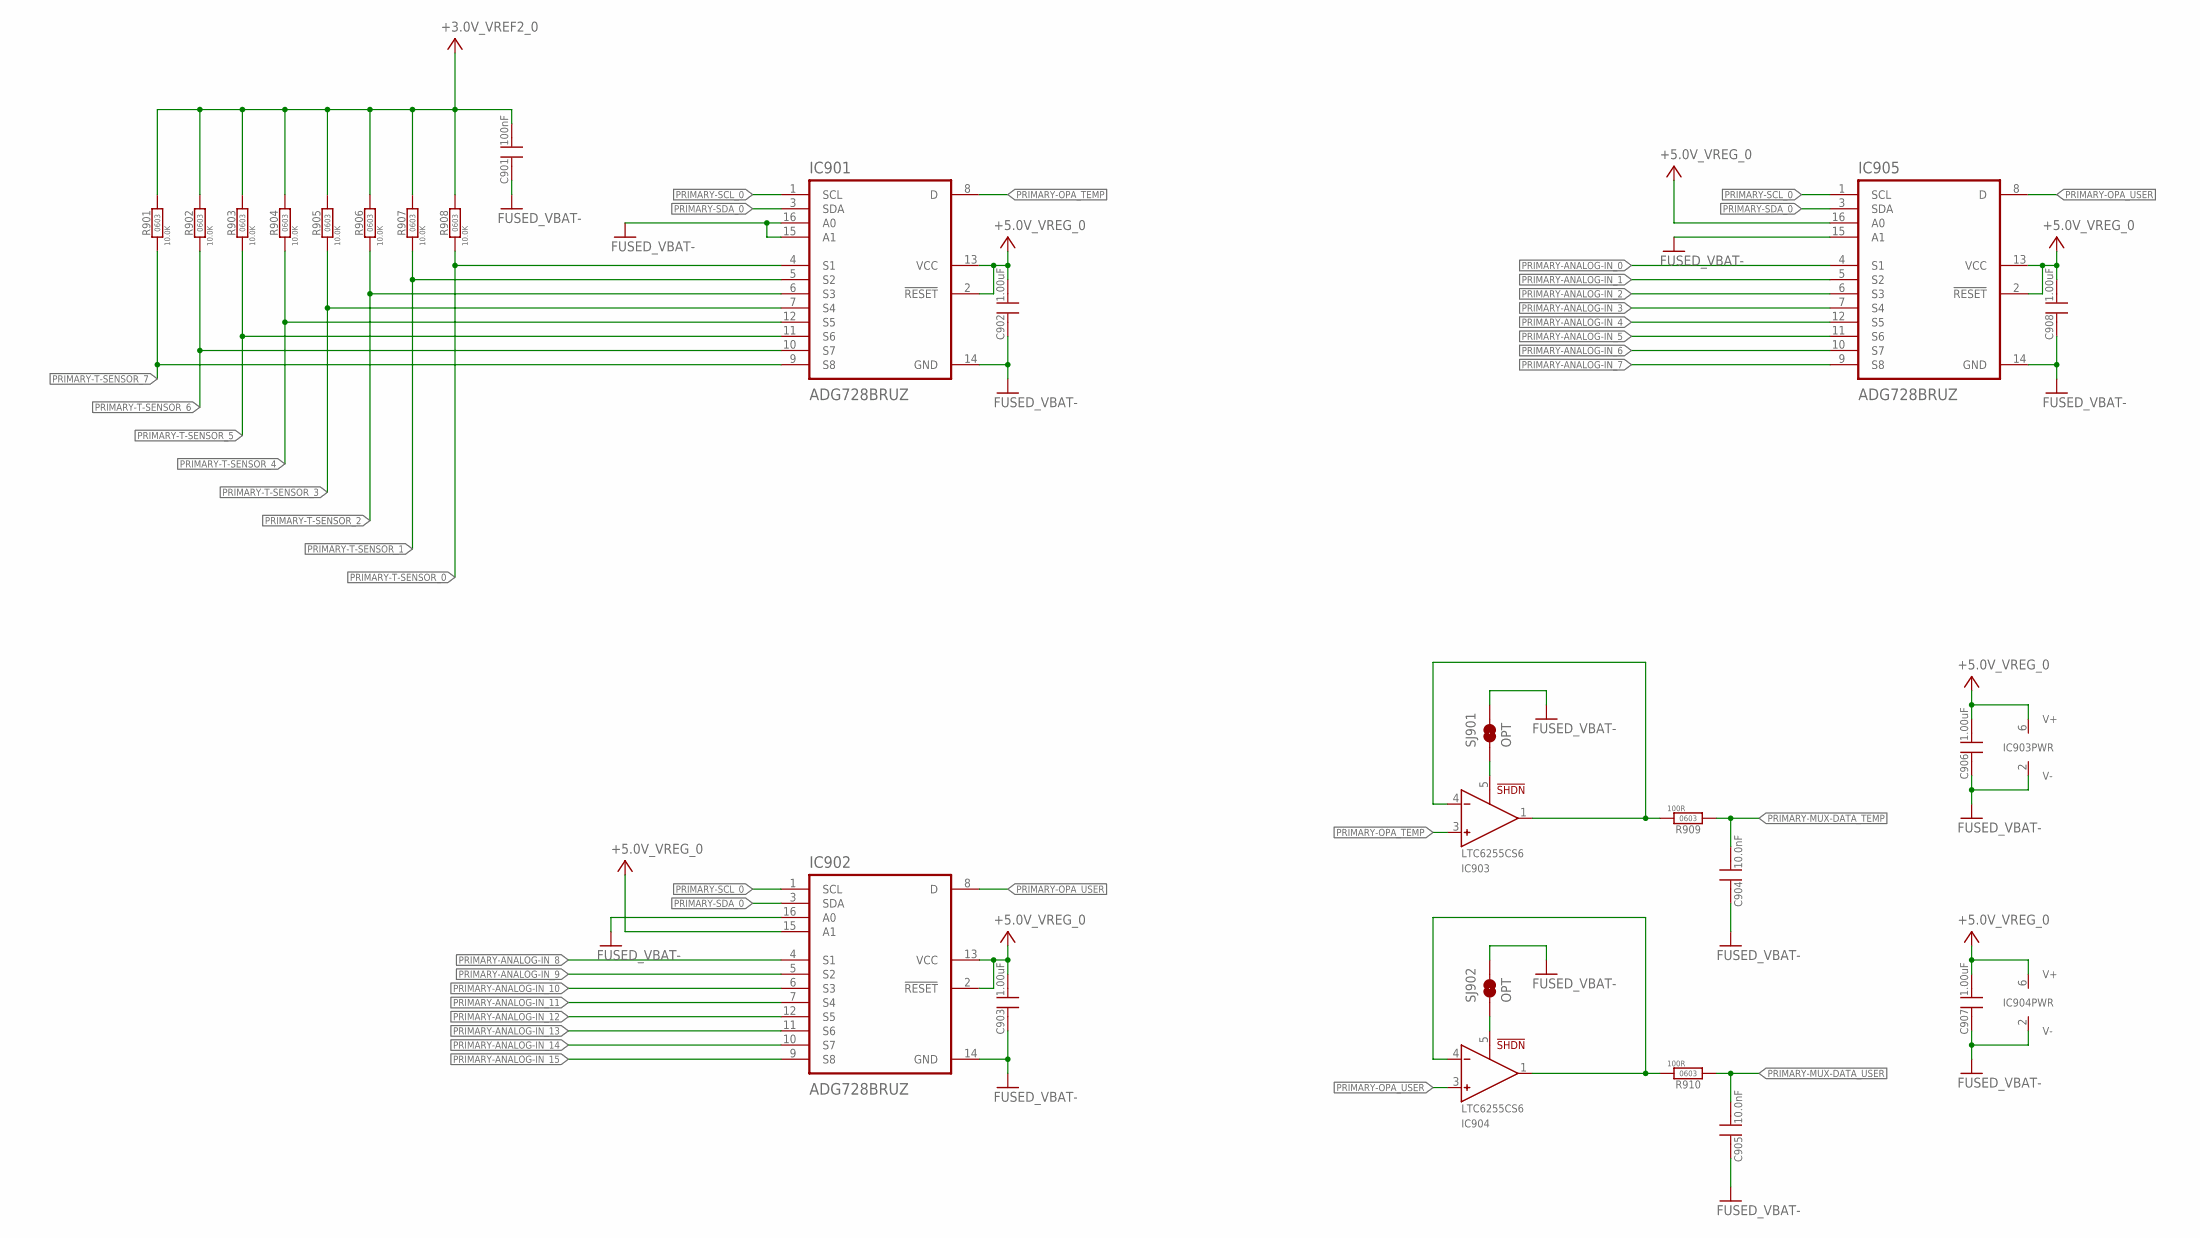
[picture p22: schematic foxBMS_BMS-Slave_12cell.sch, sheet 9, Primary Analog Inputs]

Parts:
C901: 100nF, 20%, 16V; C_SMD_0603_(1608)_R_KEMET_REV01
C902, C903, C906, C907, C908: 1uF, 20%, 16V; C_SMD_0603_(1608)_R_KEMET_REV01
C904, C905: 10nF, 100V, 10%; C_SMD_0603_(1608)_R_KEMET_REV01
IC901, IC902, IC905: ADG728BRUZ; SOP65P638X110-16N
IC903, IC904: LTC6255CS6; IC_SMD_TSOT-23-6_(S6)_R_LINEAR_REV01
R901, R902, R903, R904, R905, R906, R907, R908: 10,0K_0603_R_VISHAY_1%_TK100_REV_01; R_SMD_0603_R_VISHAY_REV01
R909, R910: 100R_0603_R_VISHAY_1%_TK100_REV_01; R_SMD_0603_R_VISHAY_REV01
SJ901, SJ902: OPT; CUSTOM_JUMPER_SJ

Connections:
+3.0V_VREF2_0: C901.2, R901.2, R902.2, R903.2, R904.2, R905.2, R906.2, R907.2, R908.2; also elsewhere on the board
+5.0V_VREG_0: C902.2, C903.2, C906.2, C907.2, C908.2, IC901.2 (!RESET), IC901.13 (VCC), IC902.2 (!RESET), IC902.13 (VCC), IC902.15 (A1), IC903.6 (V+), IC904.6 (V+), IC905.2 (!RESET), IC905.13 (VCC), IC905.16 (A0); also elsewhere on the board
FUSED_VBAT-: C901.1, C902.1, C903.1, C904.1, C905.1, C906.1, C907.1, C908.1, IC901.14 (GND), IC901.15 (A1), IC901.16 (A0), IC902.14 (GND), IC902.16 (A0), IC903.2 (V-), IC904.2 (V-), IC905.14 (GND), IC905.15 (A1), SJ901.2, SJ902.2; also elsewhere on the board
unnamed: IC904.1 (VOUT), IC904.4 (-), R910.1
unnamed: IC904.5 (!SHDN), SJ902.1
unnamed: IC903.1 (VOUT), IC903.4 (-), R909.1
unnamed: IC903.5 (!SHDN), SJ901.1
PRIMARY-ANALOG-IN_0: IC905.4 (S1); also elsewhere on the board
PRIMARY-ANALOG-IN_1: IC905.5 (S2); also elsewhere on the board
PRIMARY-ANALOG-IN_2: IC905.6 (S3); also elsewhere on the board
PRIMARY-ANALOG-IN_3: IC905.7 (S4); also elsewhere on the board
PRIMARY-ANALOG-IN_4: IC905.12 (S5); also elsewhere on the board
PRIMARY-ANALOG-IN_5: IC905.11 (S6); also elsewhere on the board
PRIMARY-ANALOG-IN_6: IC905.10 (S7); also elsewhere on the board
PRIMARY-ANALOG-IN_7: IC905.9 (S8); also elsewhere on the board
PRIMARY-ANALOG-IN_8: IC902.4 (S1); also elsewhere on the board
PRIMARY-ANALOG-IN_9: IC902.5 (S2); also elsewhere on the board
PRIMARY-ANALOG-IN_10: IC902.6 (S3); also elsewhere on the board
PRIMARY-ANALOG-IN_11: IC902.7 (S4); also elsewhere on the board
PRIMARY-ANALOG-IN_12: IC902.12 (S5); also elsewhere on the board
PRIMARY-ANALOG-IN_13: IC902.11 (S6); also elsewhere on the board
PRIMARY-ANALOG-IN_14: IC902.10 (S7); also elsewhere on the board
PRIMARY-ANALOG-IN_15: IC902.9 (S8); also elsewhere on the board
PRIMARY-MUX-DATA_TEMP: C904.2, R909.2; also elsewhere on the board
PRIMARY-MUX-DATA_USER: C905.2, R910.2; also elsewhere on the board
PRIMARY-OPA_TEMP: IC901.8 (D), IC903.3 (+)
PRIMARY-OPA_USER: IC902.8 (D), IC904.3 (+), IC905.8 (D)
PRIMARY-SCL_0: IC901.1 (SCL), IC902.1 (SCL), IC905.1 (SCL); also elsewhere on the board
PRIMARY-SDA_0: IC901.3 (SDA), IC902.3 (SDA), IC905.3 (SDA); also elsewhere on the board
PRIMARY-T-SENSOR_0: IC901.4 (S1), R908.1; also elsewhere on the board
PRIMARY-T-SENSOR_1: IC901.5 (S2), R907.1; also elsewhere on the board
PRIMARY-T-SENSOR_2: IC901.6 (S3), R906.1; also elsewhere on the board
PRIMARY-T-SENSOR_3: IC901.7 (S4), R905.1; also elsewhere on the board
PRIMARY-T-SENSOR_4: IC901.12 (S5), R904.1; also elsewhere on the board
PRIMARY-T-SENSOR_5: IC901.11 (S6), R903.1; also elsewhere on the board
PRIMARY-T-SENSOR_6: IC901.10 (S7), R902.1; also elsewhere on the board
PRIMARY-T-SENSOR_7: IC901.9 (S8), R901.1; also elsewhere on the board

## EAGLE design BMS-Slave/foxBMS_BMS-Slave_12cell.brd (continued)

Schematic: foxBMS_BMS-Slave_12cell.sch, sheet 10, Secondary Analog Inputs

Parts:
C1001: 100nF, 20%, 16V; C_SMD_0603_(1608)_R_KEMET_REV01
C1002, C1003, C1006, C1007, C1008: 1uF, 20%, 16V; C_SMD_0603_(1608)_R_KEMET_REV01
C1004, C1005: 10nF, 100V, 10%; C_SMD_0603_(1608)_R_KEMET_REV01
IC1001, IC1002, IC1005: ADG728BRUZ; SOP65P638X110-16N
IC1003, IC1004: LTC6255CS6; IC_SMD_TSOT-23-6_(S6)_R_LINEAR_REV01
R1001, R1002, R1003, R1004, R1005, R1006, R1007, R1008: 10,0K_0603_R_VISHAY_1%_TK100_REV_01; R_SMD_0603_R_VISHAY_REV01
R1009, R1010: 100R_0603_R_VISHAY_1%_TK100_REV_01; R_SMD_0603_R_VISHAY_REV01
SJ1001, SJ1002: OPT; CUSTOM_JUMPER_SJ

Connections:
+3.0V_VREF2_1: C1001.2, R1001.2, R1002.2, R1003.2, R1004.2, R1005.2, R1006.2, R1007.2, R1008.2; also elsewhere on the board
+5.0V_VREG_1: C1002.2, C1003.2, C1006.2, C1007.2, C1008.2, IC1001.2 (!RESET), IC1001.13 (VCC), IC1002.2 (!RESET), IC1002.13 (VCC), IC1002.15 (A1), IC1003.6 (V+), IC1004.6 (V+), IC1005.2 (!RESET), IC1005.13 (VCC), IC1005.16 (A0); also elsewhere on the board
FUSED_VBAT-: C1001.1, C1002.1, C1003.1, C1004.1, C1005.1, C1006.1, C1007.1, C1008.1, IC1001.14 (GND), IC1001.15 (A1), IC1001.16 (A0), IC1002.14 (GND), IC1002.16 (A0), IC1003.2 (V-), IC1004.2 (V-), IC1005.14 (GND), IC1005.15 (A1), SJ1001.2, SJ1002.2; also elsewhere on the board
unnamed: IC1003.1 (VOUT), IC1003.4 (-), R1009.1
unnamed: IC1003.5 (!SHDN), SJ1001.1
unnamed: IC1004.1 (VOUT), IC1004.4 (-), R1010.1
unnamed: IC1004.5 (!SHDN), SJ1002.1
SECONDARY-ANALOG-IN_0: IC1005.4 (S1); also elsewhere on the board
SECONDARY-ANALOG-IN_1: IC1005.5 (S2); also elsewhere on the board
SECONDARY-ANALOG-IN_2: IC1005.6 (S3); also elsewhere on the board
SECONDARY-ANALOG-IN_3: IC1005.7 (S4); also elsewhere on the board
SECONDARY-ANALOG-IN_4: IC1005.12 (S5); also elsewhere on the board
SECONDARY-ANALOG-IN_5: IC1005.11 (S6); also elsewhere on the board
SECONDARY-ANALOG-IN_6: IC1005.10 (S7); also elsewhere on the board
SECONDARY-ANALOG-IN_7: IC1005.9 (S8); also elsewhere on the board
SECONDARY-ANALOG-IN_8: IC1002.4 (S1); also elsewhere on the board
SECONDARY-ANALOG-IN_9: IC1002.5 (S2); also elsewhere on the board
SECONDARY-ANALOG-IN_10: IC1002.6 (S3); also elsewhere on the board
SECONDARY-ANALOG-IN_11: IC1002.7 (S4); also elsewhere on the board
SECONDARY-ANALOG-IN_12: IC1002.12 (S5); also elsewhere on the board
SECONDARY-ANALOG-IN_13: IC1002.11 (S6); also elsewhere on the board
SECONDARY-ANALOG-IN_14: IC1002.10 (S7); also elsewhere on the board
SECONDARY-ANALOG-IN_15: IC1002.9 (S8); also elsewhere on the board
SECONDARY-MUX-DATA_TEMP: C1004.2, R1009.2; also elsewhere on the board
SECONDARY-MUX-DATA_USER: C1005.2, R1010.2; also elsewhere on the board
SECONDARY-OPA_TEMP: IC1001.8 (D), IC1003.3 (+)
SECONDARY-OPA_USER: IC1002.8 (D), IC1004.3 (+), IC1005.8 (D)
SECONDARY-SCL_1: IC1001.1 (SCL), IC1002.1 (SCL), IC1005.1 (SCL); also elsewhere on the board
SECONDARY-SDA_1: IC1001.3 (SDA), IC1002.3 (SDA), IC1005.3 (SDA); also elsewhere on the board
SECONDARY-T-SENSOR_0: IC1001.4 (S1), R1008.1; also elsewhere on the board
SECONDARY-T-SENSOR_1: IC1001.5 (S2), R1007.1; also elsewhere on the board
SECONDARY-T-SENSOR_2: IC1001.6 (S3), R1006.1; also elsewhere on the board
SECONDARY-T-SENSOR_3: IC1001.7 (S4), R1005.1; also elsewhere on the board
SECONDARY-T-SENSOR_4: IC1001.12 (S5), R1004.1; also elsewhere on the board
SECONDARY-T-SENSOR_5: IC1001.11 (S6), R1003.1; also elsewhere on the board
SECONDARY-T-SENSOR_6: IC1001.10 (S7), R1002.1; also elsewhere on the board
SECONDARY-T-SENSOR_7: IC1001.9 (S8), R1001.1; also elsewhere on the board

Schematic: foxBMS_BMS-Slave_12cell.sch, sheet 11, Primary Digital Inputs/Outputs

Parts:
C1101: 100nF, 20%, 16V; C_SMD_0603_(1608)_R_KEMET_REV01
IC1101: PCA8574TS; SOP65P640X150-20N
R1101, R1102, R1103, R1104, R1105, R1106, R1107, R1108: 10,0K_0603_R_VISHAY_1%_TK100_REV_01; R_SMD_0603_R_VISHAY_REV01

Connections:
+5.0V_VREG_0: C1101.2, IC1101.5 (VDD), R1101.2, R1102.2, R1103.2, R1104.2, R1105.2, R1106.2, R1107.2, R1108.2; also elsewhere on the board
FUSED_VBAT-: C1101.1, IC1101.6 (A0), IC1101.7 (A1), IC1101.9 (A2), IC1101.15 (VSS); also elsewhere on the board
PRIMARY-DIGITAL-IO_0: IC1101.10 (P0), R1101.1; also elsewhere on the board
PRIMARY-DIGITAL-IO_1: IC1101.11 (P1), R1102.1; also elsewhere on the board
PRIMARY-DIGITAL-IO_2: IC1101.12 (P2), R1103.1; also elsewhere on the board
PRIMARY-DIGITAL-IO_3: IC1101.14 (P3), R1104.1; also elsewhere on the board
PRIMARY-DIGITAL-IO_4: IC1101.16 (P4), R1105.1; also elsewhere on the board
PRIMARY-DIGITAL-IO_5: IC1101.17 (P5), R1106.1; also elsewhere on the board
PRIMARY-DIGITAL-IO_6: IC1101.19 (P6), R1107.1; also elsewhere on the board
PRIMARY-DIGITAL-IO_7: IC1101.20 (P7), R1108.1; also elsewhere on the board
PRIMARY-SCL_0: IC1101.2 (SCL); also elsewhere on the board
PRIMARY-SDA_0: IC1101.4 (SDA); also elsewhere on the board

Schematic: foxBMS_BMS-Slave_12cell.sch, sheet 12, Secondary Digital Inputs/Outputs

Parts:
C1201: 100nF, 20%, 16V; C_SMD_0603_(1608)_R_KEMET_REV01
IC1201: PCA8574TS; SOP65P640X150-20N
R1201, R1202, R1203, R1204, R1205, R1206, R1207, R1208: 10,0K_0603_R_VISHAY_1%_TK100_REV_01; R_SMD_0603_R_VISHAY_REV01

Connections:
+5.0V_VREG_1: C1201.2, IC1201.5 (VDD), R1201.2, R1202.2, R1203.2, R1204.2, R1205.2, R1206.2, R1207.2, R1208.2; also elsewhere on the board
FUSED_VBAT-: C1201.1, IC1201.6 (A0), IC1201.7 (A1), IC1201.9 (A2), IC1201.15 (VSS); also elsewhere on the board
SECONDARY-DIGITAL-IO_0: IC1201.10 (P0), R1201.1; also elsewhere on the board
SECONDARY-DIGITAL-IO_1: IC1201.11 (P1), R1202.1; also elsewhere on the board
SECONDARY-DIGITAL-IO_2: IC1201.12 (P2), R1203.1; also elsewhere on the board
SECONDARY-DIGITAL-IO_3: IC1201.14 (P3), R1204.1; also elsewhere on the board
SECONDARY-DIGITAL-IO_4: IC1201.16 (P4), R1205.1; also elsewhere on the board
SECONDARY-DIGITAL-IO_5: IC1201.17 (P5), R1206.1; also elsewhere on the board
SECONDARY-DIGITAL-IO_6: IC1201.19 (P6), R1207.1; also elsewhere on the board
SECONDARY-DIGITAL-IO_7: IC1201.20 (P7), R1208.1; also elsewhere on the board
SECONDARY-SCL_1: IC1201.2 (SCL); also elsewhere on the board
SECONDARY-SDA_1: IC1201.4 (SDA); also elsewhere on the board

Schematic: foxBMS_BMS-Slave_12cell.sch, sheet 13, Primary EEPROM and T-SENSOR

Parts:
C1301, C1302: 100nF, 20%, 16V; C_SMD_0603_(1608)_R_KEMET_REV01
IC1301: M24M02-DR; SOIC127P600X175-8N
IC1302: MCP9800A0T-M/OT; SOT95P280X145-5N
R1301, R1302: 10,0K_0603_R_VISHAY_1%_TK100_REV_01; R_SMD_0603_R_VISHAY_REV01

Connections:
+5.0V_VREG_0: C1301.2, C1302.2, IC1301.8 (VCC), IC1302.1 (VDD), R1301.2, R1302.2; also elsewhere on the board
FUSED_VBAT-: C1301.1, C1302.1, IC1301.3 (E2), IC1301.4 (VSS), IC1302.2 (GND); also elsewhere on the board
unnamed: IC1301.7 (!WC), R1302.1
PRIMARY-SCL_0: IC1301.6 (SCL), IC1302.4 (SCLK); also elsewhere on the board
PRIMARY-SDA_0: IC1301.5 (SDA), IC1302.5 (SDA); also elsewhere on the board
PRIMARY-TEMP-ALERT: IC1302.3 (ALERT), R1301.1; also elsewhere on the board

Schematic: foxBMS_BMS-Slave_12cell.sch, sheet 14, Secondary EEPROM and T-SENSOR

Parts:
C1401, C1402: 100nF, 20%, 16V; C_SMD_0603_(1608)_R_KEMET_REV01
IC1401: M24M02-DR; SOIC127P600X175-8N
IC1402: MCP9800A0T-M/OT; SOT95P280X145-5N
R1401, R1402: 10,0K_0603_R_VISHAY_1%_TK100_REV_01; R_SMD_0603_R_VISHAY_REV01

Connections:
+5.0V_VREG_1: C1401.2, C1402.2, IC1401.8 (VCC), IC1402.1 (VDD), R1401.2, R1402.2; also elsewhere on the board
FUSED_VBAT-: C1401.1, C1402.1, IC1401.3 (E2), IC1401.4 (VSS), IC1402.2 (GND); also elsewhere on the board
unnamed: IC1401.7 (!WC), R1402.1
SECONDARY-SCL_1: IC1401.6 (SCL), IC1402.4 (SCLK); also elsewhere on the board
SECONDARY-SDA_1: IC1401.5 (SDA), IC1402.5 (SDA); also elsewhere on the board
SECONDARY-TEMP-ALERT: IC1402.3 (ALERT), R1401.1; also elsewhere on the board

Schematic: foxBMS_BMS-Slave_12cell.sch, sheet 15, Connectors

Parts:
C1501, C1502, C1503, C1504, C1505, C1506, C1507, C1508: 100nF, 20%, 16V; C_SMD_0603_(1608)_R_KEMET_REV01
X1501, X1502: MA09-2
X1503: 43045-2400_MOLEX_24PIN; X_TH_MOLEX_43045-2400_R_REV01
X1504, X1505: MA05-2
X1506, X1507: 43045-1600_MOLEX_16PIN; X_TH_MOLEX_43045-1600_R_REV01
X1508: MA10-2
X1509, X1510, X1511, X1512, X1513, X1514: 43045-0200_MOLEX_2PIN; X_TH_MOLEX_43045-0200_R_REV01
X1515: MA02-2_TH; MA02-2

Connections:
+3.0V_VREF2_0: C1501.2, C1506.2, X1501.17, X1508.1; also elsewhere on the board
+3.0V_VREF2_1: C1502.2, C1507.2, X1502.17, X1508.2; also elsewhere on the board
+5.0V_VREG_0: C1503.2, C1505.2, X1504.9, X1508.3; also elsewhere on the board
+5.0V_VREG_1: C1504.2, C1508.2, X1505.9, X1508.4; also elsewhere on the board
CELL_0+: X1503.2; also elsewhere on the board
CELL_0-: X1503.13; also elsewhere on the board
CELL_1+: X1503.14; also elsewhere on the board
CELL_2+: X1503.3; also elsewhere on the board
CELL_3+: X1503.15; also elsewhere on the board
CELL_4+: X1503.4; also elsewhere on the board
CELL_5+: X1503.16; also elsewhere on the board
CELL_6+: X1503.5; also elsewhere on the board
CELL_7+: X1503.17; also elsewhere on the board
CELL_8+: X1503.6; also elsewhere on the board
CELL_9+: X1503.18; also elsewhere on the board
CELL_10+: X1503.7; also elsewhere on the board
CELL_11+: X1503.19; also elsewhere on the board
EXT_DC_IN+: X1513.1, X1514.1, X1515.1, X1515.3; also elsewhere on the board
EXT_DC_IN-: X1513.2, X1514.2, X1515.2, X1515.4; also elsewhere on the board
FUSED_VBAT-: C1501.1, C1502.1, C1503.1, C1504.1, C1505.1, C1506.1, C1507.1, C1508.1, X1501.18, X1502.18, X1504.10, X1505.10, X1506.9, X1506.10, X1506.11, X1506.12, X1506.13, X1506.14, X1506.15, X1506.16, X1507.9, X1507.10, X1507.11, X1507.12, X1507.13, X1507.14, X1507.15, X1507.16, X1508.19, X1508.20; also elsewhere on the board
PRIMARY-ANALOG-IN_0: X1501.1; also elsewhere on the board
PRIMARY-ANALOG-IN_1: X1501.2; also elsewhere on the board
PRIMARY-ANALOG-IN_2: X1501.3; also elsewhere on the board
PRIMARY-ANALOG-IN_3: X1501.4; also elsewhere on the board
PRIMARY-ANALOG-IN_4: X1501.5; also elsewhere on the board
PRIMARY-ANALOG-IN_5: X1501.6; also elsewhere on the board
PRIMARY-ANALOG-IN_6: X1501.7; also elsewhere on the board
PRIMARY-ANALOG-IN_7: X1501.8; also elsewhere on the board
PRIMARY-ANALOG-IN_8: X1501.9; also elsewhere on the board
PRIMARY-ANALOG-IN_9: X1501.10; also elsewhere on the board
PRIMARY-ANALOG-IN_10: X1501.11; also elsewhere on the board
PRIMARY-ANALOG-IN_11: X1501.12; also elsewhere on the board
PRIMARY-ANALOG-IN_12: X1501.13; also elsewhere on the board
PRIMARY-ANALOG-IN_13: X1501.14; also elsewhere on the board
PRIMARY-ANALOG-IN_14: X1501.15; also elsewhere on the board
PRIMARY-ANALOG-IN_15: X1501.16; also elsewhere on the board
PRIMARY-DIGITAL-IO_0: X1504.1; also elsewhere on the board
PRIMARY-DIGITAL-IO_1: X1504.2; also elsewhere on the board
PRIMARY-DIGITAL-IO_2: X1504.3; also elsewhere on the board
PRIMARY-DIGITAL-IO_3: X1504.4; also elsewhere on the board
PRIMARY-DIGITAL-IO_4: X1504.5; also elsewhere on the board
PRIMARY-DIGITAL-IO_5: X1504.6; also elsewhere on the board
PRIMARY-DIGITAL-IO_6: X1504.7; also elsewhere on the board
PRIMARY-DIGITAL-IO_7: X1504.8; also elsewhere on the board
PRIMARY-GPIO1-OPT: X1508.5; also elsewhere on the board
PRIMARY-GPIO2-OPT: X1508.7; also elsewhere on the board
PRIMARY-GPIO3-OPT: X1508.9; also elsewhere on the board
PRIMARY-GPIO4-OPT: X1508.11; also elsewhere on the board
PRIMARY-GPIO5-OPT: X1508.13; also elsewhere on the board
PRIMARY-IN+: X1509.1; also elsewhere on the board
PRIMARY-IN-: X1509.2; also elsewhere on the board
PRIMARY-OUT+: X1510.1; also elsewhere on the board
PRIMARY-OUT-: X1510.2; also elsewhere on the board
PRIMARY-T-SENSOR_0: X1506.1; also elsewhere on the board
PRIMARY-T-SENSOR_1: X1506.2; also elsewhere on the board
PRIMARY-T-SENSOR_2: X1506.3; also elsewhere on the board
PRIMARY-T-SENSOR_3: X1506.4; also elsewhere on the board
PRIMARY-T-SENSOR_4: X1506.5; also elsewhere on the board
PRIMARY-T-SENSOR_5: X1506.6; also elsewhere on the board
PRIMARY-T-SENSOR_6: X1506.7; also elsewhere on the board
PRIMARY-T-SENSOR_7: X1506.8; also elsewhere on the board
PRIMARY-TEMP-ALERT: X1508.17; also elsewhere on the board
PRIMARY-WDT: X1508.15; also elsewhere on the board
SECONDARY-ANALOG-IN_0: X1502.1; also elsewhere on the board
SECONDARY-ANALOG-IN_1: X1502.2; also elsewhere on the board
SECONDARY-ANALOG-IN_2: X1502.3; also elsewhere on the board
SECONDARY-ANALOG-IN_3: X1502.4; also elsewhere on the board
SECONDARY-ANALOG-IN_4: X1502.5; also elsewhere on the board
SECONDARY-ANALOG-IN_5: X1502.6; also elsewhere on the board
SECONDARY-ANALOG-IN_6: X1502.7; also elsewhere on the board
SECONDARY-ANALOG-IN_7: X1502.8; also elsewhere on the board
SECONDARY-ANALOG-IN_8: X1502.9; also elsewhere on the board
SECONDARY-ANALOG-IN_9: X1502.10; also elsewhere on the board
SECONDARY-ANALOG-IN_10: X1502.11; also elsewhere on the board
SECONDARY-ANALOG-IN_11: X1502.12; also elsewhere on the board
SECONDARY-ANALOG-IN_12: X1502.13; also elsewhere on the board
SECONDARY-ANALOG-IN_13: X1502.14; also elsewhere on the board
SECONDARY-ANALOG-IN_14: X1502.15; also elsewhere on the board
SECONDARY-ANALOG-IN_15: X1502.16; also elsewhere on the board
SECONDARY-DIGITAL-IO_0: X1505.1; also elsewhere on the board
SECONDARY-DIGITAL-IO_1: X1505.2; also elsewhere on the board
SECONDARY-DIGITAL-IO_2: X1505.3; also elsewhere on the board
SECONDARY-DIGITAL-IO_3: X1505.4; also elsewhere on the board
SECONDARY-DIGITAL-IO_4: X1505.5; also elsewhere on the board
SECONDARY-DIGITAL-IO_5: X1505.6; also elsewhere on the board
SECONDARY-DIGITAL-IO_6: X1505.7; also elsewhere on the board
SECONDARY-DIGITAL-IO_7: X1505.8; also elsewhere on the board
SECONDARY-GPIO1-OPT: X1508.6; also elsewhere on the board
SECONDARY-GPIO2-OPT: X1508.8; also elsewhere on the board
SECONDARY-GPIO3-OPT: X1508.10; also elsewhere on the board
SECONDARY-GPIO4-OPT: X1508.12; also elsewhere on the board
SECONDARY-GPIO5-OPT: X1508.14; also elsewhere on the board
SECONDARY-IN+: X1511.1; also elsewhere on the board
SECONDARY-IN-: X1511.2; also elsewhere on the board
SECONDARY-OUT+: X1512.1; also elsewhere on the board
SECONDARY-OUT-: X1512.2; also elsewhere on the board
SECONDARY-T-SENSOR_0: X1507.1; also elsewhere on the board
SECONDARY-T-SENSOR_1: X1507.2; also elsewhere on the board
SECONDARY-T-SENSOR_2: X1507.3; also elsewhere on the board
SECONDARY-T-SENSOR_3: X1507.4; also elsewhere on the board
SECONDARY-T-SENSOR_4: X1507.5; also elsewhere on the board
SECONDARY-T-SENSOR_5: X1507.6; also elsewhere on the board
SECONDARY-T-SENSOR_6: X1507.7; also elsewhere on the board
SECONDARY-T-SENSOR_7: X1507.8; also elsewhere on the board
SECONDARY-TEMP-ALERT: X1508.18; also elsewhere on the board
SECONDARY-WDT: X1508.16; also elsewhere on the board
VBAT+: X1503.8; also elsewhere on the board
VBAT-: X1503.1; also elsewhere on the board

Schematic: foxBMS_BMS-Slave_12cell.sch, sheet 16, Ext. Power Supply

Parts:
C1601: 1,00µF_0805_25V_X7R_KEMET; C_SMD_0805_(2012)_R_KEMET_REV01
C1602, C1603: 10µF_1210_25V_X7R; 1210
C1604: 100nF, 20%, 16V; C_SMD_0603_(1608)_R_KEMET_REV01
C1605: 1uF, 20%, 16V; C_SMD_0603_(1608)_R_KEMET_REV01
C1606: 470PF_0805_50V_X7R_KEMET; C_SMD_0805_(2012)_R_KEMET_REV01
C1607: 4,7NF_1812; 1812
C1608, C1609, C1610: 4,70µF_1206_25V_X7R_KEMET; C_SMD_1206_(3216)_R_KEMET_REV01
D1601, D1603: DI_DFLS1100; POWER_DI_123
D1602: DI_DFLZ36; POWER_DI_123
D1604: DI_PDS3200; POWER_DI_5
D1605: MMSZ5263B; SOD123
F1601: 1,250A_LITTELFUSE_466_1206; R_SMD_CHIP_1206_R_LITTLEFUSE_REV_01
IC1601: LT8302; S8E
L1601: WE-74404042100; WE-LQS
R1601: 390K_0603_R_VISHAY_1%_TK100_REV_01; R_SMD_0603_R_VISHAY_REV01
R1602: 86,6K_0603_R_VISHAY_1%_TK100_REV_01; R_SMD_0603_R_VISHAY_REV01
R1603: 39,0R_0805_R_VISHAY_1%_TK100_REV_01; R_SMD_0805_R_VISHAY_REV01
R1604: DUMMY_R_CHIP_0603_R_VISHAY; R_SMD_0603_R_VISHAY_REV01
R1605: 127K_0603_R_VISHAY_1%_TK100_REV_01; R_SMD_0603_R_VISHAY_REV01
R1606: 10,0K_0603_R_VISHAY_1%_TK100_REV_01; R_SMD_0603_R_VISHAY_REV01
TP1601, TP1602, TP1603: CUSTOM_PAD_PAD_2.0X1.5MM; CUSTOM_PAD_PAD2.0X1.5MM
TR1601: WE_750313457; WUERTH_CUSTOM
X1601: MA02-1_TH; MA02-1A

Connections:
EXT_DC_IN+: F1601.P$1; also elsewhere on the board
EXT_DC_IN-: C1601.P$1, C1602.P$1, C1603.P$1, C1604.1, C1605.1, C1607.P$1, IC1601.4 (GND), IC1601.P$1 (GND), R1602.1, R1606.1, TP1601.P$1; also elsewhere on the board
EXT_DC_ISO+: C1608.P$2, C1609.P$2, C1610.P$2, D1604.K (C), D1605.C (K), X1601.1; also elsewhere on the board
FUSED_VBAT-: C1607.P$2, C1608.P$1, C1609.P$1, C1610.P$1, D1605.A, TP1603.P$1, TR1601.8 (PIN8), X1601.2; also elsewhere on the board
unnamed: C1604.2, IC1601.1 (EN/UVLO), R1601.1, R1602.2
unnamed: C1605.2, IC1601.2 (INTVCC)
unnamed: TR1601.6 (PIN6), TR1601.7 (PIN7)
unnamed: IC1601.7 (R_REF), R1604.2, R1606.2
unnamed: IC1601.6 (R_FB), R1605.1
unnamed: D1603.A, IC1601.5 (SW), R1603.1, R1605.2, TR1601.1 (PIN2), TR1601.2 (PIN2)
unnamed: IC1601.8 (TC), R1604.1
unnamed: D1604.A1 (A), D1604.A2 (A), TR1601.5 (PIN5)
unnamed: C1606.P$1, R1603.2
unnamed: D1601.A, F1601.P$2
unnamed: C1601.P$2, D1601.K (C), L1601.1, TP1602.P$1
unnamed: D1602.K (C), D1603.K (C)
unnamed: C1602.P$2, C1603.P$2, C1606.P$2, D1602.A, IC1601.3 (V_IN), L1601.2, R1601.2, TR1601.3 (PIN4), TR1601.4 (PIN4)

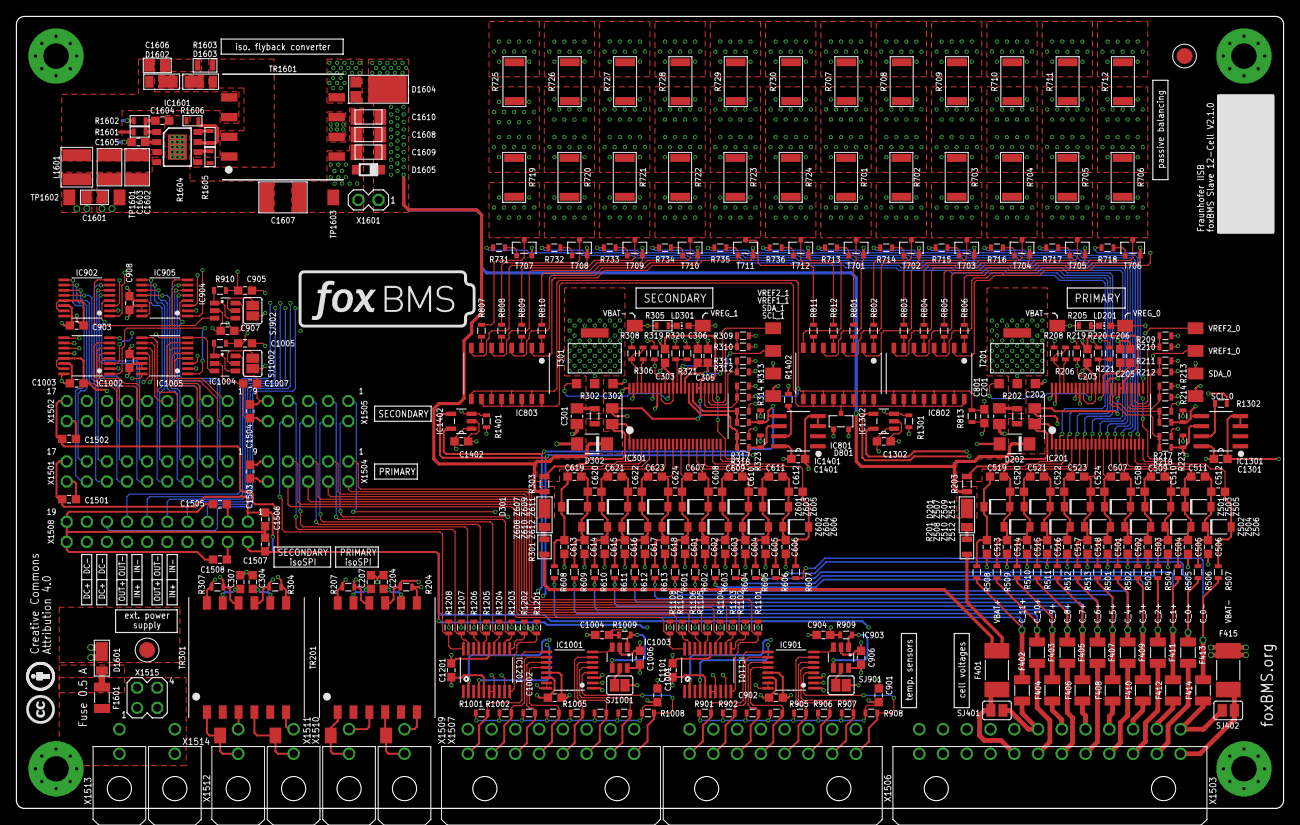
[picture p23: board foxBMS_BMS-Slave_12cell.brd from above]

Board: 6 copper layers, 160.0 x 100.0 mm, 405 parts (0 on the bottom side), 274 nets.

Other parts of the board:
U$55, U$56: FIDUCIAL_1MM

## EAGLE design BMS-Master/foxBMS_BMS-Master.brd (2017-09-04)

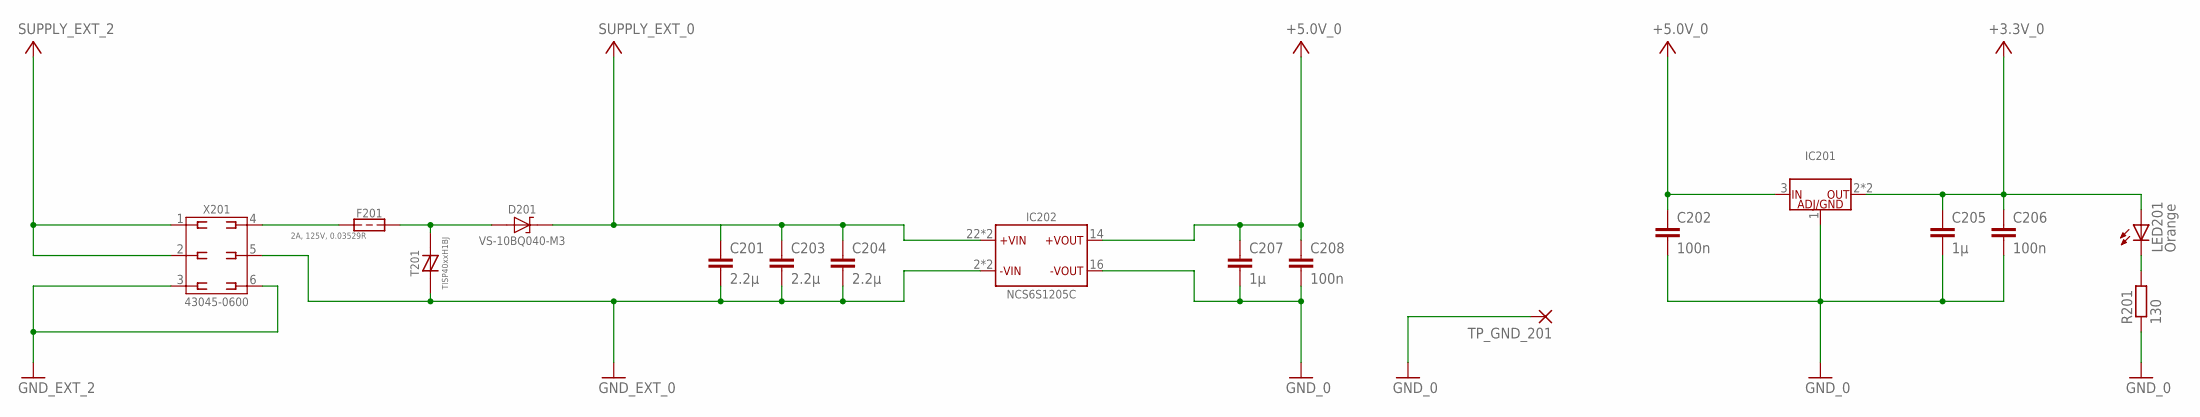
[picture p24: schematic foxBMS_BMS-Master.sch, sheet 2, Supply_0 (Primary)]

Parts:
C201, C203, C204: 2.2µ; C0805
C202, C206, C208: 100n; C0603
C205, C207: 1µ; C0603
D201: VS-10BQ040-M3; D_SMD_SMB_(DO-214AA)_R_VISHAY_REV01
F201: 0,500A_LITTELFUSE_4482A; 448_SERIES_LITTELFUSE
IC201: LM1085IS-5.0/NOPB; IC_SMD_TO-263-3_(KTT0003B)_R_TI_REV01
IC202: MURATA_NCS6S1205C; IC_TH_32,00MMX20,00MMX10,00MM_(7-PIN)_R_MURATA_REV01
LED201: Orange; CHIP-LED0603
R201: 130; R0603
T201: TISP40XXH1BJ; TVS_THYRISTOR
TP_GND_201: 1,6/0,8
X201: 43045-0600_MOLEX_6PIN; X_TH_MOLEX_43045-0600_R_REV01

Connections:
+3.3V_0: C205.1, C206.1, IC201.2 (OUT), IC201.4 (OUT), LED201.A; also elsewhere on the board
+5.0V_0: C202.1, C207.1, C208.1, IC201.3 (IN), IC202.14 (+VOUT); also elsewhere on the board
GND_0: C202.2, C205.2, C206.2, C207.2, C208.2, IC201.1 (ADJ/GND), IC202.16 (-VOUT), R201.1, TP_GND_201.1; also elsewhere on the board
GND_EXT_0: C201.2, C203.2, C204.2, IC202.2 (-VIN), IC202.3 (-VIN), T201.C (T), X201.5; also elsewhere on the board
GND_EXT_2: X201.3, X201.6; also elsewhere on the board
unnamed: LED201.C, R201.2
unnamed: D201.A, F201.P$2, T201.A (R)
unnamed: F201.P$1, X201.4
SUPPLY_EXT_0: C201.1, C203.1, C204.1, D201.C, IC202.22 (+VIN), IC202.23 (+VIN); also elsewhere on the board
SUPPLY_EXT_2: X201.1, X201.2; also elsewhere on the board


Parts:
C301, C306, C308: 100n; C0603
C302, C303, C304: 2.2µ; C0805
C305, C307: 1µ; C0603
IC301: LM1085IS-5.0/NOPB; IC_SMD_TO-263-3_(KTT0003B)_R_TI_REV01
IC302: RS-2405D/H2; IC_TH_SIP8_R_RECOM_REV01
LED301: Orange; CHIP-LED0603
R301: 130; R0603
TP_GND_301: 1,6/0,8

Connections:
+3.3V_1: C305.1, C306.1, IC301.2 (OUT), IC301.4 (OUT), LED301.A; also elsewhere on the board
+5.0V_1: C301.1, C307.1, C308.1, IC301.3 (IN), IC302.6 (+VOUT); also elsewhere on the board
GND_1: C301.2, C305.2, C306.2, C307.2, C308.2, IC301.1 (ADJ/GND), IC302.7 (COM), R301.2, TP_GND_301.1; also elsewhere on the board
GND_EXT_0: C302.2, C303.2, C304.2, IC302.1 (-VIN); also elsewhere on the board
unnamed: LED301.C, R301.1
SUPPLY_EXT_0: C302.1, C303.1, C304.1, IC302.2 (+VIN); also elsewhere on the board

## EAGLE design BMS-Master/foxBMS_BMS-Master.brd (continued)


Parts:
BATT: SMTU1225-LF; X_SMD_(23,70MM_X_12,70MM_X_5,00MM)_R_RENATA_REV01
C401, C404, C405, C406, C407, C408, C409, C410, C411, C412, C413, C415, C416, C417, C418, C419, C420, C421, C422, C424, C425, C430: 100n; C0603
C402, C414, C428, C429: 18p; C0603
C403, C423: 1µ; C0603
C426, C427: 2.2µ; C0603
IC401: ADR3425ARJZ; IC_SMD_SOT23-6_(MO-178-AB)_R_AD_REV01
IC402: STM32F429IIT6; IC_SMD_LQFP176_R_ST_REV01
L401: L0805; 0805
LED401: Red; CHIP-LED0603
LED402: Green; CHIP-LED0603
Q401: 7B-8.000MAAJ-T; G_SMD_5,00MM_X_3,20MM_0,90MM_(7B)_TXC_REV01
Q402: MS3V; MS3V-T1R
R401, R402, R405, R407: 10k; R0603
R403, R406: 0; R0603
R404: 680; R0603
R408, R409: 130; R0603
S401: KMR211GLFS; S_SMD_4,60MMX2,80MMX1,90MM_R_CK-COMPONENTS_REV01
T401: BSS84P; V_SMD_SOT23_(TO-236AB)_R_INFINEON_REV01
X401: MA03-1
X402: MA02-1
X403: SAMTEC_FTS_20POL_HEADER_VERTIKAL_REV01; X_SMD_FTS_110-03_(20POL)_R_SAMTEC_REV01

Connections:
+3.3V_0: C401.1, C403.1, C404.1, C405.1, C406.1, C407.1, C408.1, C409.1, C410.1, C412.1, C413.1, C415.1, C416.1, C417.1, C418.1, C419.1, C420.1, C421.1, C430.1, IC401.3 (ENABLE), IC401.4 (VIN), IC402.15 (VDD1), IC402.23 (VDD2), IC402.36 (VDD3), IC402.49 (VDD4), IC402.62 (VDD5), IC402.72 (VDD6), IC402.82 (VDD7), IC402.91 (VDD8), IC402.103 (VDD9), IC402.114 (VDD10), IC402.127 (VDD11), IC402.136 (VDD12), IC402.149 (VDD13), IC402.159 (VDD14), IC402.171 (PDR_ON), IC402.172 (VDD15), L401.1, R402.2, R405.2, T401.2 (S), X402.1, X403.1; also elsewhere on the board
ADC_MCU_0_CH_0: IC402.54 (P4); also elsewhere on the board
ADC_MCU_0_CH_1: IC402.55 (P5); also elsewhere on the board
ADC_MCU_0_CH_2: IC402.56 (P0); also elsewhere on the board
ADC_MCU_0_CH_3: IC402.57 (P1); also elsewhere on the board
ADC_MCU_0_CH_4: IC402.41 (P1); also elsewhere on the board
BENDER_OK: IC402.46 (P5); also elsewhere on the board
BENDER_PWM: IC402.47 (P3); also elsewhere on the board
BENDER_SUPPLY_ENABLE: IC402.43 (P2); also elsewhere on the board
BMS-INTERFACE_0_GPIO_0: IC402.121 (P10); also elsewhere on the board
BMS-INTERFACE_0_GPIO_1: IC402.122 (P11); also elsewhere on the board
BMS-INTERFACE_0_GPIO_2: IC402.123 (P12); also elsewhere on the board
BMS-INTERFACE_0_GPIO_3: IC402.162 (P4); also elsewhere on the board
BMS-INTERFACE_0_SPI_CS: IC402.50 (P4); also elsewhere on the board
BMS-INTERFACE_0_SPI_MISO: IC402.52 (P6); also elsewhere on the board
BMS-INTERFACE_0_SPI_MOSI: IC402.53 (P7); also elsewhere on the board
BMS-INTERFACE_0_SPI_SCK: IC402.51 (P5); also elsewhere on the board
BOOT_0_MCU_0: IC402.166 (BOOT0), R401.2, T401.3 (D), X402.2
CAN_0_RX: IC402.163 (P5); also elsewhere on the board
CAN_0_TRANS_STANDBY_CONTROL: IC402.141 (P12); also elsewhere on the board
CAN_0_TX: IC402.93 (P13); also elsewhere on the board
CAN_1_RX: IC402.167 (P8); also elsewhere on the board
CAN_1_TRANS_STANDBY_CONTROL: IC402.165 (P7); also elsewhere on the board
CAN_1_TX: IC402.168 (P9); also elsewhere on the board
CONTACTOR_0_CONTROL: IC402.133 (P2); also elsewhere on the board
CONTACTOR_0_FEEDBACK: IC402.128 (P13); also elsewhere on the board
CONTACTOR_1_CONTROL: IC402.132 (P1); also elsewhere on the board
CONTACTOR_1_FEEDBACK: IC402.129 (P14); also elsewhere on the board
CONTACTOR_2_CONTROL: IC402.131 (P0); also elsewhere on the board
CONTACTOR_2_FEEDBACK: IC402.130 (P15); also elsewhere on the board
CONTACTOR_3_CONTROL: IC402.120 (P9); also elsewhere on the board
CONTACTOR_3_FEEDBACK: IC402.115 (P6); also elsewhere on the board
CONTACTOR_4_CONTROL: IC402.119 (P8); also elsewhere on the board
CONTACTOR_4_FEEDBACK: IC402.116 (P7); also elsewhere on the board
CONTACTOR_5_CONTROL: IC402.118 (P9); also elsewhere on the board
CONTACTOR_5_FEEDBACK: IC402.117 (P8); also elsewhere on the board
CONTACTOR_6_CONTROL: IC402.139 (P10); also elsewhere on the board
CONTACTOR_6_FEEDBACK: IC402.140 (P11); also elsewhere on the board
CONTACTOR_7_CONTROL: IC402.144 (P2); also elsewhere on the board
CONTACTOR_7_FEEDBACK: IC402.164 (P6); also elsewhere on the board
CONTACTOR_8_CONTROL: IC402.44 (P3); also elsewhere on the board
CONTACTOR_8_FEEDBACK: IC402.45 (P4); also elsewhere on the board
DATA_STORAGE_SPI_EEPROM_CS: IC402.7 (P8); also elsewhere on the board
DATA_STORAGE_SPI_MISO: IC402.155 (P12); also elsewhere on the board
DATA_STORAGE_SPI_MOSI: IC402.157 (P14); also elsewhere on the board
DATA_STORAGE_SPI_SCK: IC402.156 (P13); also elsewhere on the board
DATA_STORAGE_SPI_SDCARD_NSS: IC402.11 (P9); also elsewhere on the board
DEBUG_LED_0_MCU_0: IC402.35 (P3), LED402.A
DEBUG_LED_1_MCU_0: IC402.34 (P2), LED401.A
FMC_MCU_0_RAM_A0: IC402.16 (P0); also elsewhere on the board
FMC_MCU_0_RAM_A1: IC402.17 (P1); also elsewhere on the board
FMC_MCU_0_RAM_A2: IC402.18 (P2); also elsewhere on the board
FMC_MCU_0_RAM_A3: IC402.19 (P3); also elsewhere on the board
FMC_MCU_0_RAM_A4: IC402.20 (P4); also elsewhere on the board
FMC_MCU_0_RAM_A5: IC402.21 (P5); also elsewhere on the board
FMC_MCU_0_RAM_A6: IC402.60 (P12); also elsewhere on the board
FMC_MCU_0_RAM_A7: IC402.63 (P13); also elsewhere on the board
FMC_MCU_0_RAM_A8: IC402.64 (P14); also elsewhere on the board
FMC_MCU_0_RAM_A9: IC402.65 (P15); also elsewhere on the board
FMC_MCU_0_RAM_A10: IC402.66 (P0); also elsewhere on the board
FMC_MCU_0_RAM_A11: IC402.67 (P1); also elsewhere on the board
FMC_MCU_0_RAM_BA0: IC402.108 (P4); also elsewhere on the board
FMC_MCU_0_RAM_BA1: IC402.109 (P5); also elsewhere on the board
FMC_MCU_0_RAM_D0: IC402.104 (P14); also elsewhere on the board
FMC_MCU_0_RAM_D1: IC402.105 (P15); also elsewhere on the board
FMC_MCU_0_RAM_D2: IC402.142 (P0); also elsewhere on the board
FMC_MCU_0_RAM_D3: IC402.143 (P1); also elsewhere on the board
FMC_MCU_0_RAM_D4: IC402.68 (P7); also elsewhere on the board
FMC_MCU_0_RAM_D5: IC402.69 (P8); also elsewhere on the board
FMC_MCU_0_RAM_D6: IC402.70 (P9); also elsewhere on the board
FMC_MCU_0_RAM_D7: IC402.73 (P10); also elsewhere on the board
FMC_MCU_0_RAM_D8: IC402.74 (P11); also elsewhere on the board
FMC_MCU_0_RAM_D9: IC402.75 (P12); also elsewhere on the board
FMC_MCU_0_RAM_D10: IC402.76 (P13); also elsewhere on the board
FMC_MCU_0_RAM_D11: IC402.77 (P14); also elsewhere on the board
FMC_MCU_0_RAM_D12: IC402.78 (P15); also elsewhere on the board
FMC_MCU_0_RAM_D13: IC402.96 (P8); also elsewhere on the board
FMC_MCU_0_RAM_D14: IC402.97 (P9); also elsewhere on the board
FMC_MCU_0_RAM_D15: IC402.98 (P10); also elsewhere on the board
FMC_MCU_0_RAM_NBL0: IC402.169 (P0); also elsewhere on the board
FMC_MCU_0_RAM_NBL1: IC402.170 (P1); also elsewhere on the board
FMC_MCU_0_RAM_SDCKE1: IC402.84 (P7); also elsewhere on the board
FMC_MCU_0_RAM_SDCLK: IC402.112 (P8); also elsewhere on the board
FMC_MCU_0_RAM_SDNCAS: IC402.160 (P15); also elsewhere on the board
FMC_MCU_0_RAM_SDNE1: IC402.83 (P6); also elsewhere on the board
FMC_MCU_0_RAM_SDNRAS: IC402.59 (P11); also elsewhere on the board
FMC_MCU_0_RAM_SDNWE: IC402.32 (P0); also elsewhere on the board
FTDI_MCU_0_DTR: R402.1, T401.1 (G); also elsewhere on the board
FTDI_MCU_0_RTS: R403.2; also elsewhere on the board
FTDI_MCU_0_RX: IC402.80 (P11); also elsewhere on the board
FTDI_MCU_0_TX: IC402.79 (P10); also elsewhere on the board
GND_0: BATT.-, C401.2, C402.1, C403.2, C404.2, C405.2, C406.2, C407.2, C408.2, C409.2, C410.2, C411.2, C412.2, C413.2, C414.2, C415.2, C416.2, C417.2, C418.2, C419.2, C420.2, C421.2, C422.2, C423.2, C424.2, C425.2, C426.2, C427.2, C428.1, C429.2, C430.2, IC401.1 (GND_FORCE), IC401.2 (GND_SENSE), IC402.14 (VSS1), IC402.22 (VSS2), IC402.37 (VSSA), IC402.48 (BYPASS_REG), IC402.61 (VSS3), IC402.71 (VSS4), IC402.90 (VSS5), IC402.102 (VSS6), IC402.113 (VSS7), IC402.126 (VSS8), IC402.135 (VSS9), IC402.148 (VSS10), IC402.158 (VSS11), Q401.2 (GND), Q401.4 (GND), Q402.P$3 (2), R401.1, R406.1, R407.1, R408.1, R409.1, X401.1, X403.3, X403.5, X403.9, X403.11, X403.13, X403.15, X403.17, X403.19; also elsewhere on the board
HSE_1_MCU_0: C402.2, IC402.29 (P0), Q401.1 (A)
HSE_2_MCU_0: C414.1, IC402.30 (P1), Q401.3 (B)
INTERLOCK_CONTROL_MCU_0: IC402.146 (P4); also elsewhere on the board
INTERLOCK_FEEDBACK_MCU_0: IC402.147 (P5); also elsewhere on the board
ISONOC_0_CONTROL: IC402.85 (P8); also elsewhere on the board
ISONOC_1_CONTROL: IC402.86 (P9); also elsewhere on the board
ISONOC_2_CONTROL: IC402.87 (P10); also elsewhere on the board
ISONOC_3_CONTROL: IC402.88 (P11); also elsewhere on the board
ISONOC_4_CONTROL: IC402.89 (P12); also elsewhere on the board
ISONOC_5_CONTROL: IC402.99 (P11); also elsewhere on the board
ISO_GPIO_MCU_0_IN_0: IC402.100 (P12); also elsewhere on the board
ISO_GPIO_MCU_0_IN_1: IC402.101 (P13); also elsewhere on the board
ISO_GPIO_MCU_0_IN_2: IC402.154 (P11); also elsewhere on the board
ISO_GPIO_MCU_0_IN_3: IC402.173 (P4); also elsewhere on the board
ISO_GPIO_MCU_0_OUT_0: IC402.152 (P9); also elsewhere on the board
ISO_GPIO_MCU_0_OUT_1: IC402.153 (P10); also elsewhere on the board
ISO_GPIO_MCU_0_OUT_2: IC402.174 (P5); also elsewhere on the board
ISO_GPIO_MCU_0_OUT_3: IC402.175 (P6); also elsewhere on the board
LSE_1_MCU_0: C428.2, IC402.9 (P14), Q402.1
LSE_2_MCU_0: C429.1, IC402.10 (P15), Q402.2 (3)
MCU_0_NRESET: C425.1, IC402.31 (NRST), R404.1, R405.1, S401.3, S401.4, X403.10
MCU_0_RTC_ALARM_OUT: IC402.8 (P13), X401.3
MCU_0_RTC_WAKEUP_IN: IC402.40 (P0), X401.2
MCU_0_SWCLK: IC402.137 (P14), X403.4
MCU_0_SWDIO: IC402.124 (P13), X403.2
MCU_0_SWO: IC402.161 (P3), X403.6
MCU_0_TDI: IC402.138 (P15), X403.8
MCU_TO_FPGA_INTERFACE_MCU_0_CS: IC402.24 (P6); also elsewhere on the board
MCU_TO_FPGA_INTERFACE_MCU_0_MISO: IC402.26 (P8); also elsewhere on the board
MCU_TO_FPGA_INTERFACE_MCU_0_MOSI: IC402.27 (P9); also elsewhere on the board
MCU_TO_FPGA_INTERFACE_MCU_0_SCK: IC402.25 (P7); also elsewhere on the board
MCU_TO_MCU_INTERFACE_MCU_0_CS: IC402.92 (P12); also elsewhere on the board
MCU_TO_MCU_INTERFACE_MCU_0_MISO: IC402.94 (P14); also elsewhere on the board
MCU_TO_MCU_INTERFACE_MCU_0_MOSI: IC402.95 (P15); also elsewhere on the board
MCU_TO_MCU_INTERFACE_MCU_0_SCK: IC402.145 (P3); also elsewhere on the board
unnamed: C426.1, IC402.125 (VCAP_2)
unnamed: R406.2, S401.1, S401.2
unnamed: LED401.C, R408.2
unnamed: LED402.C, R409.2
unnamed: C427.1, IC402.81 (VCAP_1)
unnamed: IC402.58 (P2), R407.2
unnamed: R403.1, R404.2
unnamed: BATT.+, IC402.6 (VBAT)
RS485_MCU_0_DE: IC402.107 (P3); also elsewhere on the board
RS485_MCU_0_NRE: IC402.106 (P2); also elsewhere on the board
RS485_MCU_0_RX: IC402.150 (P6); also elsewhere on the board
RS485_MCU_0_TX: IC402.42 (P2); also elsewhere on the board
SDCARD_SUPPLY_CONTROL: IC402.33 (P1); also elsewhere on the board
TRACECLK_MCU_0: IC402.1 (P2), X403.12
TRACED0_MCU_0: IC402.2 (P3), X403.14
TRACED1_MCU_0: IC402.3 (P4), X403.16
TRACED2_MCU_0: IC402.4 (P5), X403.18
TRACED3_MCU_0: IC402.5 (P6), X403.20
VDDA_MCU_0: C411.1, IC402.39 (VDDA), L401.2
VREF+_MCU_0: C422.1, C423.1, C424.1, IC401.5 (VOUT_SENSE), IC401.6 (VOUT_FORCE), IC402.38 (VREF+)


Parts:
C501, C505: 18p; C0603
C502, C503, C504, C506, C507, C508, C509, C510, C513: 100n; C0603
C511, C512: 2.2µ; C0603
IC501: STM32F429VIT6; IC_SMD_LQFP100_R_ST_REV01
LED501: Red; CHIP-LED0603
LED502: Green; CHIP-LED0603
Q501: 7B-8.000MAAJ-T; G_SMD_5,00MM_X_3,20MM_0,90MM_(7B)_TXC_REV01
R501, R506: 0; R0603
R502, R504, R505, R507: 10k; R0603
R503: 680; R0603
R508, R509: 130; R0603
S501: KMR211GLFS; S_SMD_4,60MMX2,80MMX1,90MM_R_CK-COMPONENTS_REV01
SV501: MA06-2
T501: BSS84P; V_SMD_SOT23_(TO-236AB)_R_INFINEON_REV01
X501: MA02-1
X502: SAMTEC_FTS_20POL_HEADER_VERTIKAL_REV01; X_SMD_FTS_110-03_(20POL)_R_SAMTEC_REV01

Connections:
+3.3V_1: C502.1, C503.1, C504.1, C506.1, C507.1, C508.1, C510.1, C513.1, IC501.6 (VBAT), IC501.11 (VDD1), IC501.19 (VDD2), IC501.21 (VREF+), IC501.22 (VDDA), IC501.28 (VDD3), IC501.50 (VDD4), IC501.75 (VDD5), IC501.100 (VDD6), R504.2, R505.2, SV501.1, T501.2 (S), X501.1, X502.1; also elsewhere on the board
BMS-INTERFACE_1_GPIO_0: IC501.69 (P10); also elsewhere on the board
BMS-INTERFACE_1_GPIO_1: IC501.70 (P11); also elsewhere on the board
BMS-INTERFACE_1_GPIO_2: IC501.71 (P12); also elsewhere on the board
BMS-INTERFACE_1_GPIO_3: IC501.90 (P4); also elsewhere on the board
BMS-INTERFACE_1_SPI_CS: IC501.29 (P4); also elsewhere on the board
BMS-INTERFACE_1_SPI_MISO: IC501.31 (P6); also elsewhere on the board
BMS-INTERFACE_1_SPI_MOSI: IC501.32 (P7); also elsewhere on the board
BMS-INTERFACE_1_SPI_SCK: IC501.30 (P5); also elsewhere on the board
BOOT_0_MCU_1: IC501.94 (BOOT0), R502.2, T501.3 (D), X501.2
CAN_0_MCU_1_RX: IC501.91 (P5), SV501.4
CAN_0_MCU_1_TX: IC501.52 (P13), SV501.3
DEBUG_LED_0_MCU_1: IC501.18 (P3), LED502.A
DEBUG_LED_1_MCU_1: IC501.17 (P2), LED501.A
FTDI_MCU_1_DTR: R504.1, T501.1 (G); also elsewhere on the board
FTDI_MCU_1_RTS: R501.2; also elsewhere on the board
FTDI_MCU_1_RX: IC501.48 (P11); also elsewhere on the board
FTDI_MCU_1_TX: IC501.47 (P10); also elsewhere on the board
GND_1: C501.1, C502.2, C503.2, C504.2, C505.2, C506.2, C507.2, C508.2, C509.2, C510.2, C511.2, C512.2, C513.2, IC501.10 (VSS1), IC501.20 (VSSA), IC501.27 (VSS2), IC501.74 (VSS3), IC501.99 (VSS4), Q501.2 (GND), Q501.4 (GND), R502.1, R506.1, R507.1, R508.1, R509.1, SV501.2, X502.3, X502.5, X502.9, X502.11, X502.13, X502.15, X502.17, X502.19; also elsewhere on the board
GPIO_MCU_1_0: IC501.83 (P2), SV501.7
GPIO_MCU_1_1: IC501.82 (P1), SV501.8
GPIO_MCU_1_2: IC501.81 (P0), SV501.9
GPIO_MCU_1_3: IC501.80 (P12), SV501.10
GPIO_MCU_1_4: IC501.79 (P11), SV501.11
GPIO_MCU_1_5: IC501.78 (P10), SV501.12
INTERLOCK_CONTROL_MCU_1: IC501.85 (P4); also elsewhere on the board
INTERLOCK_FEEDBACK_MCU_1: IC501.86 (P5); also elsewhere on the board
MCU_1_NRESET: C509.1, IC501.14 (NRST), R503.1, R505.1, S501.3, S501.4, X502.10
MCU_1_SWCLK: IC501.76 (P14), X502.4
MCU_1_SWDIO: IC501.72 (P13), X502.2
MCU_1_SWO: IC501.89 (P3), X502.6
MCU_1_TDI: IC501.77 (P15), X502.8
MCU_TO_MCU_INTERFACE_MCU_1_CS: IC501.51 (P12); also elsewhere on the board
MCU_TO_MCU_INTERFACE_MCU_1_MISO: IC501.53 (P14); also elsewhere on the board
MCU_TO_MCU_INTERFACE_MCU_1_MOSI: IC501.54 (P15); also elsewhere on the board
MCU_TO_MCU_INTERFACE_MCU_1_SCK: IC501.84 (P3); also elsewhere on the board
unnamed: C501.2, IC501.12 (P0), Q501.1 (A)
unnamed: C505.1, IC501.13 (P1), Q501.3 (B)
unnamed: R506.2, S501.1, S501.2
unnamed: LED502.C, R509.2
unnamed: LED501.C, R508.2
unnamed: C511.1, IC501.73 (VCAP_2)
unnamed: C512.1, IC501.49 (VCAP_1)
unnamed: IC501.37 (P2), R507.2
unnamed: R501.1, R503.2
TRACECLK_MCU_1: IC501.1 (P2), X502.12
TRACED0_MCU_1: IC501.2 (P3), X502.14
TRACED1_MCU_1: IC501.3 (P4), X502.16
TRACED2_MCU_1: IC501.4 (P5), X502.18
TRACED3_MCU_1: IC501.5 (P6), X502.20
USART_MCU_1_RX: IC501.87 (P6), SV501.6
USART_MCU_1_TX: IC501.25 (P2), SV501.5


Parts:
C601, C602: 100n; C0603
IC601: ADUM1401ARW; IC_SMD_SOIC-16_(JEDEC_MS-013-AA)_R_ANALOG_REV01

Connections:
+3.3V_0: C601.2, IC601.10 (VE2), IC601.16 (VDD2); also elsewhere on the board
+3.3V_1: C602.1, IC601.1 (VDD1), IC601.7 (VE1); also elsewhere on the board
GND_0: C601.1, IC601.9 (GND2), IC601.15 (GND2); also elsewhere on the board
GND_1: C602.2, IC601.2 (GND1), IC601.8 (GND1); also elsewhere on the board
MCU_TO_MCU_INTERFACE_MCU_0_CS: IC601.12 (VOC); also elsewhere on the board
MCU_TO_MCU_INTERFACE_MCU_0_MISO: IC601.11 (VID); also elsewhere on the board
MCU_TO_MCU_INTERFACE_MCU_0_MOSI: IC601.14 (VOA); also elsewhere on the board
MCU_TO_MCU_INTERFACE_MCU_0_SCK: IC601.13 (VOB); also elsewhere on the board
MCU_TO_MCU_INTERFACE_MCU_1_CS: IC601.5 (VIC); also elsewhere on the board
MCU_TO_MCU_INTERFACE_MCU_1_MISO: IC601.6 (VOD); also elsewhere on the board
MCU_TO_MCU_INTERFACE_MCU_1_MOSI: IC601.3 (VIA); also elsewhere on the board
MCU_TO_MCU_INTERFACE_MCU_1_SCK: IC601.4 (VIB); also elsewhere on the board

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

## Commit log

2017-02-07 Added hardware files.
    [BMS-extension.brd, BMS-extension.csv, BMS-extension.sch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]
2017-03-16 In BMS-Master layout and schematic, fixed Murata NCS6 DC/DC converter library (design rule violation).
    [BMS-master.brd, BMS-master.sch]
2017-05-10 Minor updates and corrections of notations, wording and bill of materials (V1.0.1). No changes in schematic and layout.
    [BMS-extension.csv, BMS-interface.csv, BMS-master.csv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]
2017-05-11 Corrected BOM.
    [foxBMS_BMS-Extension_BOM.xlsx, foxBMS_BMS-Interface_BOM.xlsx, foxBMS_BMS-Master_BOM.xlsx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]
2017-09-04 updated foxBMS-slave to version 2.02
    [foxBMS_BMS-Extension.brd, foxBMS_BMS-Extension.sch, foxBMS_BMS-Extension_BOM.xlsx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]
2017-11-02 updated foxBMS-slave to version 2.1.0
    [foxBMS_BMS-Slave_12cell.brd, foxBMS_BMS-Slave_12cell.sch, foxBMS_BMS-Slave_12cell_BOM.xlsx]

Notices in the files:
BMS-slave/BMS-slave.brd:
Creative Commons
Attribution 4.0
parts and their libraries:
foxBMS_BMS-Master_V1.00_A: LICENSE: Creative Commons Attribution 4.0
